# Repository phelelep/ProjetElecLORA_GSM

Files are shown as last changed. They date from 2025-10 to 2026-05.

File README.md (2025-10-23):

# 🐝 Ruche Connectée – Passerelle LoRa ↔ GSM

Projet réalisé dans le cadre du **cours de Projet d'Électronique** à **Polytech Nice Sophia Antipolis**,  
encadré par **M. Christian Peter** (*Christian.PETER@univ-cotedazur.fr*).

**Groupe :**  
- CEBAN Daniel — [ceban.daniel@etu.univ-cotedazur.fr] 
- MIRRIONE Xavier  — [mirrione.xavier@etu.univ-cotedazur.fr]

---

## 🎯 Objectif du projet

Ce projet vise à concevoir une **ruche connectée** capable de :

- Collecter et transmettre à distance des données environnementales ;  
- Communiquer via une **passerelle LoRa ↔ GSM** ;  
- Intégrer des fonctions avancées comme **l’élimination des parasites par laser**.

Cette partie du projet se concentre sur **la communication à distance** des données.

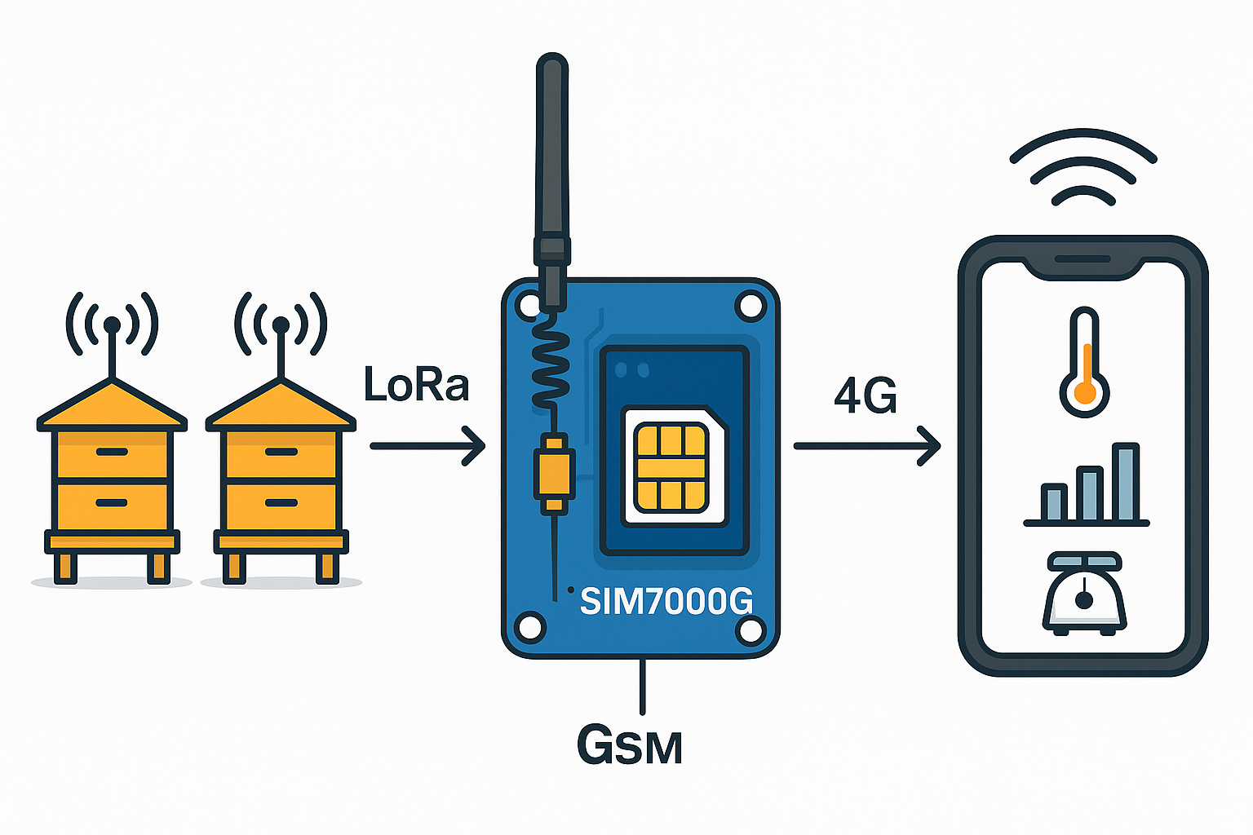
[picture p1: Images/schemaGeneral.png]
Schéma général projet


---

## Dossiers :
- 📁 CompteRendu_Daniel
- 📁 CompteRendu_Xavier
- 📁 Partie_Electronique
- 📁 Partie_Informatique

---

## GLOSSAIRE :

- GSM (Global System for Mobile Communications) :
C'est un standard de communication mobile utilisé pour la téléphonie cellulaire et la transmission de données. Il permet l’envoi de messages SMS, les appels et la connexion à Internet via GPRS/EDGE/3G/4G. Le GSM est largement utilisé pour les dispositifs IoT nécessitant une connectivité dans des environnements sans Wi-Fi.

- LoRa (Long Range) :
C'est une technologie de communication sans fil à longue portée et à faible consommation d'énergie, utilisée pour connecter des dispositifs IoT aux réseaux LPWAN (Low Power Wide Area Network). LoRa permet de transmettre de petits paquets de données sur de longues distances (jusqu'à 15 km en zones rurales) avec une consommation d’énergie minimale.

- ESP32 :
C'est un microcontrôleur développé par Espressif, intégrant Wi-Fi et Bluetooth, ainsi que plusieurs broches GPIO pour les capteurs et modules externes. Il est largement utilisé dans les projets IoT grâce à sa connectivité, sa puissance et son faible coût.
Il va nous permetre de récuperer les information des LoRa et les envoier vers le module GSM pour ensuite transmettre les information au utilisateur.

- SIM7000 :
C'est un module de communication GSM/GPRS/NB-IoT/LTE Cat-M1 développé par Simcom. Il permet aux dispositifs IoT d'envoyer et de recevoir des données via les réseaux mobiles, en prenant en charge les connexions basse consommation, idéales pour les capteurs distants et les applications de surveillance.

---

## 🧩 Technologies utilisées

- **ESP32** – Microcontrôleur principal du système.  
- **SIM7000G** – Module GSM / NB-IoT / LTE pour la communication mobile.  
- **LoRa** – Communication longue portée et faible consommation.  
- **TinyGSM** – Bibliothèque facilitant la communication série avec le SIM7000G.

---

## ⚙️ Fonctionnement général

1. Initialisation et configuration du modem GSM (SIM7000G).  
2. Connexion au réseau mobile via **APN SFR** (`sl2sfr`).  
3. Transmission ou test d’envoi de données / SMS.  
4. Préparation à l’intégration de la communication **LoRa** pour la collecte distante.  

---

## Etapes du projet 

### 🚧 Etape 1:
- Analyse du projet existant et definier les tacher pour continuer le projet. Repartition des taches dans le groupe 

---

## 💡 Référence du projet précédent

Ce projet est basé sur le travail de la promotion précédente :  
**Oumar Sadjo Barry** & **Mor Dieng** – *RucherLoRa*  
- Guilherme Ventapane Rodrigues — [guilherme@ventapane.eu](mailto:guilherme@ventapane.eu)  
- Jarod Lecoeuvre — [jarod.lecoeuvre@etu.univ-cotedazur.fr](mailto:jarod.lecoeuvre@etu.univ-cotedazur.fr)

---

## 🧠 Encadrant

**M. Christian Peter**  
_Enseignant – Département Électronique & Informatique Industrielle_  
[Christian.PETER@univ-cotedazur.fr](mailto:Christian.PETER@univ-cotedazur.fr)

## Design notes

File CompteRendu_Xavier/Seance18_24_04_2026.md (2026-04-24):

# CR - MIRRIONE Xavier  
## Séance 18 du 24/04/2026  

## Reception de la carte
La carte PCB avait été commandée le 11 avril 2026. Elle a bien été reçue, désormais il faut passer à la disposition des composants sur la PCB pour la passer au four et ainsi souder les MCS avec la pate prévue à cet effet. 

Listes des composants posés : 
- C8 10µF et C7 100nF
- ESP32 et LoRa 
- C1, C3 100nF et C2 47µF
- C16 4,7µF et C17 100nF
- R1, R2, R3, R4, R5, R6 100kOhms 
- R21 4,7kOhms 
- R23 150 Ohms et R25 100 Ohms
- R22 1MOhms 
- Q2 et Q4 BSSS131
- BTN RST et PROG
- Q1 et Q3 Si2305
- Soudure DIO1 au GPIO32 avec le jumper

## Test Carte 
Le LoRa et son programme ont été testé, tout est fonctionel. 
### Prochaine séance 
Désormais pour la dernière séance il faut tester le Module GSM, piloter le module  SIM7000 avec le pin 34 CMD_ALIM(SIM) et le mettre à 0. Pour ensuite brancher le 5V.

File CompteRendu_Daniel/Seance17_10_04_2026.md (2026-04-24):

# 📝 Compte Rendu — CEBAN Daniel  
## Séance 17 du 10/04/2026

## objectifs de la séance 

1. Réveiller l'ESP32 lorsque LoRa réceptionne un message
2. Intégration du module SIM7000 au reste du montage

## Étapes de la séance : 

## Etape 1 : réveil via DIO1 

Le problème, c'est qu'après endormissement, l'ESP32 ne se réveille jamais.
```text

LoRa initialized SUCCESSFULLY!
Listening... ESP32 will sleep after 10s of inactivity

[INFO] 10 seconds inactivity → Entering Deep Sleep...
```

On va changer le mode d'endormissement 

On va passer en deep sleep mode 
```cpp
esp_sleep_enable_ext0_wakeup((gpio_num_t)LORA_DIO1, HIGH);
esp_deep_sleep_start();             // L'ESP32 s'endort ici
```
Au light sleep mode 

```cpp
esp_sleep_enable_gpio_wakeup();
gpio_wakeup_enable((gpio_num_t)LORA_DIO1, GPIO_INTR_HIGH_LEVEL);
esp_light_sleep_start();
```

### problème numéro 1 

La ligne int rxState = radio.receive(received); est bloquante.
Par défaut, cette fonction attend qu'un paquet arrive ou qu'un "timeout" interne survienne (souvent plusieurs secondes). Tant que cette fonction n'a pas fini, ton test if (millis() - lastRxTime >= INACTIVITY_TIMEOUT) n'est jamais exécuté. Le processeur est "coincé" dans la lecture radio au lieu de vérifier le chrono.

### solution 
```cpp
  int rxState = radio.receive(received, 0); // 0 time interrupt
```

### problème numéro 2 

Le problème : Les GPIO 34, 35, 36 et 39 de l'ESP32 sont des entrées seules qui n'ont pas de résistances de pull-down internes.

Conséquence : Ta pin est "flottante"
### Solution 
```cpp
#define LORA_NSS 5
#define LORA_DIO1 32  
#define LORA_NRST 27
#define LORA_BUSY 33  
```

### Résultat -> toujours pas de réveil avec LoRa

## Etape 2 : 

On va forcer le pin DIO1 à HIGH avec un câble pour tester si une impulsion sur ce pin réveille bien le module ESP32

Et on arrive à réveiller l'ESP32 avec une impulsion sur le pin GPIO32 (DIO1) 
Donc le problème, c'est le module LoRa qui n'envoie pas d'impulsion sur le DIO1 lors de la réception du message
```text
=== MESSAGE RECEIVED ===
Msg : Hello from Heltec #138 - 2070s
RSSI: -83.00 dBm
SNR : 10.75 dB

[INFO] 10 seconds inactivity → Entering Deep Sleep...

Waked-up after a light sleep!!!

=== MESSAGE RECEIVED ===
Msg : Hello from Heltec #138 - 2070s
RSSI: -83.00 dBm
SNR : 10.75 dB
```

## Etape 3 : Visualiser les signaux à l'aide de l'oscilloscope

1. En visualisant le pin DIO1 de la LoRa sur l'oscilloscope lors de la transmission du message, on remarque qu'il n'y a aucune variation de la tension. Ce qui explique le problème, puisque l'on s'attendait à avoir une interruption sur le DIO1 pour réveiller l'ESP32.

3. Visualisation du pin BUSY sur l'oscilloscope : et cette fois, on voit bien une variation du signal lors de la réception du message. 

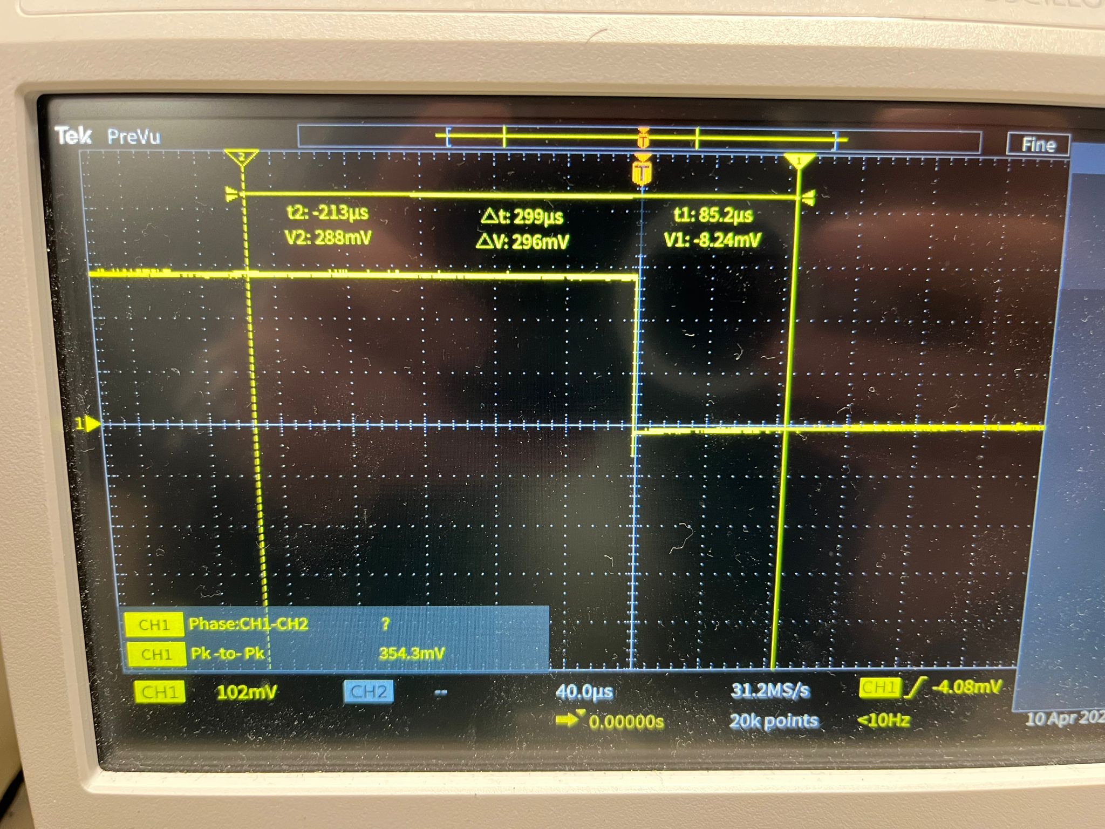
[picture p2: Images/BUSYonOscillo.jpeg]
le pin BUSY sur l'oscilloscope lors de la réception d'un message


DIO1 (Le signal d'événement) : C'est le seul pin capable de signaler une réception de paquet (RxDone). S'il ne bouge pas, ce n'est pas parce qu'il est défectueux, c'est parce que le module n'a pas reçu l'ordre de mapper l'interruption sur ce pin.

Le danger : Utiliser BUSY pour réveiller l'ESP32 ne marchera pas en mode sommeil car, sans activité SPI de l'ESP32, le module n'a aucune raison de passer en état "Busy" (occupé), même s'il reçoit un signal radio.

## Etape 4 : 

1. Quand l’ESP32 est éveillé → le module LoRa montre des variations sur BUSY lors de la réception → tout va bien.
2. Après 10 secondes → l’ESP32 entre en sommeil.
3. Une fois l’ESP32 endormi → plus aucune variation sur BUSY, même si tu envoies un message depuis l’autre module.

-> Le module LoRa perd (ou met en pause) sa configuration lorsque l’ESP32 est en Deep Sleep / Light Sleep.

### Conclusion 

En fait, on a oublié de calibrer le pin DIO1

et d'activer l'interruption 

```cpp

radio.startReceive(RADIOLIB_SX126X_RX_TIMEOUT_INF);
```

## Etape 5 : BINGO!!!

En modifiant le code, on arrive bien à endormir et réveiller l'ESP32 lors de la réception d'un message

```text

=== MESSAGE RECEIVED ===
Msg : Hello from Heltec #64 - 640s
RSSI: -82.00 dBm
SNR : 10.25 dB

[INFO] Inactivité -> Nettoyage et Sommeil...
ESP32 part en sommeil léger. DIO1 devrait rester à 0V...

[SYSTEM] RÉVEIL DÉTECTÉ !

=== MESSAGE RECEIVED ===
Msg : Hello from Heltec #65 - 650s
RSSI: -80.00 dBm
SNR : 10.50 dB
```

Le module LoRa n'était pas correctement configuré juste avant la mise en sommeil de l'ESP32. Plus précisément, le mappage de l'interruption de réception n'était pas forcé sur la pin physique DIO1. De plus, sans un paramètre de timeout infini, le module cessait d'écouter ou levait une erreur de timeout avant l'arrivée d'un message. Résultat : aucune impulsion n'était envoyée sur DIO1 lors de la réception d'un paquet, et l'ESP32 ne recevait jamais le signal électrique nécessaire pour se réveiller

Il est crucial de forcer le signal DIO1 à 0 (état bas) avant l'endormissement (via une commande standby ou un nettoyage des interruptions). Si DIO1 est déjà à 1 au moment où l'ESP32 s'endort, celui-ci ne pourra pas détecter le front montant (le passage de 0 à 1) provoqué par un nouveau message, rendant le réveil impossible.

### Liste de corrections 

1. Mapping matériel : Obligation de lier l'événement "Message reçu" à la broche physique DIO1 avant de couper le SPI.

2. Écoute permanente : Utilisation du mode RX Infini pour éviter que le module ne lève un "faux" signal de timeout qui saturerait la pin.

3. État de repos : Garantie que DIO1 est bien à 0V au repos pour que l'impulsion de 3.3V soit détectable par l'ESP32 comme un événement de réveil.

#### Le code qui fonctionne pour la mise en sommeil 

```cpp
 if (millis() - lastRxTime >= INACTIVITY_TIMEOUT) 
  {
    Serial.println("\n[INFO] Inactivité -> Nettoyage et Sommeil...");
    
    // 1. On s'assure que DIO1 est bien à 0 avant de partir
    radio.standby(); 
    radio.clearDio1Action(); // On enlève l'action actuelle

    // 2. On reconfigure DIO1 pour qu'il ne réagisse QU'AU MESSAGE reçu
    // On ne passe PAS de fonction callback ici pour éviter les conflits au réveil
    // On demande au module de rester en RX permanent
    radio.startReceive(RADIOLIB_SX126X_RX_TIMEOUT_INF);

    delay(100);
    Serial.flush();

    // 3. Configuration du réveil ESP32
    esp_sleep_enable_gpio_wakeup();
    gpio_wakeup_enable((gpio_num_t)LORA_DIO1, GPIO_INTR_HIGH_LEVEL);

    Serial.println("ESP32 part en sommeil léger. DIO1 devrait rester à 0V...");
    esp_light_sleep_start();

    // --- AU RÉVEIL ---
    Serial.println("\n[SYSTEM] RÉVEIL DÉTECTÉ !");
    // On remet l'action pour le loop
    radio.setDio1Action(onPacketReceived); 
    lastRxTime = millis();
  }
```

## Tableau récapitulatif de connectivité (pratique)

| Composant A | Pin A | Composant B | Pin B | Interface |
|---|---|---|---|---|
| ESP32 WROOM | GPIO23 | LoRa LLCC68 | MOSI | SPI |
| ESP32 WROOM | GPIO19 | LoRa LLCC68 | MISO | SPI |
| ESP32 WROOM | GPIO18 | LoRa LLCC68 | SCK | SPI |
| ESP32 WROOM | GPIO5 | LoRa LLCC68 | NSS/CS | SPI |
| ESP32 WROOM | GPIO27 | LoRa LLCC68 | NRST | Contrôle |
| ESP32 WROOM | GPIO32 ou GPIO34 ou GPIO36 | LoRa LLCC68 | DIO1 | IRQ / réveil |
| ESP32 WROOM | GPIO33 ou GPIO35 (tests aussi 36/39/32/25) | LoRa LLCC68 | BUSY | État module |
| ESP32 WROOM | GPIO17 (TX) | SIM7000 | RX | UART |
| ESP32 WROOM | GPIO16 (RX) | SIM7000 | TX | UART |
| ESP32 WROOM | GPIO13 ou GPIO4 | SIM7000 | PWRKEY | Contrôle alim |
| ESP32 WROOM | GPIO25 | SIM7000 | DTR | Gestion modem |
| ESP32 WROOM | 5V/VIN et GND | SIM7000 | VCC et GND | Alimentation |
| ESP32 WROOM | 3.3V et GND | LoRa | VCC et GND | Alimentation |

## Prochain objectif 

1. Nettoyer le code
2. Essais avec le mode **deep sleep** (actuellement on est en mode light_sleep)
2. intégrer le SIM7000G au reste du montage pour faire la chaîne de communication complète

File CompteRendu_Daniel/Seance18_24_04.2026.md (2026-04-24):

# 📝 Compte Rendu — CEBAN Daniel  
## Séance 18 du 24/04/2026

## Objectifs de la séance 

1. Nettoyer le code.
2. Essais avec le mode **deep sleep** (actuellement on est en mode light_sleep).
3. Intégrer le module SIM7000G au reste du montage pour faire la chaîne de communication complète.
4. Test avec la connexion 4G/GSM.

## Étapes de la séance 

## Étape 1 : Test en mode Deep Sleep
Antérieurement nous avons testé le mode `light_sleep`. Maintenant, nous allons passer au mode `deep_sleep` pour économiser davantage d'énergie lors de l'endormissement. On se rapproche ainsi de l'objectif final du projet (optimisation maximale de la consommation).

Lors de la configuration du deep sleep, nous rencontrons un problème :

```text
=== ESP32 <-> LoRa LLCC68 - Wake-up   ===

begin() attempt 1 = -707
begin() attempt 2 = 0
LoRa initialized SUCCESSFULLY!
Listening... ESP32 will sleep after 10s of inactivity

[INFO] Inactivité -> Configuration Deep Sleepou...
ESP32 entering DEEP SLEEP mode... 
ets Jun  8 2016 00:22:57

rst:0x5 (DEEPSLEEP_RESET),boot:0x13 (SPI_FAST_FLASH_BOOT)
configsip: 0, SPIWP:0xee
clk_drv:0x00,q_drv:0x00,d_drv:0x00,cs0_drv:0x00,hd_drv:0x00,wp_drv:0x00
mode:DIO, clock div:1
load:0x3fff0030,len:4744
load:0x40078000,len:15672
```
Lorsque l'ESP32 passe en mode deep sleep, sa sortie de veille effectue un redémarrage (*reboot*) complet. Le message qui a permis de réveiller l'ESP32 n'est donc pas interprété par celui-ci pendant qu'il boot, il est donc perdu. 

**Solution** : Configurer l'autre nœud LoRa (le module HELTEC) pour envoyer un message de réveil (*wake-up*) qui ne contient pas d'information pertinente. Cela permettra juste de réveiller le module ESP32 de l'autre côté par interruption matérielle. 

Ensuite, après un délai, le module HELTEC va envoyer le paquet d'informations cruciales. 

Comme l'initialisation du module LoRa + ESP32 prend environ 2 à 3 secondes après le réveil, nous allons espacer le message de réveil et le message important de 5 secondes pour être sûrs de ne rien rater.

### BINGO !!!

Messages envoyés par l'ESP1 (HELTEC) :
```text
=== Heltec WiFi LoRa 32 V2.1 - Bidirectionnel ===
LoRa initialized successfully !
Envoi toutes les xs + écoute permanente

TX #1 → Wakeup from Heltec #1 - 20s
TX #1 → Hello from Heltec #1 - 25s
→ Envoi OK
```

Messages réceptionnés par l'ESP32 (WROOM) :
```text
=== ESP32 <-> LoRa LLCC68 - Wake-up   ===

begin() attempt 1 = -707
begin() attempt 2 = 0
LoRa initialized SUCCESSFULLY!
Listening... ESP32 will sleep after 10s of inactivity

=== MESSAGE RECEIVED ===
Msg : Hello from Heltec #4 - 85s
RSSI: -74.00 dBm
SNR : 11.00 dB

load:0x40080400,len:3152
entry 0x4008059c

=== ESP32 <-> LoRa LLCC68 - Wake-up   ===

begin() attempt 1 = -707
begin() attempt 2 = 0
LoRa initialized SUCCESSFULLY!
Listening... ESP32 will sleep after 10s of inactivity

=== MESSAGE RECEIVED ===
Msg : Hello from Heltec #5 - 105s
RSSI: -75.00 dBm
SNR : 9.75 dB
```

## Étape 2 : Nettoyage du code
*(À documenter selon les avancées)* 
Nous allons retirer la partie du code qui n'est plus nécessaire et améliorer les messages de log (`print`).

## Étape 3 : Intégration du SIM7000G pour tester la chaîne complète de communication

| Broche ESP32 (WROOM) | Broche SIM7000G | Description de la connexion |
| :--- | :--- | :--- |
| **VIN / 5V** (ou Externe)| **VCC / VIN** | **Alimentation :** Le SIM7000G nécessite une alimentation capable de fournir des pics de courant importants (jusqu'à 2A). SIM7000G elle-même fonctionne techniquement entre 3.0V et 4.3V.s |
| **GND** | **GND** | **Masse commune :** Très important pour unifier les références de tension entre l'ESP32 et le module SIM, surtout si vous utilisez une alimentation externe. |
| **GPIO 16** (RX2) | **TXD** (TX) | **Transmission de données (SIM $\rightarrow$ ESP) :** La broche de réception matérielle (Serial2) de l'ESP32 lit les données envoyées par la broche de transmission du SIM7000G. |
| **GPIO 17** (TX2) | **RXD** (RX) | **Réception de données (ESP $\rightarrow$ SIM) :** La broche de transmission matérielle (Serial2) de l'ESP32 envoie les commandes (AT commands) à la broche de réception du SIM7000G. |
| **GPIO 4** (ou autre) | **PWRKEY** | **Contrôle d'alimentation / Allumage :** Permet à l'ESP32 d'allumer ou d'éteindre le SIM7000G de manière logicielle. Il faut généralement maintenir cette broche à l'état HAUT ou BAS (selon le module) pendant environ 1 seconde pour le démarrer. |
| *Optionnel* (ex: GPIO 5)| **RST** | **Reset (Réinitialisation) :** Permet un redémarrage forcé du modem SIM7000G par l'ESP32 en cas de plantage logiciel. |

### Points d'attention  :
1. Le SIM7000G peut consommer beaucoup d'énergie lors de la connexion au réseau cellulaire. Si l'alimentation chute, le module redémarrera en boucle.
2. L'ESP32 fonctionne en logique **3.3V**. La plupart des modules (breakouts) SIM7000G ont des adaptateurs de niveau logique intégrés. Si votre module SIM fonctionne en logique 5V sans adaptateur, il faudra un *Level Shifter* (convertisseur de niveau logique) sur les broches RX/TX pour ne pas endommager l'ESP32.
3. L'ESP32 dispose de 3 ports série matériels (Hardware Serial). Il est conseillé d'utiliser le `Serial2` (broches 16 et 17) pour le SIM7000G, afin de garder le `Serial0` libre pour le moniteur ordinateur (debogage).

On arrive faire communiquer le ESP32 WROOM et le module SIM7000G
le SIM7000 fonctionne 

```text

--- INFOS DIAGNOSTIC GPRS ---
CCID : 89331054212022311459
IMEI : 869951037002734
Opérateur : SFR
IP locale : 3709934858
Qualité du signal : 99
--- FIN INFOS GPRS ---
```

## Étape 4 : Tests sur la carte électronique 

Mon collègue travaillant en parallèle a conçu la carte électronique (PCB) en reprenant les mêmes broches et la même logique que dans notre montage de test.

Tests avec le PCB imprimé :

### Dépôt de la pâte à braser

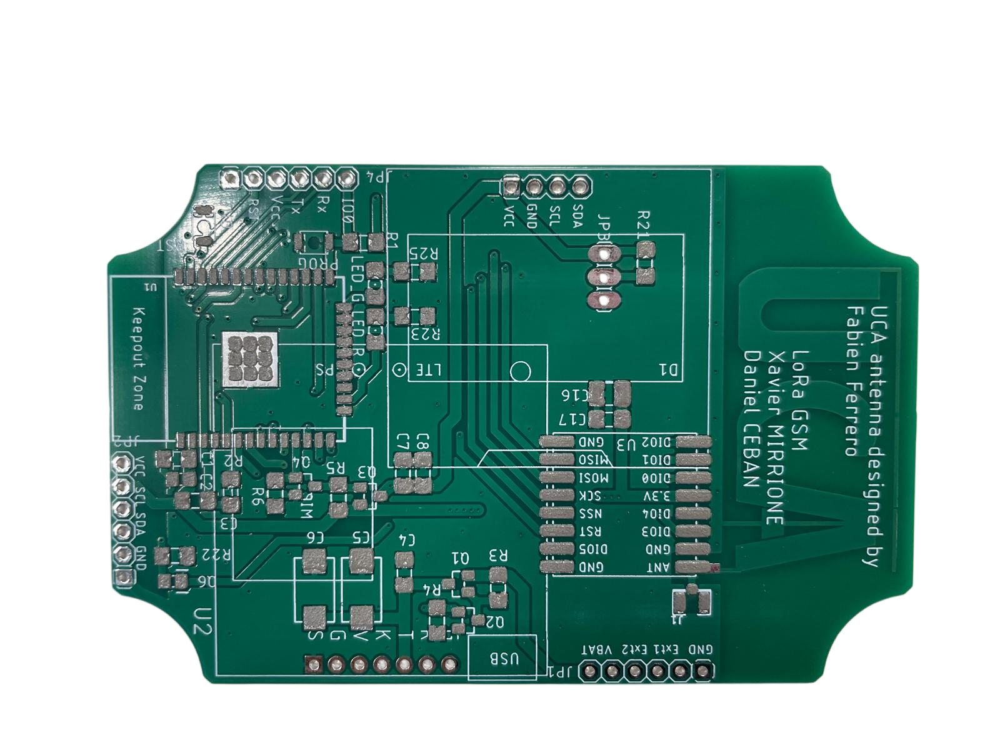
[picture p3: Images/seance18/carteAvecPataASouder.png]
Mise de la pate à souder


### Mise en place des composants
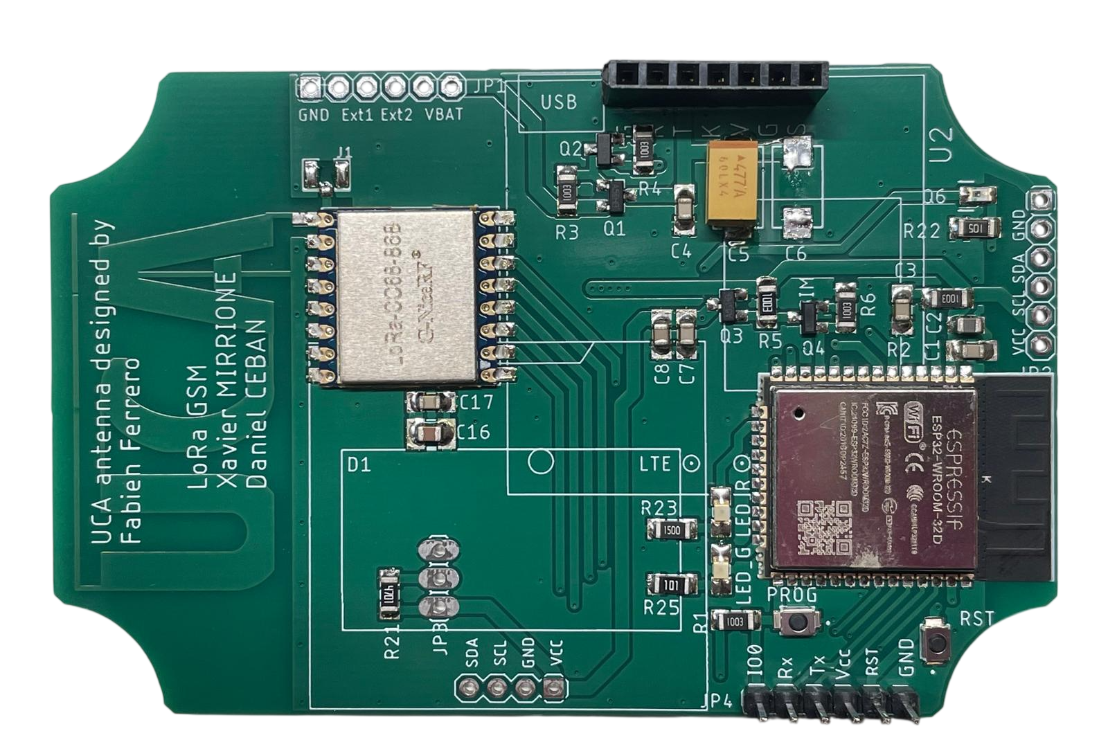
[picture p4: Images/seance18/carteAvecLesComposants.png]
Mise en place de composant


### Passage au four à refusion 
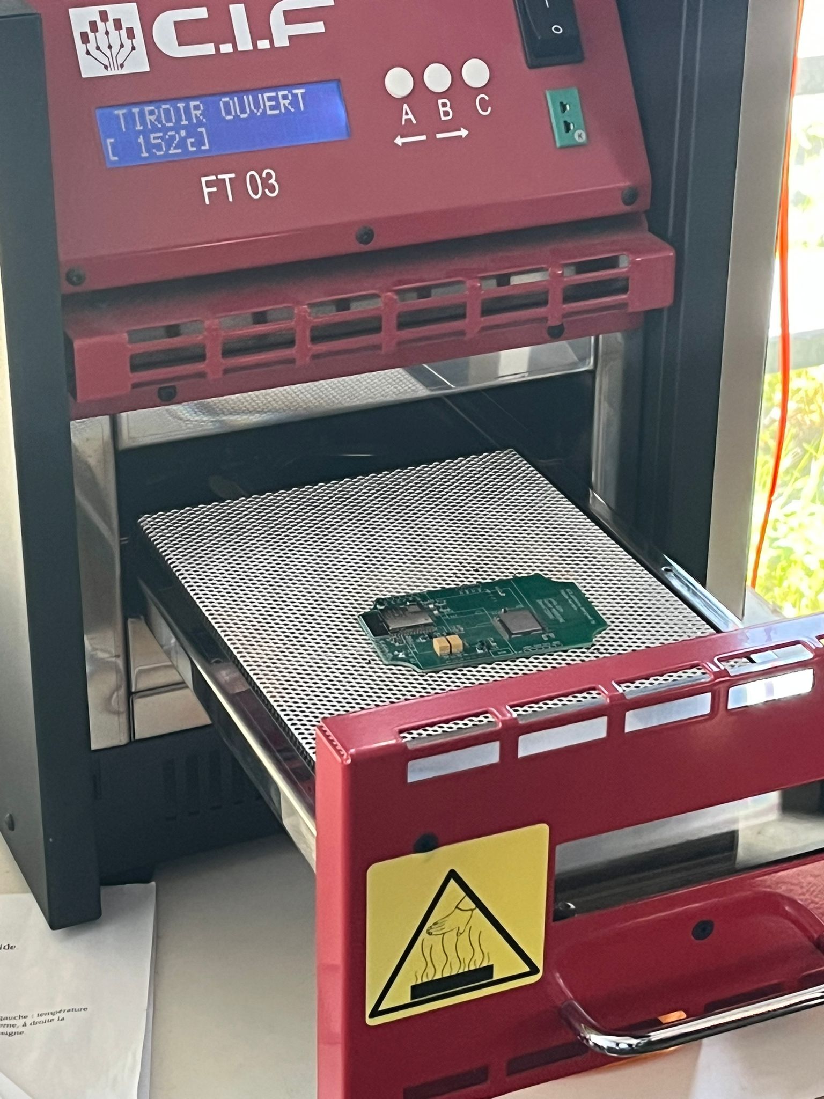
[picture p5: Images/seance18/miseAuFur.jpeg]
Mise de la pate à souder


### Test de la partie LoRa (Succès !) 
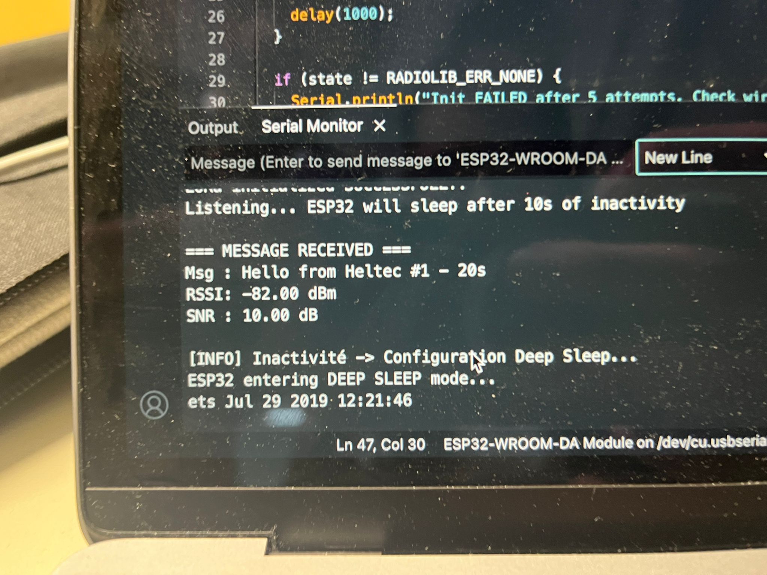
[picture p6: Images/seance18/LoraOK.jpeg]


Nous arrivons bien à réveiller et endormir l'ESP32. Nous considérons donc que la partie LoRa est validée sur la carte. 
Il nous restera par la suite la partie modem GSM à intégrer. 
Celle-ci nécessitant plus de courant, et sachant que nous avons mis en place une broche `ALIM_COMMAND` qui va gérer l'allumage physique, nous devons encore adapter notre alimentation et notre code pour la tester en conditions réelles. 

# Conclusion / Remarques 

- **Partie LoRa fonctionnelle dans son intégralité** sur le PCB $\rightarrow$ OK.
- Il reste à alimenter proprement la partie SIM7000G et à utiliser la broche `ALIM_COMMAND` pour démarrer le modem GSM (au lieu de tirer sur `PWRKEY` comme sur les tests de développement actuels).

Il faudra par la suite fusionner (concaténer) les deux codes :
- Celui qui gère la communication LoRa (sommeil/réveil + réception).
- Celui qui gère la partie modem SIM7000G (envoi HTTP/Mqtt sur le réseau 4G/GSM).

Le plus gros du travail de recherche et de conception étant terminé, et sachant que la partie LoRa matérielle fonctionne, il reste relativement peu de choses pour certifier la partie Modem sur la nouvelle carte. 
Puisque la chaîne de communication complète a d'ores et déjà été testée et validée sur breadboard avec chaque composant individuel, nous sommes confiants quant au bon fonctionnement final du projet. 

Le temps imparti au projet touchant à sa fin, nous concluons nos travaux ici, en espérant que la documentation et les bases solides laissées permettront à une future équipe de reprendre notre projet et de le mener à son terme sans difficulté.

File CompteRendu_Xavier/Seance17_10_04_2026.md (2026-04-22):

# CR - MIRRIONE Xavier  
## Séance 17 du 10/04/2026  

## Routage de la carte
Le routage est terminé ! Tout à été ajusté dont la taille des routes, à 50 mils et non 50 mm. (50 mils = 1,27mm) 

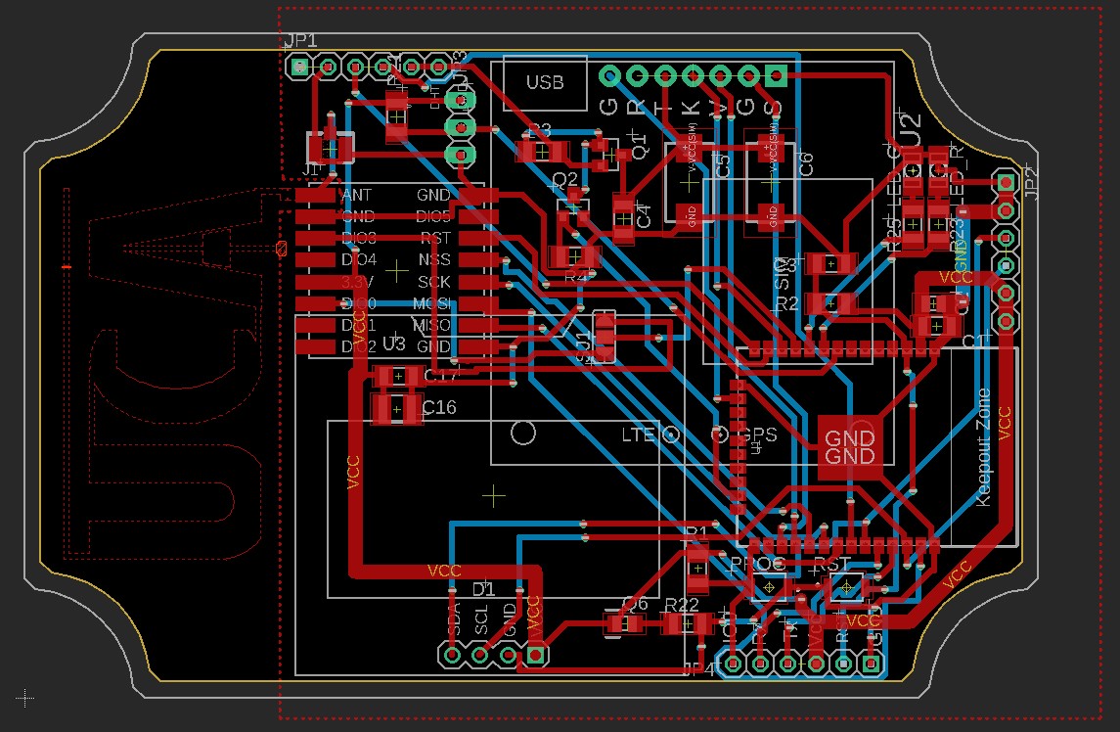
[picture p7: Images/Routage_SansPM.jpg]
Connection des JP1 et JP2


De nombreuses contraintes ont du être respectés, notammement la proximité des condensateurs afin d'éviter toutes perturbation et stabilité de la tension de l'esp32. Mais encore le Lora proche de l'antenne. 

Le projet Eagle va être envoyé au professeur. Il effectuera le plan de masse, et la commande sera faite. D'ici le prochain cours (24 Avril 2026) nous allons pouvoir peut être recevoir la carte PCB. 

Nous réflechissons. Il ne reste que 2 séances il va falloir préparer la soutenance ainsi que le rapport.
Le routage et le schematic vont devoir être ajoutés au dépot github du projet Gateway Lora-GSM.

Les pins doivent être vérifiés avec ceux utilisés expérimentalement par mon camarade. Il n'a fait fonctionné les deux modules qu'individuellement pour le moment et non ensemble.

### Prochainement

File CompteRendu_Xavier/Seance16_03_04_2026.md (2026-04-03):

# CR - MIRRIONE Xavier  
## Séance 16 du 03/04/2026  

## Routage de la carte
Comme spécifié lors de la précédente séance, les dimensions sont les suivantes : 
- 32 mm pour tout
- 50 mm pour l'alim VCC 3V3

Le routage a bien avancé, je vais devoir le finaliser à la maison. Une fois celui-ci terminé je le présenterai au professeur afin de le valider.

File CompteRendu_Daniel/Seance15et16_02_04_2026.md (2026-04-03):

# 📝 Compte Rendu — CEBAN Daniel  
## Séance 15 du 02/04/2026

## Objectif de la séance
1. Tester la communication bidirectionnelle avec 2 ESP32 et leur LoRa.
2. Faire réveiller le module ESP32 avec le module LoRa.
3. Intégrer le module SIM7000 pour envoyer des messages reçus par LoRa vers un téléphone ou un site Internet.

## Étapes de la séance

## Étape 1 : tester la communication bidirectionnelle avec 2 modules ESP32 et leur LoRa

Étapes pour tester :
On va charger exactement le même code sur les deux ESP32 avec leur LoRa.
On va utiliser 2 PC et regarder ce qu'ils envoient et reçoivent sur le Serial Monitor des deux.

Pour un premier test, on va être à une distance entre les deux ESP < 30 cm, puis on va s'éloigner pour voir la distance maximale à laquelle les deux modules reçoivent l'information.

### Problème :
En utilisant **Heltec WiFi LoRa 32**, on n'arrive pas à communiquer avec le composant LoRa à l'intérieur de l'ESP32.
Donc, on va devoir changer et adapter le code pour **Heltec WiFi LoRa 32 V2.1**, qui possède un composant LoRa de type
**SX1276/SX1278**
donc pas compatible avec la bibliothèque <RadioLib.h> ; on va passer à nouveau à la bibliothèque <LoRa.h> et tester.

Avec la bibliothèque <LoRa.h>, on arrive bien à communiquer avec la partie LoRa du module **Heltec WiFi LoRa 32 V2.1**.

## Et BINGO !!!

En allumant les 2 modules :
1. **Heltec WiFi LoRa 32** avec la librairie <LoRa.h>
2. **ESP32 - WROOM** avec la librairie <RadioLib.h>

on arrive à envoyer et réceptionner les messages provenant de l'autre.

```text
-------------------
TX → Test #78 - 567s
→ Envoi OK

RX #38 :
  Message reçu : Hello from Heltec #38 - 190s
  RSSI : -70.00 dBm
  SNR  : 10.00 dB
-------------------
TX → Test #85 - 602s
→ Envoi OK

RX #39 :
  Message reçu : Hello from Heltec #39 - 195s
  RSSI : -70.00 dBm
  SNR  : 10.00 dB
-------------------
TX → Test #86 - 607s
→ Envoi OK

...

RX #6 :
  Message reçu : Hello from Heltec #123 - 615s
  RSSI : -74.00 dBm
  SNR  : 10.25 dB

```

## Étape 2 : implémenter le réveil de l'ESP32 lorsque LoRa réceptionne un message

- Nouvelle implémentation dans le code :

1. Le module LoRa réveille l’ESP32 dès qu’un message arrive (via DIO1).
2. Si aucun message n’arrive pendant 10 secondes, l’ESP32 passe en Deep Sleep (très basse consommation).
3. Au réveil, il reprend l’écoute immédiatement.
4. Si la réception est réussie, il répond avec le numéro du message + "Réception réussie".

On va utiliser le pin GPIO36 pour réveiller l'ESP32.
```cpp
#define LORA_DIO1  36
```

On va ajouter une fonction pour traiter les messages reçus.

```cpp
  // Traitement du paquet si reçu
  if (packetReceivedFlag) {
    packetReceivedFlag = false;
    lastActivity = millis();

    String received = "";
    int rxState = radio.receive(received);

    if (rxState == RADIOLIB_ERR_NONE) {
      Serial.println("\n=== MESSAGE RECEIVED ===");
      Serial.print("Msg  : "); Serial.println(received);
      Serial.print("RSSI : "); Serial.print(radio.getRSSI()); Serial.println(" dBm");
      Serial.print("SNR  : "); Serial.print(radio.getSNR()); Serial.println(" dB");
      Serial.println("-------------------");
    }

    radio.startReceive();  
  }
```

Et une fonction qui va endormir l'ESP32 si les 10 s d'inactivité sont écoulées.

```cpp
 if (millis() - lastActivity >= INACTIVITY_TIMEOUT) {
    Serial.println("\n[INFO] 10 seconds inactivity → Entering Deep Sleep...");

    delay(100);
    Serial.flush();                     // Attendre que le message soit envoyé

    // Désactiver l'action DIO1 avant de dormir
    radio.clearDio1Action();

    // Configurer le wake-up sur DIO1 (niveau HIGH)
    esp_sleep_enable_ext0_wakeup((gpio_num_t)LORA_DIO1, HIGH);

    esp_deep_sleep_start();             // L'ESP32 s'endort ici
  }

```

## Étape 3 : explication du workflow
Le module LoRa (LLCC68) envoie lui-même l’impulsion sur DIO1 dès qu’il reçoit un message valide ; on va utiliser cela pour réveiller l'ESP32.

1. Le module LoRa reçoit un message (qui a été envoyé par une autre LoRa distante) -> le paquet arrive par antenne sur le module LLCC68.
2. Le module LoRa envoie une impulsion (signal) **automatique** sur DIO1 (GPIO 36).
3. L'impulsion réveille l’ESP32 -> parce qu’on a configuré esp_sleep_enable_ext0_wakeup() sur le GPIO36.
4. L’ESP32 traite le message
5. L’ESP32 redémarre le timer d’inactivité -> lastActivity = millis();
6. Si rien n’arrive pendant 10 secondes → L’ESP32 retourne en Deep Sleep.

## Next -> 

vérifier si le révil de ESP32 après la réception du message

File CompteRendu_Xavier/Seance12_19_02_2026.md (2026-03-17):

# CR - MIRRIONE Xavier  
## Séance 12 du 19/02/2026  

## Realisation du schematic

### Définition des pins ESP32 vers connector 1x7 SIM7000G

- VCC vers le 3V3.
- GND au GND.
- SLEEP --> IO2.
- PWRKEY --> IO27.
- TX --> IO17 (RX).  
- RX --> IO16 (TX).

1. Partie ESP32 nu et LoRa
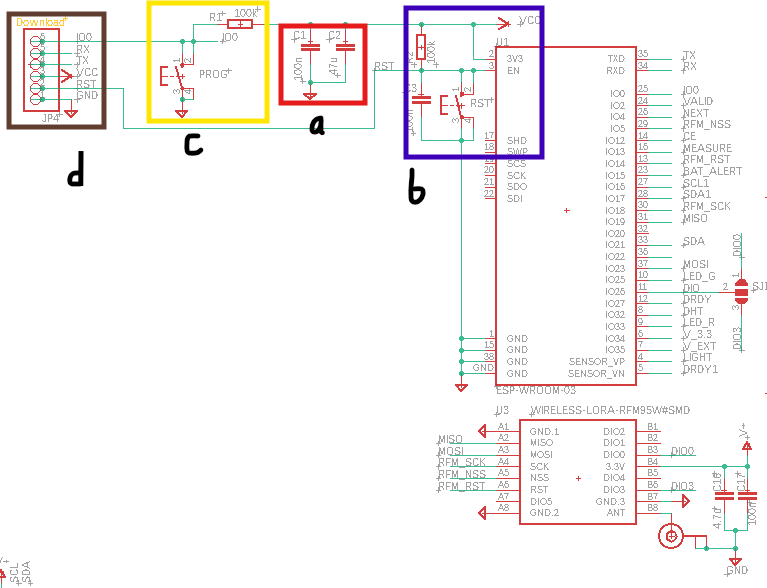
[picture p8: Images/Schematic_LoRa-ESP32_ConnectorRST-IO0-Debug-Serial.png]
Schéma général projet


a) Deux condensateurs de découplage sont placés entre l’alimentation 3,3 V et la masse GND : un 100 nF et un 47 µF. Le grand filtre les parasites haute fréquence et les transitoires rapides au plus près du module, tandis que le 47 µF sert de capacité réservoir pour limiter les chutes de tension lors des pics de courant. 
Ils réduisent l’impédance de l’alimentation et améliorent la stabilité du fonctionnement.

b)La broche EN de l’ESP32 est une entrée hardware d’activation : à l’état haut active le chip, tandis que EN à l’état bas le RESET. 
Pour garantir un démarrage fiable, EN ne doit pas être flottant (en l'air) et doit être validé après stabilisation du 3,3 V. 
On utilise donc un pull-up R2 vers VCC et un condensateur C3 vers la masse formant un RC de temporisation. À la mise sous tension, C3 est initialement déchargé et maintient EN bas brièvement, puis il se charge via R2 et EN monte au niveau haut après un délai de quelques ms. Le bouton RST force EN à 0 V pour réinitialiser manuellement le module et recommencer le processus de charge.

c) La broche IO0 de l’ESP32 est une broche de sélection de mode de boot lue au reset. Une résistance R1 (pull-up) la maintient à l’état haut par défaut afin d’assurer un démarrage normal. Le bouton PROG force IO0 à la masse lorsqu’il est pressé ; si IO0 est maintenu bas pendant un reset, l’ESP32 démarre en mode bootloader UART, ce qui permet le téléversement du programme.

d) Enfin le connecteur JP4 regroupe les signaux nécessaires à la mise au point : TX/RX pour la communication UART (téléversement via bootloader et debug par console série), IO0 pour forcer le mode programmation (BOOT) lorsqu’il est maintenu à 0 durant un reset, RST/EN pour réinitialiser le module, ainsi que VCC et GND pour l’alimentation et la référence de masse. L’interface série doit être utilisée en 3,3 V et les lignes UART sont connectées en croisant TX et RX entre l’adaptateur et la carte.

## Prochainement
- Ajouter un connecteur ou nous pourrons brancher directement le SIM7000G car celui-ci est trop difficile à souder 
- Voir et régler le problème dont ils avaient l'ancien groupe avec le LoRa

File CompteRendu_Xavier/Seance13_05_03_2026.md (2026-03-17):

# CR - MIRRIONE Xavier  
## Séance 13 du 05/03/2026  

## Ajustement et modification du schematic
Changement du pin sleep : IO2 à IO13

On a vérifié la documentation du SIM7000G, sa puce est alimentée en 3V3. Il n'est donc pas nécessaire de l'alimentée en 5V car c'est dans un seul cas d'utilisation alimenté via le module USB directement et non les broches/pins. DONC PAS BESOIN DE LEVEL SHIFTER comme l'ancien groupe avait fait. 

Ajout JP5 vers SIM7000G
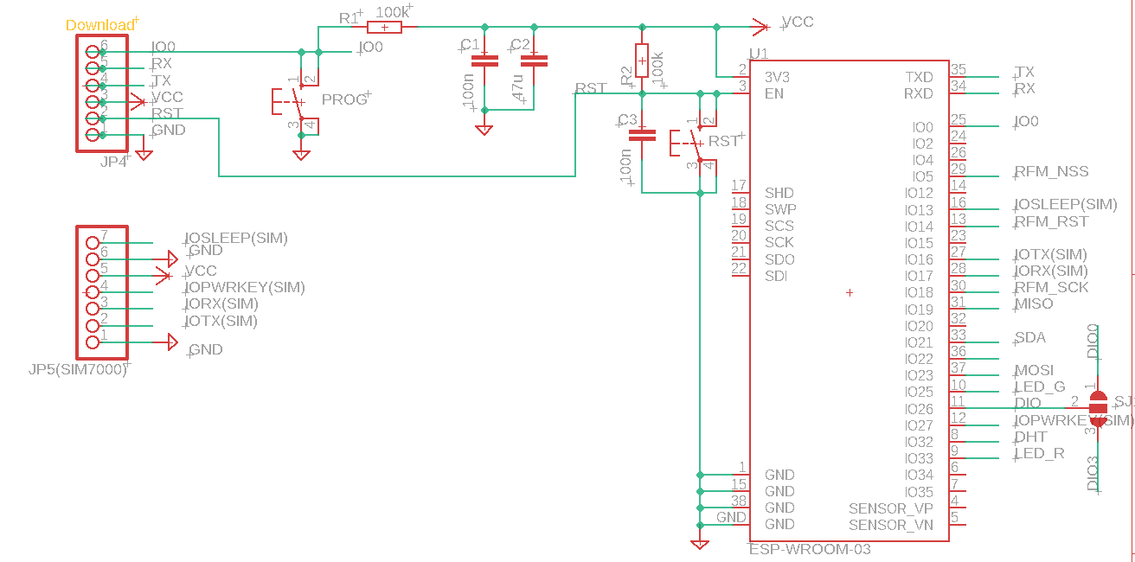
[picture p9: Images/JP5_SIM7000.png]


Dans la Data Sheet, il est spécifié que le mode sleep consomme 1.2 mA. Sur plusieurs heures, c'est conséquent alors afin de réduire sa consommation à zéro lorsqu'il n'est pas utilisé. Un circuit hardware supplémentaire et commandé par une port GPIO supplémentaire de l'ESP32.

Deux transistors Mosfets : 
- NMOS : BSS 131
- PMOS : SI2305

- réalisation du schéma : 
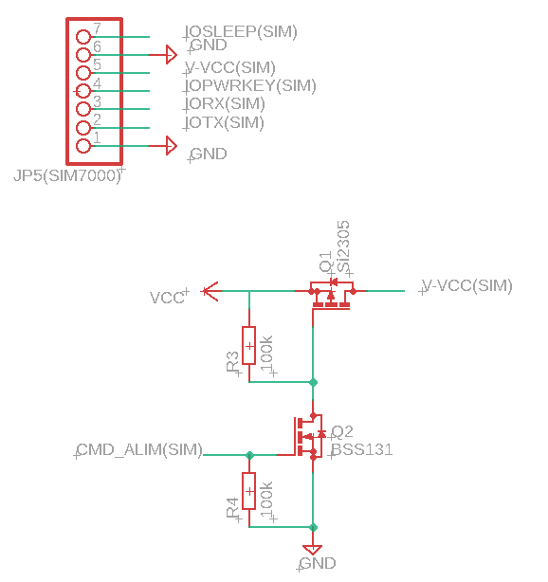
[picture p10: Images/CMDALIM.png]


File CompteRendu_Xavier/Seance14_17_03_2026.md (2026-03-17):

# CR - MIRRIONE Xavier  
## Séance 14 du 17/03/2026  

## Finalisation du schematic

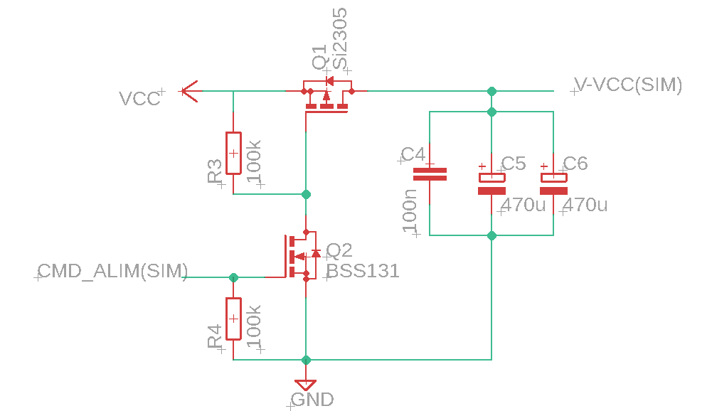
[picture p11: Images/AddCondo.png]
Condo ajout
- réalisation du schéma : 

Trois condensateurs de découplage ont été ajoutés pour le VCC du module SIM7000 afin d’assurer sa stabilité. Le condensateur de 100 nF filtre les perturbations haute fréquence, tandis que les deux condensateurs de 470 µF servent de réserve d’énergie pour absorber les pics de courant importants générés lors des transmissions. Ils permettent ainsi de limiter les chutes de tension transitoires et d’éviter les dysfonctionnements du module pour le protéger.

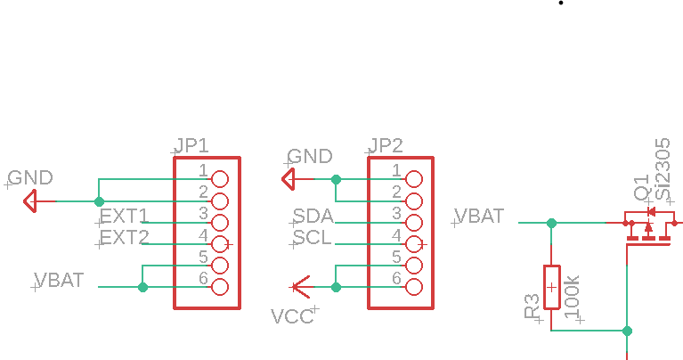
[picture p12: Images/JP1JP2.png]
Connection des JP1 et JP2

Afin d'accepter la futur présence de la batterie dans la cadre d'un jointement entre ce projet et le notre, les deux connecteurs JP1 et JP2 ont été réliés. 

Réalisation du schematic est terminée à 100%. Désormais il faut passer à la réalisation de la board tout en respectant certaines conditions qui seront détaillées lors du prochain rapport.

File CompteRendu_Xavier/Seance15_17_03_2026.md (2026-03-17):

# CR - MIRRIONE Xavier  
## Séance 15 du 17/03/2026  

## Installation EAGLE - License Student
Précédemment la version du logiciel intallé était Eagle via une license Free. Malheureusement la taille autorisée pour la modification et la réalisation du routage d'une board est limité en taille max d'un composant que l'on peut déplacer. 
Il a fallu installer de nouveau Fuzion, activer la license sudent afin de commencer le routage. 

## Conditions à respecter 
Comme expliqué dans les premiers rapports, un projet de batterie 3V3 d'une autre équipe sera utilisé comme source d'alimentation de notre carte pour le Lora-GSM

## Prise en main Eagle et disposition des composants
Il faut respecter la disposition des condensateur permettant d'éviter les chutes de tensions, C1, C2 doivent rester proche de l'esp tandis que C5,C6 proche de VCC du Sim7000G. 
Le professeur à effectuer une empreinte du SIM7000G afin d'imaginer la place qu'il pourrait prendre, une fois brancher au JP5.

La disposition des composants pour le routage est presque terminée.

### Pour la prochaine séance
Le routage va être fait : 
- 32 mm pour tout
- 50 mm pour l'alim VCC 3V3

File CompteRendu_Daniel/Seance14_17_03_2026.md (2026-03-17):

# 📝 Compte Rendu — CEBAN Daniel  
## Séance 14 du 17/03/2026

### Problématique
On n'arrive pas à communiquer avec le module **LoRa-CC68-868 G-NiceFR**.

### Objectif
Changer le module **LoRa-CC68-868 G-NiceFR** avec le module **LoRa RF96** et utiliser la bibliothèque `LoRa.h` et non `RadioLib.h`.

---

## Étapes de la séance 

### Étape 1 : Changement de la puce et intégration sur la breadboard

La plupart des pins restent à la même place, à part la pin BUSY qu'on enlève car on n'en a pas besoin.
La bibliothèque `LoRa.h` est conçue uniquement pour les puces de la famille SX127x.

#### Résultat : Échec !

```text
Test LoRa.h - SX127x seulement !
Échec LoRa.begin()
```

### Étape 2 : Retour au module initial

Le but est de tester `RadioLib.h` et d'enquêter davantage sur l'erreur -707.

Après vérification des pins et modification de certains branchements, on obtient toujours la même erreur -707. Les raisons suspectées sont :
- La patte **BUSY**
- La patte **DIO1**

En effet, en retirant ce branchement, on reçoit toujours l'erreur -707. Ce n'est pas le cas en retirant une autre patte : on reçoit alors l'erreur -2, ce qui indique que le module n'est pas du tout connecté.

#### Observations avec les différentes bibliothèques

**Avec `LoRa.h` et le module RF96 (type SX127x) :**
Le module LLCC68 ne répond pas. La fonction `begin()` ne renvoie aucun code d'erreur, ce qui rend difficile l'investigation ultérieure.

**Avec `RadioLib.h` :**
- Erreur -707 (SPI_CMD_FAILED) quand DIO1 + BUSY sont branchés
- Erreur -2 quand on enlève d'autres pins (NSS/NRST/SPI)

Cela signifie que la communication SPI de base fonctionne (la puce répond), mais une commande spécifique échoue pendant l'initialisation (calibration, configuration des IRQ ou contrôle du TCXO).

Les pattes BUSY et DIO1 sont bien connectées et les pins GPIO utilisés sont compatibles et vérifiés.

#### Autres causes possibles

1. **Alimentation bruitée** : Les puces LLCC68 sont très sensibles aux micro-défaillances de tension pendant les phases critiques de l'initialisation.
2. **Module défectueux**.

### Étape 3 : Vérification du pin BUSY 
On va tester si on peut forcer le pin busy à 1 pour voir s'il n'y a pas d'erreur du hardware ou dans le circuit 

On change le LORA_BUSY pin sur le GPIO33 qui peut être output aussi ça va nous permettre de le forcer à HIGH pour voir s'il change ou non 
```cpp
  pinMode(LORA_BUSY, OUTPUT); // GPIO33 output & input mode
// test high

  Serial.println("put busy to high...");
  digitalWrite(LORA_BUSY, HIGH);
  Serial.println(digitalRead(LORA_BUSY));
// test low
  Serial.println("put busy to low...");
  digitalWrite(LORA_BUSY, LOW);
  Serial.println(digitalRead(LORA_BUSY));
 
```

#### Résultat 

```text
set busy to high...
1
set busy to low...
0

Maintenant begin()...
begin() = -707
```

on arrive bien à changer le pin busy à 1.

#### Test avec différents paramètres 

on va changer la valeur de la tension tcxo 

```text
BUSY actuel : 0

[TEST 94] Test → Freq=867.0 MHz | BW=62.5 kHz | SF=7 | CR=4/5 | Sync=0x14 | Pwr=17 dBm | Preamble=12 | TCXO=1.6
Hard reset effectué
 → begin() = -8
Échec. Code = -8
BUSY actuel : 0

[TEST 95] Test → Freq=867.0 MHz | BW=62.5 kHz | SF=7 | CR=4/5 | Sync=0x14 | Pwr=17 dBm | Preamble=12 | TCXO=1.8
Hard reset effectué
 → begin() = -8
Échec. Code = -8
BUSY actuel : 0
```
Cependant, dans tous les tests, si la valeur de TCXO n'est pas 0.0f, on obtient un code d'erreur -8, ce qui signifie que ce paramètre n'est pas valide par la bibliothèque `RadioLib.h`.

```cpp

#include <RadioLib.h>

#define LORA_NSS   5
#define LORA_DIO1  36
#define LORA_NRST  27
#define LORA_BUSY  33

LLCC68 radio = new Module(LORA_NSS, LORA_DIO1, LORA_NRST, LORA_BUSY);

void setup() {
  Serial.begin(115200);
  delay(2000);

  pinMode(LORA_NRST, OUTPUT);
  pinMode(LORA_DIO1, INPUT);
  pinMode(LORA_BUSY, INPUT);

  Serial.println("\n=== Multiple LLCC68 begin() tests (10 cases) ===\n");

  // Reset once at beginning
  digitalWrite(LORA_NRST, LOW);
  delay(50);
  digitalWrite(LORA_NRST, HIGH);
  delay(500);
  Serial.print("BUSY after initial reset: "); Serial.println(digitalRead(LORA_BUSY));

  // --- 10 relevant test cases ---
  int testNum = 0;

  // Test 1: Safe default (most common working config)
  testNum++;
  Serial.print("\nTest "); Serial.print(testNum); Serial.println(": Safe default (BW125/SF9/CR7/TCXO0)");
  int state = radio.begin(868.0, 125.0, 9, 7, 0x12, 10, 8, 0.0f);
  Serial.print("begin() = "); Serial.println(state);
  Serial.print("BUSY now: "); Serial.println(digitalRead(LORA_BUSY));
  delay(1500);

  // Test 2: Same but LDO instead of DC-DC
  testNum++;
  Serial.print("\nTest "); Serial.print(testNum); Serial.println(": Same + LDO mode");
  state = radio.begin(868.0, 125.0, 9, 7, 0x12, 10, 8, 0.0f, false);
  Serial.print("begin() = "); Serial.println(state);
  delay(1500);

  // Test 3: TCXO 1.6 (just to confirm -8 again)
  testNum++;
  Serial.print("\nTest "); Serial.print(testNum); Serial.println(": TCXO 1.6 (should give -8)");
  state = radio.begin(868.0, 125.0, 9, 7, 0x12, 10, 8, 1.6f);
  Serial.print("begin() = "); Serial.println(state);
  delay(1500);

  // Test 4: Lower SF (SF7)
  testNum++;
  Serial.print("\nTest "); Serial.print(testNum); Serial.println(": SF7");
  state = radio.begin(868.0, 125.0, 7, 7, 0x12, 10, 8, 0.0f);
  Serial.print("begin() = "); Serial.println(state);
  delay(1500);

  // Test 5: Higher SF (SF11 – still valid for 125 kHz)
  testNum++;
  Serial.print("\nTest "); Serial.print(testNum); Serial.println(": SF11");
  state = radio.begin(868.0, 125.0, 11, 7, 0x12, 10, 8, 0.0f);
  Serial.print("begin() = "); Serial.println(state);
  delay(1500);

  // Test 6: Wider BW 250 kHz + SF9 (valid combo)
  testNum++;
  Serial.print("\nTest "); Serial.print(testNum); Serial.println(": BW250/SF9");
  state = radio.begin(868.0, 250.0, 9, 7, 0x12, 10, 8, 0.0f);
  Serial.print("begin() = "); Serial.println(state);
  delay(1500);

  // Test 7: BW500 + SF8 (valid)
  testNum++;
  Serial.print("\nTest "); Serial.print(testNum); Serial.println(": BW500/SF8");
  state = radio.begin(868.0, 500.0, 8, 7, 0x12, 10, 8, 0.0f);
  Serial.print("begin() = "); Serial.println(state);
  delay(1500);

  // Test 8: Different coding rate (4/8)
  testNum++;
  Serial.print("\nTest "); Serial.print(testNum); Serial.println(": CR=4/8");
  state = radio.begin(868.0, 125.0, 9, 8, 0x12, 10, 8, 0.0f);
  Serial.print("begin() = "); Serial.println(state);
  delay(1500);

  // Test 9: Different sync word (0x14)
  testNum++;
  Serial.print("\nTest "); Serial.print(testNum); Serial.println(": Sync=0x14");
  state = radio.begin(868.0, 125.0, 9, 7, 0x14, 10, 8, 0.0f);
  Serial.print("begin() = "); Serial.println(state);
  delay(1500);

  // Test 10: Longer preamble (12 symbols)
  testNum++;
  Serial.print("\nTest "); Serial.print(testNum); Serial.println(": Preamble=12");
  state = radio.begin(868.0, 125.0, 9, 7, 0x12, 10, 12, 0.0f);
  Serial.print("begin() = "); Serial.println(state);
  delay(1500);

  Serial.println("\n=== All 10 tests finished ===");
}

void loop() {
  // empty
}
```

### resultat du test 

```text
Test 1: Safe default (BW125/SF9/CR7/TCXO0)
begin() = -707
BUSY now: 0

Test 2: Same + LDO mode
begin() = -707

Test 3: TCXO 1.6 (should give -8)
begin() = 0

Test 4: SF7
begin() = -707
```

Bizarement on trouve pas d'erreur pour une valeur de TCXO 1.6F. 
On en conclut donc quenotre module  G-NiceRF LoRa-CC68-868 module a un TCXO (temperature-compensated crystal oscillator)
et il attend **1.6V sur le DIO3**

Cependant si on fait tourner le test 3 individuellement on trouve tujour l'erreur -707 ce qui est anormal.
en testant avec multiples valeur de TCXO on voit que l'initiliation à marche pour un valeur de TCXO de 1.8 et 2.4 

```text
=== Multiple LLCC68 begin() tests  ===
Test 1 : TCXO 1.6 
begin() = -707
Test 2: TCXO 1.8 begin() = 0
Test 3: TCXO 2.4 begin() = 0
Test 4: TCXO 0.0 begin() = -707
```

En retirant le test 1 qui teste que la valeur de 1.6 on obtien ce resultat 

```text
=== Multiple LLCC68 begin() tests  ===
Test 2: TCXO 1.8 begin() = -707
Test 3: TCXO 2.4 begin() = 0
Test 4: TCXO 0.0 begin() = -707
```

Le resultat n'est pas logique mais on peut supposer que lorsqu'on fait le test 1 avec 1.6V et on recoit l'erreur 707 ca permet au module de faire une configuration initiale même si l'erreur est de 707 ca parmet par la suite d'initialized le composant sans erreur 

pour tester ca on va executer 3 fois **le même test** avec une valeur de TCXO de 1.6 on s'addent a ce qu'on ait une erreur lors du premier test et pas d'erreur lors de 2 suivants 

```text
=== Multiple LLCC68 begin() tests  ===

BUSY after initial reset: 0
Test 1: TCXO 1.6 begin() = -707
Test 3: TCXO 1.6 begin() = 0
Test 4: TCXO 1.6 begin() = 0
```

C'est exactement le resultat qu'on attendant 

#### Pourquoi le premier appel à begin() avec TCXO = 1.6f échoue (-707), alors que le deuxième et le troisième réussissent (0) :
Le premier appel démarre à partir d’un état complètement inconnu ou non initialisé du circuit (après la mise sous tension ou un reset matériel).
Le composant LLCC68 a besoin que la tension du TCXO soit correctement configurée avant que l’oscillateur à quartz puisse se stabiliser et que la calibration puisse s’exécuter.
Lors de la première tentative, la bibliothèque essaie de configurer le TCXO à 1,6 V, mais l’oscillateur interne n’a pas encore démarré ou est dans un mauvais état → la commande de calibration échoue → renvoie -707.
Une fois qu’une première configuration réussit (le deuxième appel renvoie 0), le circuit est correctement initialisé (TCXO activé, oscillateur verrouillé, calibration effectuée).
Les appels suivants partent alors d’un état déjà correct → ils reconfigurent simplement les paramètres sans devoir refaire toute la séquence TCXO/calibration → ils réussissent immédiatement.

### Etape 4 : tester la reception et l'envoi des messages LoRa <-> ESP32

code pour INITIALISER -> envoyer -> ecouter les messages 
```cpp
#include <RadioLib.h>

#define LORA_NSS   5
#define LORA_DIO1  36
#define LORA_NRST  27
#define LORA_BUSY  33

LLCC68 radio = new Module(LORA_NSS, LORA_DIO1, LORA_NRST, LORA_BUSY);

unsigned long lastTx = 0;
const unsigned long TX_INTERVAL = 5000;  // send every 5 seconds

void setup() {
  Serial.begin(115200);
  delay(2000);

  pinMode(LORA_NRST, OUTPUT);
  pinMode(LORA_DIO1, INPUT);
  pinMode(LORA_BUSY, INPUT);

  Serial.println("\n=== Multiple LLCC68 begin() tests  ===\n");

  // Reset once at beginning
  digitalWrite(LORA_NRST, LOW);
  delay(50);
  digitalWrite(LORA_NRST, HIGH);
  delay(500);
  Serial.print("BUSY after initial reset: "); Serial.println(digitalRead(LORA_BUSY));

  int state= -1; 
  // tester jussq'au succes
  while (state != RADIOLIB_ERR_NONE)
  {
    state = radio.begin(868.0, 125.0, 9, 7, 0x12, 10, 8, 1.6f);
    Serial.print("begin() = "); Serial.println(state);
    if (state == RADIOLIB_ERR_NONE) 
      Serial.print("Initialization SUCCESS! - code : "); Serial.println(state);
    else 
       Serial.print("Init FAILED - code "); Serial.println(state);
    delay(1500);
  }

  // Start continuous receive mode
  radio.startReceive();
  Serial.println("Listening for packets...");
}

void loop() {
  // Send periodically
  if (millis() - lastTx >= TX_INTERVAL) {
    lastTx = millis();

    String message = "Hello from ESP32 at " + String(millis() / 1000) + "s";

    Serial.print("Sending: "); Serial.println(message);

    int state = radio.transmit(message);

    if (state == RADIOLIB_ERR_NONE) {
      Serial.println("→ Sent OK");
    } else {
      Serial.print("→ Send failed, code "); Serial.println(state);
    }
  }

  // Check for incoming packet
  String received = "";
  int state = radio.receive(received);

  if (state == RADIOLIB_ERR_NONE) {
    // Packet received!
    Serial.println("Received packet:");
    Serial.print("  Message: "); Serial.println(received);
    Serial.print("  RSSI: "); Serial.print(radio.getRSSI()); Serial.println(" dBm");
    Serial.print("  SNR: "); Serial.print(radio.getSNR()); Serial.println(" dB");
    Serial.println();
  } else if (state != RADIOLIB_ERR_RX_TIMEOUT) {
    // Some error (not just timeout)
    Serial.print("Receive error, code "); Serial.println(state);
  }

  // Small delay to avoid CPU hogging
  delay(10);
}
```

Réponse : OK 

```text
=== Multiple LLCC68 begin() tests  ===

BUSY after initial reset: 0
begin() = -707
Init FAILED - code -707
begin() = 0
Initialization SUCCESS!
0
Listening for packets...
Sending: Hello from ESP32 at 5s
→ Sent OK
Sending: Hello from ESP32 at 14s
→ Sent OK
```

### Etape 5 : on va utiliser tester communication bidirectionnel ESP32<-> ESP32

le but dans cette etape etant de verifier la reception d'un message provenant du module Heltec WiFi LoRa 32 

- on va faire tourner les deux cartes en même temps 
- avec le même code 

#### Resultat attendu 
 les messages envoyer par l'un doivent être visibles par l'autre dans le serial monitor 

#### Description du processus de communication entre les deux ESP32
- Les deux ESP32 ne sont pas reliés par fil (pas d'I2C, UART, USB, etc.).
Ils communiquent uniquement par ondes radio LoRa via leurs antennes.

- Chaque ESP32 + module LoRa a une petite antenne 868 MHz .
Quand un côté envoie, l'énergie RF sort par l’antenne → se propage dans l’air (jusqu’à plusieurs centaines de mètres en extérieur, 50–200 m en intérieur selon puissance et environnement).
L’autre côté reçoit ce signal grâce à son antenne → le module LoRa le décode → le passe à l’ESP32.

et c'est en foncitonn de la frequence qu'on a arrive à se synchroniser sur le deux EPS32 en même temps 

L’antenne capte le signal RF (ondes électromagnétiques à 868 MHz).

## objectif prochain -> tester la communication bidirectionnele 
## objectif prochain -> faire reveiller le module ESP32 avec le module LoRa
## integrer le module SIM7000 pour envoyer des messages recues par LoRa vers un téléhpone ou un site internet

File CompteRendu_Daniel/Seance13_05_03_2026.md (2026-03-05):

# 📝 Compte Rendu — CEBAN Daniel  
## Séance 13 du 5/03/2026 

---

## Problématique 
On n'arrive pas à communiquer avec le module LoRa en utilisant la librairie  **<RadioLib.h>**

---

## Objectifs

1. Changer le module **LoRa-CC68-868 G-NiceFR** et utiliser la bibliothèque **<LoRa.h>** 

2. Integration du module SIM7000G avec ESP32 nu

### Etape 1. coder avec la bibliothèque <LoRa.h>
On va utiliser la fonction **begin(long frequency)** pour initialiser la communication avec le module LoRa

```cpp
int LoRaClass::begin(long frequency)
{
#if defined(ARDUINO_SAMD_MKRWAN1300) || defined(ARDUINO_SAMD_MKRWAN1310)
  pinMode(LORA_IRQ_DUMB, OUTPUT);
  digitalWrite(LORA_IRQ_DUMB, LOW);

  // Hardware reset
  pinMode(LORA_BOOT0, OUTPUT);
  digitalWrite(LORA_BOOT0, LOW);

  pinMode(LORA_RESET, OUTPUT);
  digitalWrite(LORA_RESET, HIGH);
  delay(200);
  digitalWrite(LORA_RESET, LOW);
  delay(200);
  digitalWrite(LORA_RESET, HIGH);
  delay(50);
#endif

  // setup pins
  pinMode(_ss, OUTPUT);
  // set SS high
  digitalWrite(_ss, HIGH);

  if (_reset != -1) {
    pinMode(_reset, OUTPUT);

    // perform reset
    digitalWrite(_reset, LOW);
    delay(10);
    digitalWrite(_reset, HIGH);
    delay(10);
  }

  // start SPI
  _spi->begin();

  // check version
  uint8_t version = readRegister(REG_VERSION);
  if (version != 0x12) {
    return 0;
  }

  // put in sleep mode
  sleep();

  // set frequency
  setFrequency(frequency);

  // set base addresses
  writeRegister(REG_FIFO_TX_BASE_ADDR, 0);
  writeRegister(REG_FIFO_RX_BASE_ADDR, 0);

  // set LNA boost
  writeRegister(REG_LNA, readRegister(REG_LNA) | 0x03);

  // set auto AGC
  writeRegister(REG_MODEM_CONFIG_3, 0x04);

  // set output power to 17 dBm
  setTxPower(17);

  // put in standby mode
  idle();

  return 1;
}
```

#### Résultat : Echec 

on remarque dans le code de la bibliotheque LoRa que si la version du module n'est pas la 12 le code va toujours retourner la valeur 0 

```cpp
if (version != 0x12) {
    return 0;
  }
```

On va utiliser un code pour diagnostiquer la version actuelle du notre module 

```cpp
  digitalWrite(LORA_NSS, LOW);
  SPI.transfer(0x42 & 0x7F); // Adresse de lecture pour SX127x
  uint8_t version = SPI.transfer(0x00);
  digitalWrite(LORA_NSS, HIGH);
  Serial.print("Réponse du registre 0x42 (Version) : 0x");
  Serial.println(version, HEX);
```

#### Résultats de la version : 
```text
--- Diagnostic du module LoRa ---
Réponse du registre 0x42 (Version) : 0xAA
```
#### Conclusion 
1. La réponse du registre nous permet de dire qu'on arrive bien à communiquer avec le module 
2. La version 0xAA nous permet pas de communiquer avec le module LoRa (car le code nécessite la version 0x12)

### Etape 2
Utilisation d'une carte qui integre le module **EPS32** nu et le module **RF96** on va utiliser une connecteur UART pour tester la carte 

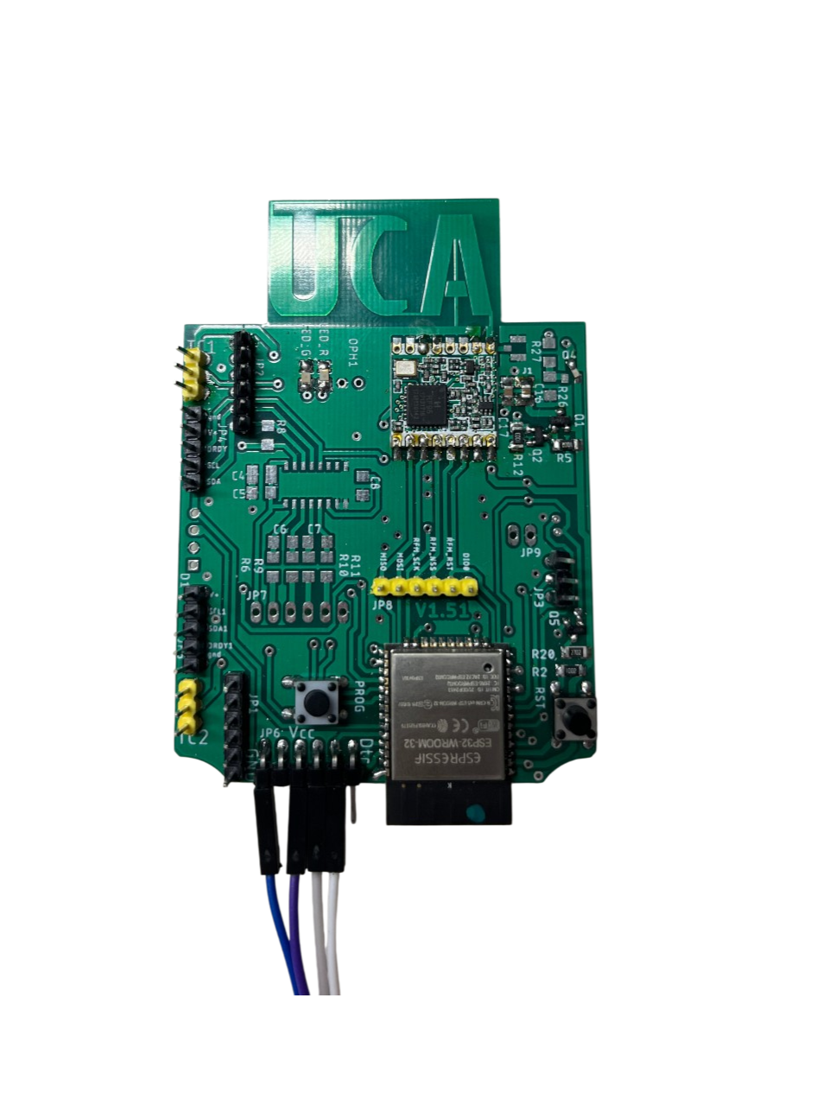
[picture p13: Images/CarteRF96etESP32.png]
Utilisation d'une nouvelle carte


### remarque 
on doit déclarer le GPIO13 en sortie et le mettre à HIGH

voici le code qu'on utiliser pour tester la nouvelle carte 

```cpp
#include <LoRa.h>
// Définition des broches selon votre montage
#define SCK     18
#define MISO    19
#define MOSI    23
#define NSS      5
#define RST     27
#define DIO0    34

#define ENABLE 13
void setup() {
  Serial.begin(115200);
  while (!Serial);
   pinMode(ENABLE, OUTPUT);
  digitalWrite(ENABLE, HIGH);
  LoRa.setPins(NSS, RST, DIO0);
  // 2. Initialiser la fréquence (868 MHz pour l'Europe)
  if (!LoRa.begin(868E6)) {
    Serial.println(F("ÉCHEC ! Le module ne répond pas. Vérifiez le câblage SPI."));
    while (1);
  }
  Serial.println("Succes");
}
```

### resultat 
```text
mode:DIO, clock div:1
load:0x3fff0030,len:4980
load:0x40078000,len:16612
load:0x40080400,len:3480
entry 0x400805b4
E BOD: Brownout detector was triggered
```

#### interprétation 
ESP32 redémarre parce que la tension chute brutalement
#### solution 
Brancher la carte sur une alimentation fixé qui va livrer une ampérage plus importante

#### Resultat BINGO!!!

```text
rst:0x3 (SW_RESET),boot:0x12 (SPI_FAST_FLASH_BOOT)
configsip: 0, SPIWP:0xee
clk_drv:0x00,q_drv:0x00,d_drv:0x00,cs0_drv:0x00,hd_drv:0x00,wp_drv:0x00
mode:DIO, clock div:1
load:0x3fff0030,len:4980
load:0x40078000,len:16612
load:0x40080400,len:3480
entry 0x400805b4
Succes

```

### Etape 4. plan d'action

le but étant de faire fonctionner le composant LoRA-CC68. Avec la carte précédente on a vu qu'on peut utiliser le module <LoRa.h> pour faire fonctionner un module LoRa cependant il est compatible seulement avec une puce de version 0x12. Or notre carte a une version 0xAA. 

Par la suite on va donc revenir à la bibliothèque <RadioLib.h> plus complète et plus bavarde (nous indique les codes erreurs). On va donc essayer de faire fonctionner le composant LoRA-CC68 avec l'ancien brochage.

### Etape 5. retester l'ancien câblage avec Module LoRA et ESP32

```text
=== LLCC68 Init Test (XTAL mode) ===
Pins: NSS=5 DIO1=34 NRST=27 BUSY=35
Initial BUSY state: 0
[LLCC68] begin() returned: -707
FAILED – code -707
```

Toujours la même erreur on arrive à detecter le moduole mais on ne recoit aucune réponse (erreur 707) 

Investigation par la suite... 

### Etape 3. Integration du module SIM 7000G avec l'ESP32 nu 

Schéma de connexion (Câblage UART). Le SIM7000G communique SPI

| SIM7000G Pin | ESP32 GPIO | Fonction | Note |
|---|---|---|---|
| VCC | 5V / VIN | Alimentation | Attention : Doit fournir 2A en pointe ! |
| GND | GND | Masse commune | Indispensable pour la communication. |
| TX | GPIO 16 (RX2) | Données SIM -> ESP | |
| RX | GPIO 17 (TX2) | Données ESP -> SIM | |
| PWRKEY | GPIO 4 | Allumage | Nécessite une impulsion basse pour démarrer. |

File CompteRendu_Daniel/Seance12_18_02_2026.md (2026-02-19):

# 📝 Compte Rendu — CEBAN Daniel  
## Séance 12 du 18/02/2026 

---

## Problématique 
Code -707 : RADIOLIB_ERR_INVALID_BUSY_STATE -> on n'arrive pas à communiquer avec le module LoRa

---

## Objectifs

Résoudre les problèmes de câblage pour communiquer avec LoRa sinon passer à la partie suivante et commencer la communication entre le module SIM7000 et ESP32 nu.

---

## Étapes de la séance 

---

### Étape 1 : Investigation

Retour d'une IA

```text
The error code is officially RADIOLIB_ERR_SPI_CMD_FAILED (-707) in current RadioLib versions. The library docs say exactly this:
"Often this means that the module is trying to use TCXO while XTAL is connected (or vice versa)."
```

### Ajout de deux condensateurs de découplage 

1. on va ajouter un condensateur chimique de 10 µF entre le VCC et le GND de la partie LoRa
2. pour plus d'efficacité on va rajouter un condensateur de 98 nF céramique en parallèle avec l'autre 

-> Résultat toujours l'erreur 707 -> RADIOLIB_ERR_SPI_CMD_FAILED

### Changement de câblage 

On va mettre le BUSY (patte 16) du Module LoRa sur le GPIO 36, et on va essayer également les GPIO 39, 33, 32 et 25 

### Etape 2 Passer à la suite 

#### Résultat final après plusieurs tentatives, changements dans le code et 3 séances sans résultat. 

On n'arrive pas à communiquer avec le module LoRa la carte est detecté par le module ESP32 mais ils n'arrivement aps à communiquer -> erreur -707. toute tentation de recablage ou de changment dans le code à donne le même code erreur on va donc faire quelques changements dans notre projet.

On va donc reprendre un autre module **RFM (SX1276)** qui a un modem LoRa intégré -> 
en utilisant la bibliothèque "LoRA" -> https://github.com/sandeepmistry/arduino-LoRa/tree/master

-> TODO demander le module RFM

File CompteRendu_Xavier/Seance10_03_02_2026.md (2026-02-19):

# CR - MIRRIONE Xavier  
## Séance 10 du 03/02/2026  

Installation d'autodesk Eagle sur le PC pour la réalisation schématic de la carte de la gateway.

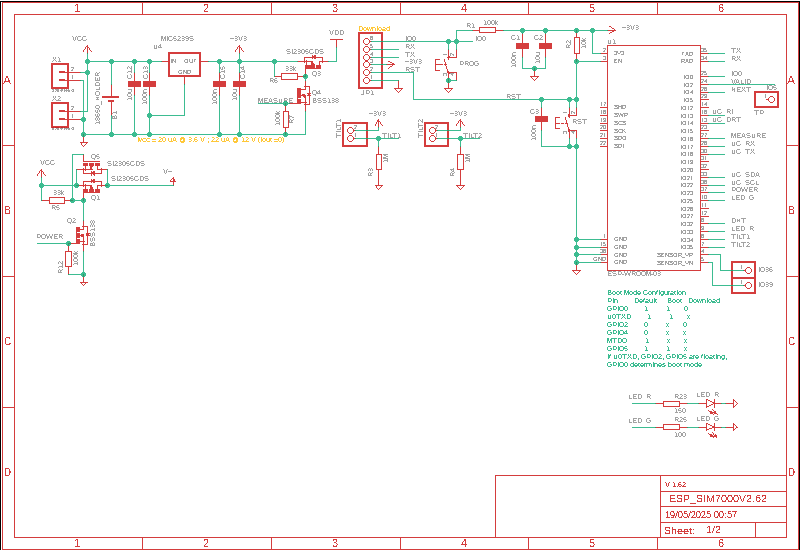
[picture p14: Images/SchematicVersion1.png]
Schéma général projet


Voici la première version établie par l'ancien groupe, les deux leds ont été gardées. Il manque encore la photo résistance afin d'avoir le mode jour / nuit. Mais il faut aussi changer l'ESP32, celui dont il disposait possédait un LoRa intégré. Dans notre cas celui-ci est séparé.

## Prochainement
- Avancer le schématic = ajouter un sheet pour le SIM7000G
- Définir les pins nécessaires pour le cablage sur la plaque labdec
- Voir et régler le problème dont ils avaient l'ancien groupe avec le LoRa

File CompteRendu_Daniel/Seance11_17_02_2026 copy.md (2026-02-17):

# 📝 Compte Rendu — CEBAN Daniel  
## Séance 11 du 17/02/2026 

### Problematique 
Le code toujours = -2 
ce qui signifique que le module ESP32 ne trouve pas le module LoRa
Tension qui arrive sur module LoRa = **2.9 V** (pas assez ? )

#### Solutions possibles 

1. On va connecter les 2 autres messes du module LoRa à la masse communice pour être sûr 
2. On va founir la tension 3.3 V à partir d'un générateur de tension stable. pour être sûr qu'on a du 3.3V sur le LoRa est le module ESP32.

3. Si ca ne fonctionne pas on va alors ajouter des condensateurs de découplage.

## Objectif de la séance 

Comprendre pourquoi on n'arrive pas à communiquer avec le module LoRa et éventuellement résoudre le problème pour établir une communication entre le module **ESP32** et le module **LoRa**

---

### Problematique 
Le code toujours = -2 
ce qui signifique que le module ESP32 ne trouve pas le module LoRa
Tension qui arrive sur module LoRa = **2.9 V** (pas assez ? )

---

#### Solutions possibles 

1. On va connecter les 2 autres messes du module LoRa à la masse communice pour être sûr 
2. On va founir la tension 3.3 V à partir d'un générateur de tension stable. pour être sûr qu'on a du 3.3V sur le LoRa est le module ESP32.

3. Ajouter des condensateurs de découplage.

---

## Étapes de la séance 

### Étape 1 : Changer la source de tensions

On va donc connecter le générateur de tension aux modules LoRa et ESP32 pour s'assurer qu'on a bien une tension de 3.3 V à l'entrée des deux modules 

On va aussi relier les 3 masses du module LoRa à la masse principale. 

On essaye de démarrer une dernière fois avec le connecteur USB serial SPI qui fournit 3.3 V et on a ce message 

```text

Panic handler entered multiple times. Abort panic handling. Rebooting ...
Panic handler entered multiple times. Abort panic handling. Rebooting ...
ets Jun 8 2016 00:22:57
rst:0x7 (TG0WDT_SYS_RESET),boot:0x13 (SPI_FAST_FLASH_BOOT)
configsip: 0, SPIWP:0xee
clk_drv:0x00,q_drv:0x00,d_drv:0x00,cs0_drv:0x00,hd_drv:0x00,wp_drv:0x00
mode:DIO, clock div:1
load:0x3fff0030,len:4980
load:0x40038000,len:232
load:0x4000c44c,len:1073676304
1162 mmu set 00010000, pos 00010000
1162 mmu set 00020000, pos 00020000
```

#### Explication possible 

L'adaptateur FTDI (la carte rouge) ne peut pas fournir assez de courant stable. La tension chute, la mémoire flash renvoie n'importe quoi (d'où le len énorme), et l'ESP32 panique.

#### Test avec générateur 3.3V 

Après avoir généré la tension de 3.3 avec le générateur on a toujours une erreur de comm entre LoRa et ESP32
```text
--- Test de communication ESP32 <-> LoRa CC68 ---
[LLCC68] Initialisation... ÉCHEC. Code erreur : -2
Erreur: Le module ne répond pas
```

#### Vérification de la tension aux bornes du LoRa

La tension à l'entrée des deux composants LoRa et ESP32 est bien de 3.3 (plus précisément 3.299)

### Vérification du câblage et remplacement de câbles

Après avoir remplacé certains câbles on arrive à recevoir une nouvelle erreur

```text
--- Test de communication ESP32 <-> LoRa CC68 ---
[LLCC68] Initialisation... ÉCHEC. Code erreur : -707

```
L'erreur -707
est spécifique à la bibliothèque RadioLib. Elle correspond à RADIOLIB_ERR_CHIP_NOT_FOUND

### Changement de la carte LoRa CC68-868 GNiceRF -> LoRa GNice

Avec la nouvelle carte on a l'erreur -2 

Code -2 : RADIOLIB_ERR_CHIP_NOT_FOUND
C'est une erreur de connexion totale.

2. Code -707 : RADIOLIB_ERR_INVALID_BUSY_STATE (Spécifique LLCC68/SX126x)
C'est une erreur de dialogue bloqué.

On va revenir à l'ancienne carte alors 

### Utiliser les broches 32 (BUSY) et 33 (DIO1) à la place. Elles possèdent des résistances internes qui stabilisent le signal.

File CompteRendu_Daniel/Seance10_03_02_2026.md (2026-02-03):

# 📝 Compte Rendu — CEBAN Daniel  
## Séance 10 du 03/02/2026 

---

## 🔴 Problématique rencontrée lors de la dernière séance 
On n'arrive plus à faire télécharger du code sur le module **ESP32** même en faisant le câblage avec le module ESP32 seul 

## 🎯 Objectif de la séance 
⚠️ Comprendre pourquoi le module ESP32 ne fonctionne plus ?
- Problème du câblage ? 
- Module défectueux ? 
- Mauvaise manipulation des boutons. 
Ajouter le module LoRa et vérifier l'intégralité du montage 

## 📋 Étapes de la séance 

### Étape 1 : Vérification de la carte ESP32 🔍

Après recâblage on retrouve une autre erreur de téléversement 
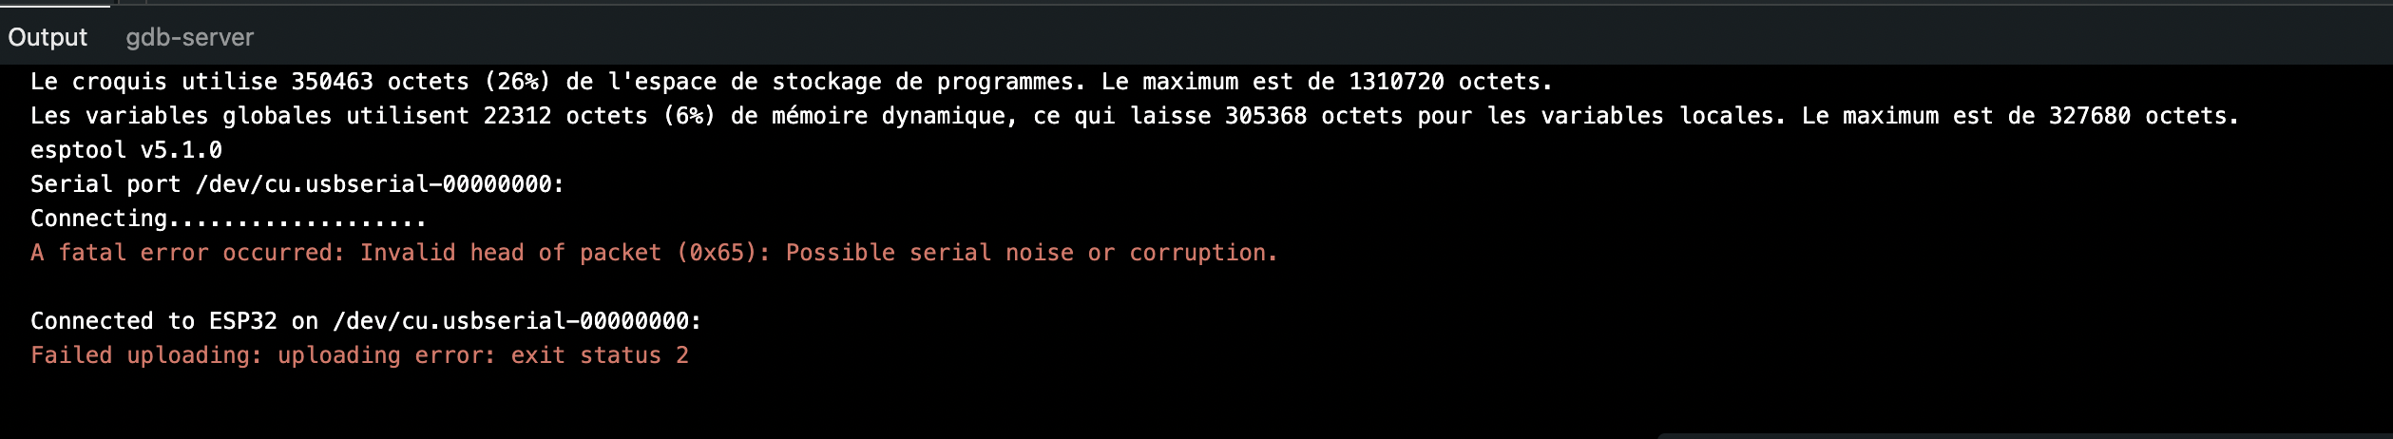
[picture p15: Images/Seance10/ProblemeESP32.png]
Problème téléversement


On a retesté avec la bonne séquence d'appuyer sur le bouton et cette fois ça marche 

1. Appuyer sur le bouton téléverser le programme
2. Maintenir le bouton RST enfoncé 
3. Lorsque on voit le message "Connecting..." En maintenant le bouton RST appuyer sur le bouton PRG pour une courte période 
4. Relâcher les deux boutons 

Voici le câblage actuel :

| Composant | Départ | Arrivée | Note |
| --- | --- | --- | --- |
| Alimentation | Sortie 3.3V de l'USB | Broche 2 (3V3) | JAMAIS de 5V sur cette broche ! |
| Masse | GND de l'USB | Broche 1 (GND) |  |
| Série TX | TX de l'USB | Broche 40 (RXD0) | Inversion standard (TX vers RX) |
| Série RX | RX de l'USB | Broche 41 (TXD0) | Inversion standard (RX vers TX) |
| Pull-up EN | Broche 9 (EN) | 3.3V | Via ta résistance $100k\Omega$ |
| Pull-up GPIO0 | Broche 23 (GPIO0) | 3.3V | Via ta résistance $100k\Omega$ |

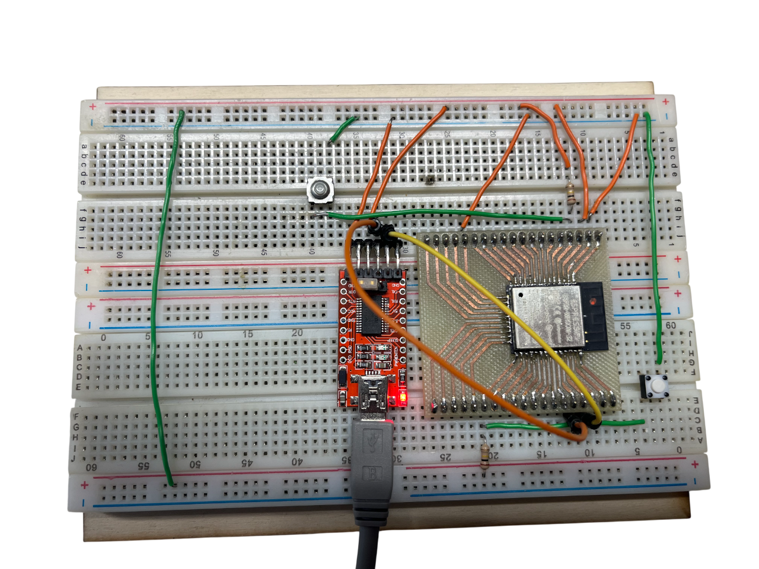
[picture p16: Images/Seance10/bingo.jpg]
Montage qui marche


```text
rst:0x1 (POWERON_RESET),boot:0x13 (SPI_FAST_FLASH_BOOT)
configsip: 0, SPIWP:0xee
clk_drv:0x00,q_drv:0x00,d_drv:0x00,cs0_drv:0x00,hd_drv:0x00,wp_drv:0x00
mode:DIO, clock div:1
load:0x3fff0030,len:4980
load:0x40078000,len:16612
load:0x40080400,len:3480
entry 0x400805b4
=======================================
   TEST DIAGNOSTIC ESP32 REUSSI !
=======================================
Frequence CPU : 240 MHz
L'ESP32 tourne depuis : 0 secondes.
L'ESP32 tourne depuis : 1 secondes.
```

### Étape 2 : Connecter le module LoRa

On a câblé le module LoRa et exécuté un code qui peut vérifier que l'ESP32 est bien relié à un module LoRA.

Voici le code qui permet de vérifier si le module LoRa est bien connecté.

```cpp
#include <RadioLib.h>
// NSS: 5, DIO1: 34, NRST: 27, BUSY: 35
LLCC68 radio = new Module(5, 34, 27, 35);

void setup() {
  Serial.begin(115200);
  delay(2000); // Laisse le temps au port série de s'ouvrir

  Serial.println(F("\n--- Test de communication ESP32 <-> LoRa CC68 ---"));
  Serial.print(F("[LLCC68] Initialisation... "));
  int state = radio.begin(868.0);

  if (state == RADIOLIB_ERR_NONE) {
    Serial.println(F("SUCCÈS !"));
    Serial.println(F("Le module LoRa répond et le câblage SPI est correct."));
  } else {
    Serial.print(F("ÉCHEC. Code erreur : "));
    Serial.println(state);
    
    // Aide au diagnostic
    if (state == -2) Serial.println(F("Erreur: Le module ne répond pas"));
    if (state == -70) Serial.println(F("Erreur: Broche BUSY bloquée. Vérifiez le GPIO 35."));
    
    while (true); // Bloque ici si ça ne marche pas
  }
}
```

Erreur lors de l'exécution du code
```text
configsip: 0, SPIWP:0xee
clk_drv:0x00,q_drv:0x00,d_drv:0x00,cs0_drv:0x00,hd_drv:0x00,wp_drv:0x00
mode:DIO, clock div:1
load:0x3fff0030,len:4980
load:0x40078000,len:16612
load:0x40080400,len:3480
entry 0x400805b4

--- Test de communication ESP32 <-> LoRa CC68 ---
[LLCC68] Initialisation... ÉCHEC. Code erreur : -2
Erreur: Le module ne répond pas. Vérifiez le câblage et l'alimentation 3.3V.

```

### Problematique 
Le code toujours = -2 
ce qui signifique que le module ESP32 ne trouve pas le module LoRa
Tension qui arrive sur module LoRa = **2.9 V** (pas assez ? )

#### Solutions possibles 

1. On va connecter les 2 autres messes du module LoRa à la masse communice pour être sûr 
2. On va founir la tension 3.3 V à partir d'un générateur de tension stable. pour être sûr qu'on a du 3.3V sur le LoRa est le module ESP32.

3. Si ca ne fonctionne pas on va alors ajouter des condensateurs de découplage.

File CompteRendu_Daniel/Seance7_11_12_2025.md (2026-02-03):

# 📝 Compte Rendu — CEBAN Daniel  
## Séance7  du 11/11/2025 

---
## Objectif de la seance 
Câbler un ESP32 (sans le module LoRA) et un module LoRa pour implémenter une fonctionnalité de réveil de l'ESP32 en utilisant seulement le module LoRa.
---

## Etape 1 Câblage ESP32->PC 
- Le but de cette étape de de verifier la connexion EPS32 -> PC 
- Vefirier le fontionnement de buttons 
- Télécharger un programme sur le ESP32

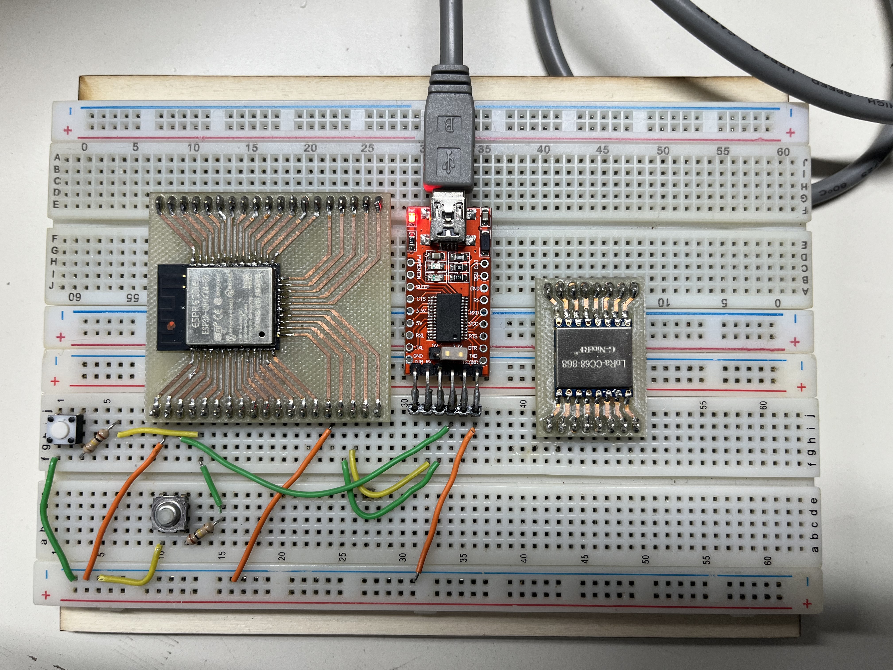
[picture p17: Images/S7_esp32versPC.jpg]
1 version câblage
 

### probleme 

```text
Connecting......................................
A fatal error occurred: Failed to connect to ESP32: No serial data received.
For troubleshooting steps visit: https://docs.espressif.com/projects/esptool/en/latest/troubleshooting.html

Failed uploading: uploading error: exit status 2
````
Explications 
```text
Le bouton "PRG" sur le GPIO 36 c'est une erreur. Le GPIO 36 est une broche d'entrée seulement (Sensor VP), elle ne sert jamais au démarrage.
```

Troubleshoting 
```text
Pour mettre l'ESP32 en mode "Téléchargement" (Download Mode), l'ESP32 regarde l'état de la broche GPIO 0 au moment exact où il démarre.

- Si GPIO 0 est connecté à la masse (GND) au démarrage -> L'ESP32 attend le code (Mode Flash).
- Si GPIO 0 est connecté au 3.3V (HIGH) au démarrage -> L'ESP32 lance le programme (Mode Normal).
```
Si les boutons sont mal câblés (surtout le GPIO 0), l'IDE Arduino n'arrivera jamais à se connecter. Il affichera une erreur du type "Timed out waiting for packet header".

### Cablage correct 

1. Button "RST" :
 - Connecter une résistance de 100kΩ entre EN et 3.3V. (Pour garder la puce allumée par défaut).
 - Connecte ton bouton poussoir entre EN et GND. (Appuyer dessus redémarre la puce).

2. Button "PRG" :
 - Connecte une résistance de 100kΩ entre GPIO 0 et 3.3V.
 - Connecte ton bouton poussoir entre GPIO 0 et GND.

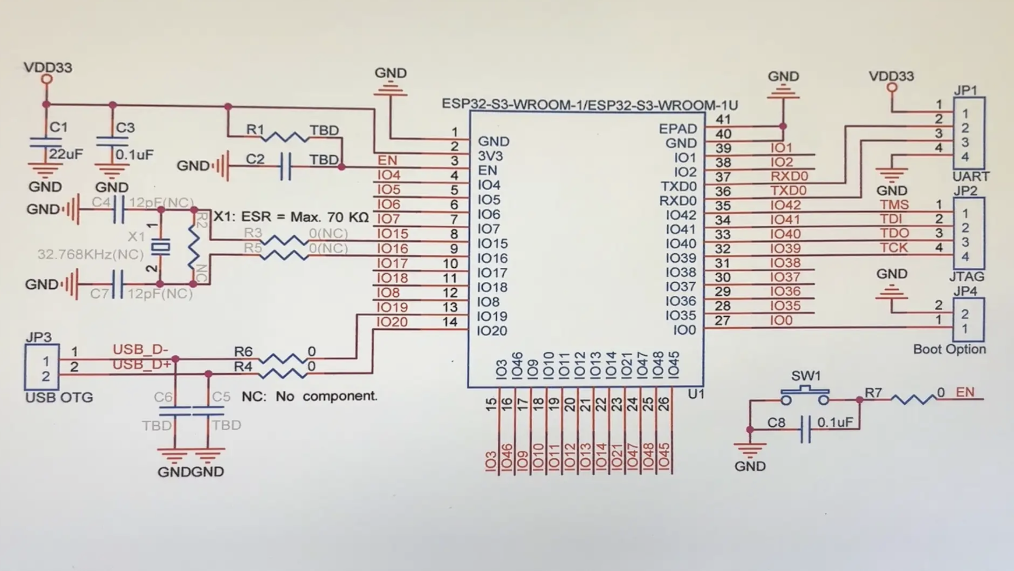
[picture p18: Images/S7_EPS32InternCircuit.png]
Circuit interne du ESP32 nu
 

### 2 problem RX et TX mouvais câblage

Apres avoir connecte le 2 button on s'est rendu compte qu'on doit utilier le button 
- TX de la pâte 41 du ESP32
- RX de la pâte 40 du ESP32 

Voic le câblage EPS32 nu -> qui marche 

### Bingo !!!
On arrive a télécharger les donnes vers ESP32
```text
Connecting.....
Connected to ESP32 on /dev/cu.usbserial-00000000:
Chip type:          ESP32-D0WDQ6 (revision v1.0)
Features:           Wi-Fi, BT, Dual Core + LP Core, 240MHz, Vref calibration in eFuse, Coding Scheme None
Crystal frequency:  40MHz
MAC:                24:6f:28:20:8f:20

Uploading stub flasher...
Running stub flasher...
```

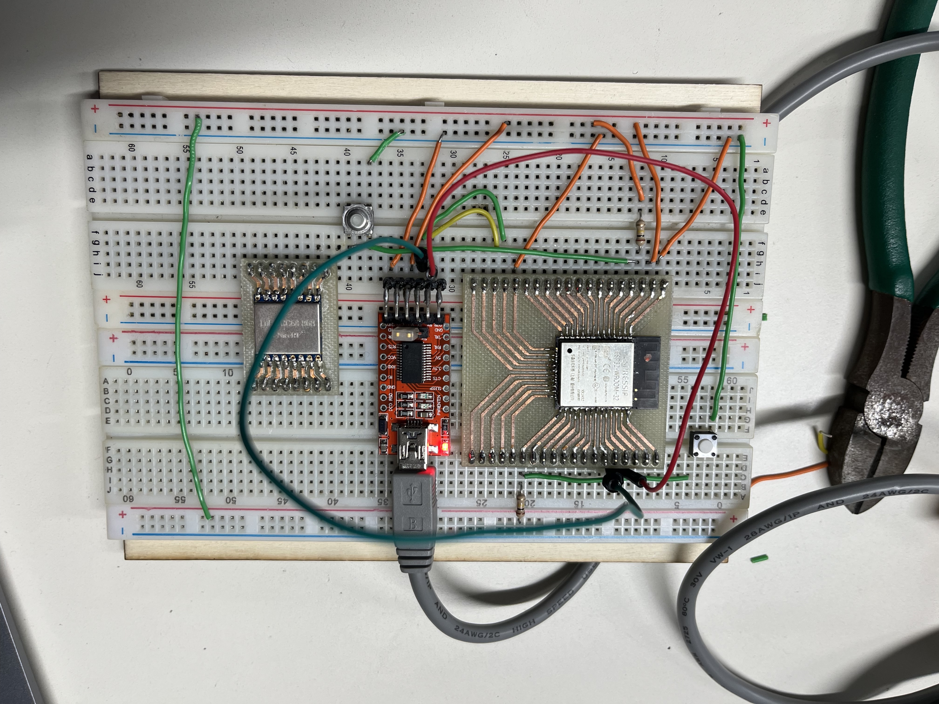
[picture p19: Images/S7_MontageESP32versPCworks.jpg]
montage ESP32
 

---

## Etape 2 Cabler et connecter le module LORA au ESP32

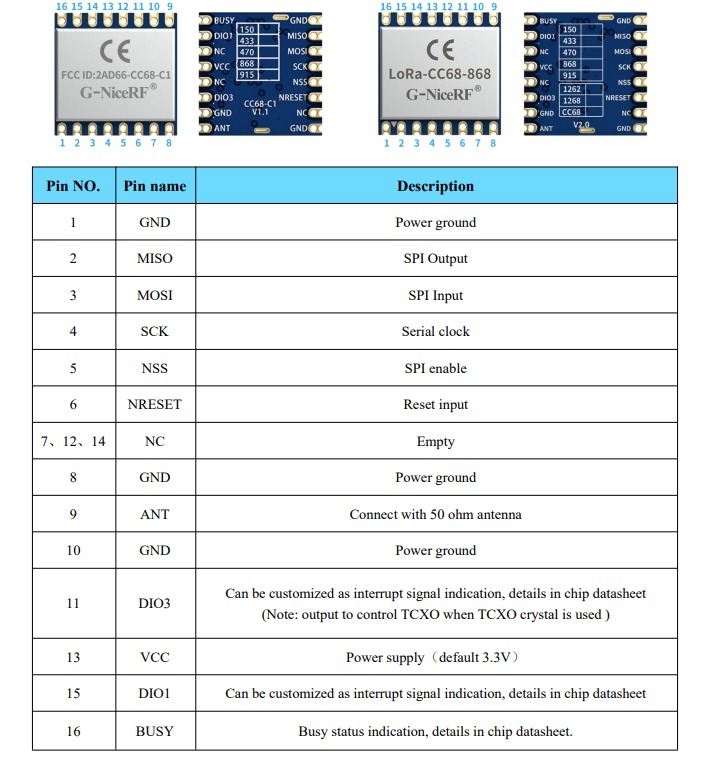
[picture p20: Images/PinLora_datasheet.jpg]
pin lora
 

Pour connecter le module LoRa à l'ESP32, nous allons utiliser l'interface SPI (Serial Peripheral Interface).

```text
Serial Peripheral Interface (SPI) is a de facto standard (with many variants) for synchronous serial communication, used primarily in embedded systems for short-distance wired communication between integrated circuits.
```

Alimentation (VCC) : Le module LoRa doit être alimenté en 3.3V (Pin 13). N'utilisez JAMAIS 5V.

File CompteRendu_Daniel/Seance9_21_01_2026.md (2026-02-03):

# 📝 Compte Rendu — CEBAN Daniel  
## Séance 9 du 21/01/2026 

---

## Objectif de la séance 
Continuer à cabler la partie LoRa sur le montage et faire une analyse de la continuation du projet.

---

## Etapes de la seance 

### Etape 1 : Finir câblage SPI entre LoRa et EPS32

**Tableau Connexion LoRa -> ESP32 WROOM-32**

| Broche LoRa (Pin Name) | Broche LoRa (N°) | Fonction | Broche ESP32 WROOM-32 (GPIO) | Broche ESP32 (Pin N°) |
|---|---|---|---|---|
| VCC | 13 | Alimentation | 3.3V (Source d'alimentation régulée) | (À connecter à la même source 3.3V que l'ESP32) |
| GND | 1, 8, 10 | Masse | GND | (Déjà fait) |
| MOSI | 3 | Maître $\rightarrow$ Esclave | GPIO 23 (VSPI_D) | 36 |
| MISO | 2 | Esclave $\rightarrow$ Maître | GPIO 19 (VSPI_Q) | 38 |
| SCK | 4 | Horloge | GPIO 18 (VSPI_CLK) | 34 |
| NSS | 5 | Chip Select (CS) | GPIO 5 (VSPI_CS0) | 31 |

**Tableau des broches de Contrôle**

| Broche LoRa (Pin Name) | Broche LoRa (N°) | Fonction | Broche ESP32 WROOM-32 (GPIO) | Notes |
|---|---|---|---|---|
| NRESET | 6 | Reset du module | GPIO 27 | Broche libre courante. |
| DIO1 | 15 | Interruption 1 | GPIO 34 | Broche d'entrée uniquement (parfaite pour les interruptions). |
| BUSY | 16 | État Occupé | GPIO 35 | Broche d'entrée uniquement. |

#### Points importants 

- Le module LoRa doit être alimenté en 3.3V ✅
- connecter une antenne appropriée à la broche ANT (Pin 9) avant la première émission, sinon on risque d'endommager le module.
- dans le code on doit initialiser la bibliothèque LoRa (la librairie SX127x) en spécifiant les numéros de GPIO.

### Etat de câblage actuel 

- VCC - ✅
- GND - ✅
- MOSI - ✅
- MISO - ✅
- SCK - ✅
- NSS - ✅
- NRESET - ✅
- DIO1 - ✅
- BUSY - ✅
- ANT - ✅

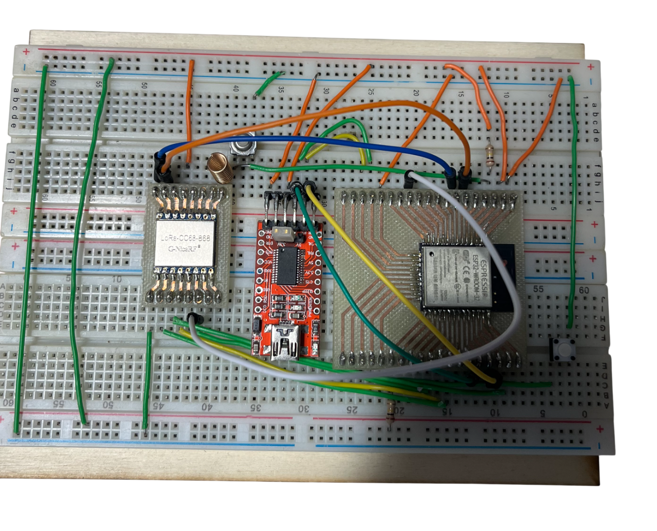
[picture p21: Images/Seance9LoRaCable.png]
1 ESP32 & LoRa câblé


## Etape 2 : definir Scénario type de communication

le but etant de déterminer les protocoles et les étapes à suivre dans la suite du projet

1) Collecte locale via LoRa
- Protocole radio: LoRa PHY (EU868)
- Module: Transceiver type SX127x relié en SPI à l'ESP32 (MOSI/MISO/SCK/CS).
- Trame application: JSON compact (ou binaire propriétaire + CRC16) contenant `hive_id`, `temp_c`, `weight_kg`, `rssi`, `timestamp`.

2) Réveil et acquisition sur ESP32
- Énergie: l'ESP32 reste en deep‑sleep entre deux transmissions (objectif µA).
- Réveil: interruption externe via `DIO1` du LoRa sur `GPIO34/35` (entrée seule) → `esp_sleep_enable_ext1_wakeup()`.
- Interfaces internes: SPI (LoRa) pour lire la trame

3) Remontée longue portée via SIM7000G
- Lien MCU↔modem: UART 115200 8N1 (AT commandes) via TinyGSM.
- Attachement réseau: 3GPP (GPRS/EDGE 2G ou LTE Cat‑M1/NB‑IoT si disponible); activation PDP (APN `sl2sfr`).
- Couche IP: IPv4 fournie par le PDP; transport TCP; application HTTP.
- Envoi données: HTTP POST (JSON) vers le serveur cible (ex: `http://rucher.polytech.unice.fr/`).
- Alerte SMS: en alternative ou redondance, envoi SMS (3GPP TS 23.040) via `modem.sendSMS()`.

4) Intégration matérielle (PCB)
- Alimentation: rail modem 4.0 V pour (SIM7000G); rail 3.3 V séparé pour ESP32 + LoRa.
- Découplage: ≥ 470–1000 µF près du SIM7000G + céramiques proches de chaque VCC.
- Commande PWRKEY: transistor/MOSFET piloté par GPIO ESP32; accès test‑points (EN, IO0, RST, TX0/RX0).
- Niveaux logiques: vérifier compatibilité UART du module utilisé; prévoir translation si nécessaire.
- RF: pistes 50 Ω, plans de masse continus, keep‑out sous antennes; connecteurs u.FL/SMA (cellulaire et 868 MHz) + ESD.
- EMI/SE: séparation des retours de courant (modem ↔ logique), via stitching, guidelines de routage SPI/UART.

### Etape 3 : Faire un code test pour véfier si on arrive à communiquer avec LoRa

blocage on n'arrive pas a communiquer avec le ESP32
on va revoir tout la partie câblage

Retour eux étapes initialles

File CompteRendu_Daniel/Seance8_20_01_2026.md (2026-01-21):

# 📝 Compte Rendu — CEBAN Daniel  
## Séance 8 du 20/01/2026 

---

## Objectif de la séance 
Récapitulatif des compétences acquises, définition des objectifs futurs.

---

## 📊 Récapitulatif du projet 

**Accomplissements** :
- ✅ Compréhension de l'architecture globale du système 
- ✅ Identification des deux technologies clés : **LoRa** (collecte basse consommation) et **GSM/SIM7000G** (transmission longue portée)
- ✅ Communication entre ESP32 et SIM7000
  - envoi de message SMS 
  - simulation des données des ruches
  - envoi des requettes HTTP
- ✅ Prise en main de l'ESP32 nu et cablage de buttons 
- ✅ Communication avec l'ESP32 nu

---

**Objectifs Futurs** :
- Câblage de la partie LoRa et initialisation de la communication entre LoRa et EPS32 nu
- Faire le code pour la Simulation des données et réveil de l'ESP32 avec le module LoRA
- Ajout du module SIM7000 au reste du projet
- Simulation et tests de tous le modules 
  - Reception des données avec la partie LoRa
  - Reveil de l'ESP32 avec LoRa 
  - Reception des données en utilisation l'ESP32
  - Envoi de donnes par SMS en utilisant SIM7000
  - Envoi de données par GPRS(HTTP) sur le site internet 
- Concevoir à fabriquer un circuit integre (PCB) qui integre tous les partie 

## tableau recapitulatif des objectifs globaux
| Objectif | Statut | Notes |
|---|---|---|
| **Obj 1** : Communication ESP32 ↔ SIM7000G + SMS | ✅ Réussi | Modem redémarrage, SMS envoyé |
| **Obj 2** : Simulation données + transmission HTTP | ✅ Réussi | Données sérialisées en JSON, prêtes pour envoi |
| **Obj 3** : Câblage ESP32 + Module LoRa | 🟡 En cours | Câblage SPI en cours, téléversement OK |
| **Obj 4** : Intégration SIM7000G + LoRa + SIM7000 | ⏳ À venir | Dépend de fin Obj 3 |
| **Obj 5** : Design PCB final | ⏳ À venir | Intégration complète ESP32 + LoRa + SIM |

---

### Phase 2 : Intégration complète objectifs future 

**Objectif futur** : Système complet ESP32 + LoRa + SIM7000G
- **À faire** :
  1. Combiner le code LoRa + EPS32 + GSM/SMS
  2. Implémenter le cycle complet :
     - Réveil via LoRa → Collecte données → Envoi SMS/HTTP via SIM
  3. Tests d'endurance (durée de vie batterie)
  4. Optimisation consommation d'énergie
  5. Connecter à l'URL : `http://rucher.polytech.unice.fr/`
  6. Tester l'envoi des données par SMS et HTTP

---

## Etapes de la seance 

### Etape 1 : Finir câblage SPI entre LoRa et EPS32

**Tableau Connexion LoRa -> ESP32 WROOM-32**

| Broche LoRa (Pin Name) | Broche LoRa (N°) | Fonction | Broche ESP32 WROOM-32 (GPIO) | Broche ESP32 (Pin N°) |
|---|---|---|---|---|
| VCC | 13 | Alimentation | 3.3V (Source d'alimentation régulée) | (À connecter à la même source 3.3V que l'ESP32) |
| GND | 1, 8, 10 | Masse | GND | (Déjà fait) |
| MOSI | 3 | Maître $\rightarrow$ Esclave | GPIO 23 (VSPI_D) | 36 |
| MISO | 2 | Esclave $\rightarrow$ Maître | GPIO 19 (VSPI_Q) | 38 |
| SCK | 4 | Horloge | GPIO 18 (VSPI_CLK) | 34 |
| NSS | 5 | Chip Select (CS) | GPIO 5 (VSPI_CS0) | 31 |

**Tableau des broches de Contrôle**

| Broche LoRa (Pin Name) | Broche LoRa (N°) | Fonction | Broche ESP32 WROOM-32 (GPIO) | Notes |
|---|---|---|---|---|
| NRESET | 6 | Reset du module | GPIO 27 | Broche libre courante. |
| DIO1 | 15 | Interruption 1 | GPIO 34 | Broche d'entrée uniquement (parfaite pour les interruptions). |
| BUSY | 16 | État Occupé | GPIO 35 | Broche d'entrée uniquement. |

#### Points importants 

- Le module LoRa doit être alimenté en 3.3V 
- connecter une antenne appropriée à la broche ANT (Pin 9) avant la première émission, sinon on risque d'endommager le module.
- dans le code on doit initialiser la bibliothèque LoRa (la librairie SX127x) en spécifiant les numéros de GPIO.

### Etat de câblage actuel 

- VCC - ✅
- GND - ✅
- MOSI - ✅
- MISO - ✅
- SCK - ✅
- NSS - 🟡 en cours 
- NRESET - 🟡
- DIO1 - 🟡
- BUSY - 🟡
- ANT - 🟡

1 ESP32 & LoRa câblé

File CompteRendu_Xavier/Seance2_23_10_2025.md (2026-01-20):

# CR - MIRRIONE Xavier  
## Séance du 22/10/2025  

## CONTEXTE
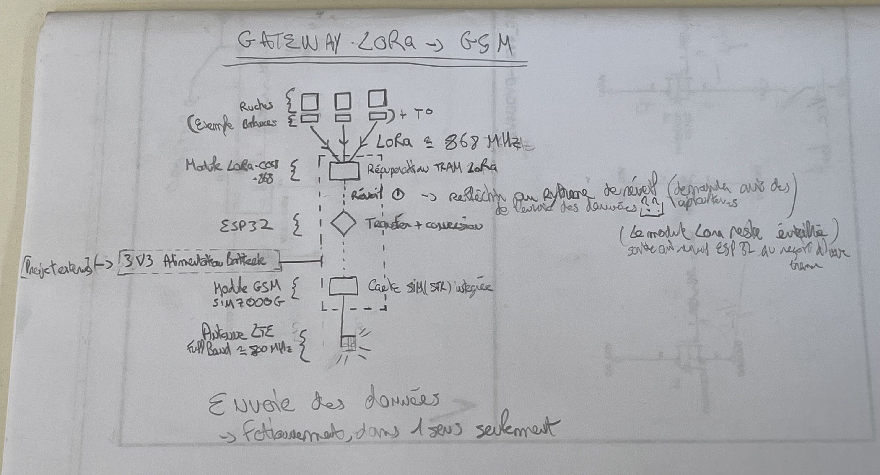
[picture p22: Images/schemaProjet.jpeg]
Schéma général projet


Lors de la séance précédante, un schéma a été dessiné afin de mieux appréhender et comprendre le projet LoRa-GSM. Le principe du projet est le suivant : 

1. Le module **LoRa-CC68-868**, fonctionnant à 868 MHz, sera le seul composant à garder un état éveillé. 
2. Réception d'une TRAME LoRa (température de la ruche, poids de la ruche), il réveillera l'ESP32.
3. L'**ESP32** se chargera de la conversion des données reçues.Ces données seront transférées au **Module GSM SIM7000G**.
4. Le module GSM avec **carte SIM** intégrée, se chargera d'envoyer des données et informations à l'agriculteur sur son téléphone via une **antenne LTE** Full band 800 MHz.

Notre projet répond à ce principe de fonctionnement, dans un seul sens seulement. Et à cette nécessité de recevoir les informations et mesures des ruches en temps réel en GSM, via téléphone portable.

L'alimentation globale du système sera en 3V3. Un projet externe, annexe au autre, appartenant à un autre groupe est la confection d'une alimentation, batterie. Permettant ainsi à notre projet de se rendre portable.  

### 1. Branchement de l'ESP32 avec le module GSM SIM7000G
- Dans le CR Finale du groupe précédent, ils se sont trompé au niveau du schéma utilisés pour les pins du Heltec Wifi Lora ESP 32.

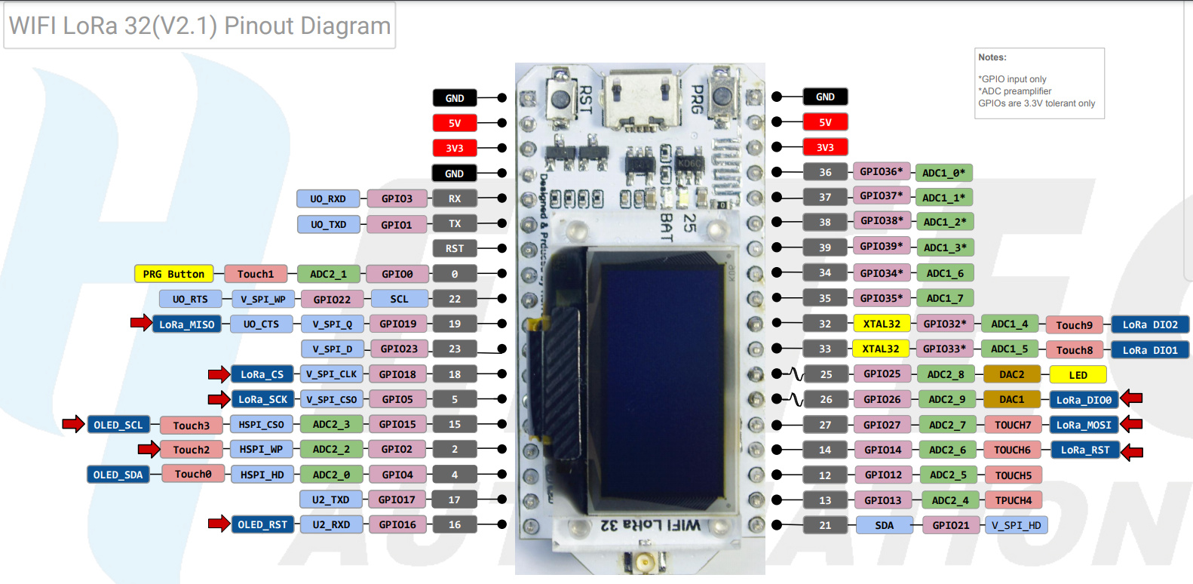
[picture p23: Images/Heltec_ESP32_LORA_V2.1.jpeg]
ESP32 PINS


- Celui dont on utilise est le V2.1, or leur schéma est celui du V3. Même si les pins RX TX reste les mêmes (5 RX - 6 TX)

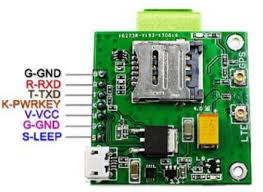
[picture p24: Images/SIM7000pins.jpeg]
SIM700G PINS
  

- Le branchement des pins Rx et Tx est fait de manière croisée. Tx to Rx de l'un et l'autre. Non Tx to Tx / Rx to Tx.  

### Prochaines étapes à faire lors de la prochaine séance 
- Finaliser le branchement des deux modules, le PWRKEY n'a pas été branché, des recherches appronfondies doivent être faite sur son principe de fonctionnement.
- Téleverser et faire fonctionner le code de l'ancien groupe.

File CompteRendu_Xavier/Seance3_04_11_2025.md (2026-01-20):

# CR - MIRRIONE Xavier  
## Séance du 04/11/2025  

## CONTEXTE

Lors de la séance précédante, le branchement du module GSM SIM7000G et de l'ESP32 a été commencé. Malheureusement le pin PWRKEY n'a pas été correctement appréhendé. Et le code n'a pas pu être téléversé correctement. Dans cette séance, je vais trouver les explications et recherches nécessaires vont être données pour aider Dan, de son côté, téléverser le code correctement. 

### 1. Suite du branchement de l'ESP32 avec le module GSM
- UPLOAD du Code, plusieurs bugs empêchaient son fonctionnement on a du vérifier le branchement.

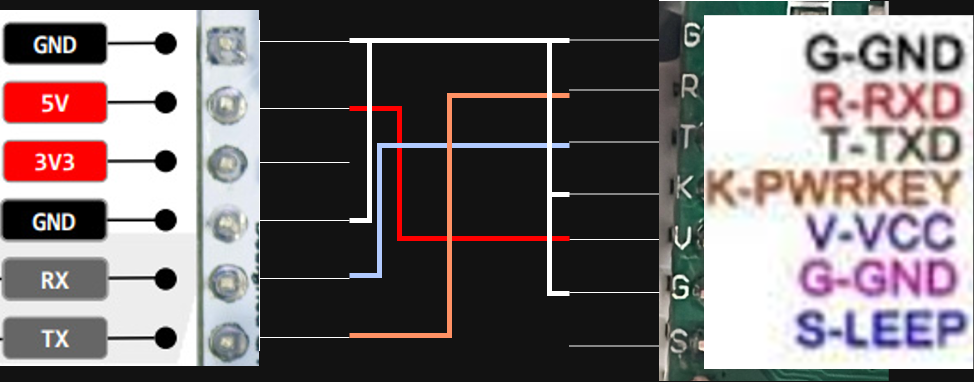
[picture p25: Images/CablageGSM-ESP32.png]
Cablage GSM ESP32


- le PIN PWRKEY du GSM était connecté au port 3V3 de L'ESP. Une fois que sa deconnection le code à finalement bien fonctionné. La raison des problèmes venait de là, il faudra piloter à l'aide d'un pin GPIO de l'ESP le PWRKEY, pour le moment le laisser à 0 au GND suffit afin d'établir une connexion entre GSM ET ESP32.
- le code que upload permet de restart la modem GSM et d'effectuer une lecture des infos de la carte, une fois que tout ça est OK il lui send un msg pour tester le bon reçu. Mais pour le moment il ne fonctionne pas.

PWRKEY PIN GSM
PWRKEY Documentation
- Le PWRKEY est un pin de commande d'alimentation on/off permettant de contrôler en fonction du niveau de tension d'entrée, d'activer le module GSM seulement lorsque son niveau de tension au PWRKEY est en dessous de 0,5 V. Lorsqu'il est au dessus il met OFF le module GSM.

Attention lors de la définition des pin GPIO que l'on définira comme TX et RX, il faut utiliser des GPIO O/I libre. Car les GPIO RX et TX du l'uart0 soit 3 et 4 sont généralement utilisés pour le serial avec le PC. 
Et les deux autres TXD et RDX du UART2 ne peuvent pas être utilisés car OLED_RST sur le Pin 16 du RXD. 
Ainsi 2 GPIO libres ont été choisis, le pin GPIO23 pour TX et GPIO21 pour RX. 

---
### Prochaines étapes à faire lors de la prochaine séance 

1. Cette fois-ci le PWRKEY est compris et correctement cablé. Mais le choix des pins TX / RX de l'ESP32 posent encore problème. Il faudra lors de la prochaine séance trouver une solution à ce conflit.

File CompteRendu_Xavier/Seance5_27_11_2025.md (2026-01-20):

# CR - MIRRIONE Xavier  
## Séance 5 du 27/11/2025  

## CONTEXTE
Lors du précedent cours, en mon absence datant du 12 Novembre 2025, Daniel a avancé sur le code afin de faire fonctionner le module GSM. Celui-ci à bien réussi à envoyer des messages SMS à son portable. Et il a aussi pu se connecter au lien https.

### Recapitulatifs des objectifs
**Objectif 1** : Câblage du module SIM7000G à l'ESP32 Heltec, Vérficiation du code et téléversement. Approfondisement et recherche du module GSM. Réussi ✅

**Objectif 2** : Câblage ESP32 nue et module LoRaCC68-868 pour implémenter une fonctionnalité de réveil de l'ESP32 en utilisant seulement le module LoRa. → En cours ⏸️

**Objectif 3** : Finaliser le système général de la platforme en y intégrant le module SIM7000G pour assurer deux fonctions : l'envoi d'alertes par SMS et la transmission des données LoRa vers le serveur web.

**Objectif Final** : Une fois notre platforme entière de faite et fonctionnelle, il faudra réflechir à la conception d'un circuit imprimé (PCB). Intégrant l'ensemble des modules (ESP32, LoRa, SIM) pour consolider le système final d'acquisition et de transmission de données. 

## Branchement ESP32 Nue au module LoRa CC68-868 
Procédure de verification pour faire fonctionner le module Lora qui reveillera un ESP32 nue dormant. On doit les connecter et aussi ajouter 2 poussoirs sur une laptop et le module FTD1232 convertisseur Usb vers Com Série entre notre ESP32 et le PC.
Désormais, il faut agencer la disposition, vérifier les pins respectifs pour commencer le cablage.    
Agencement composants
- Mise en place et installation d'Eagle Autodesk. Création d'un hub du nom de : Lora, libre d'accès pour les utilisateurs de ayant le même type d'adresse (etu.univ-cotedazur.fr). La version utilisé est une version d'évaluation pour une durée de 30 jours. L'installation a été compliquée, le logiciel dont nous avons besoin est désormais compris dans un pack général de chez Eagle. Beaucoup de temps perdu, au final ce n'est pas superbe. Pour le moment ce logiciel est mis de côté. 

### Prochaine séance 
- Il faut se concentrer sur le brochage des composants et la recherche des pins et des Datasheet des composants

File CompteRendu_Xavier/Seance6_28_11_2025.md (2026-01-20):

# CR - MIRRIONE Xavier  
## Séance du 28/11/2025  

## CONTEXTE

Cette séance est consacrée à la lecture de la datasheet du module **LoRa CC68-868**, ainsi qu’à l’identification des interfaces nécessaires à son intégration avec le microcontrôleur **ESP32-WROOM-32** et un adaptateur série **FTDI1232**.  
L’objectif est de comprendre le rôle des différentes broches avant toute finalisation du câblage matériel.

## SUITE

### Lecture des broches via la datasheet du Module LoRa CC68-868

Le module **LoRa CC68-868** est un transceiver radio fonctionnant dans la bande ISM 868 MHz.  
L’orientation du composant est indiquée par une flèche présente visible sur sa face supérieure. Cette flèche permet d’identifier la position du **PIN 1**, correspondant à la **masse (GND)**. Cette information est essentielle afin d’éviter toute erreur d’orientation ou de selection d'un pin lors du câblage. 
L’architecture du module repose principalement sur une **interface SPI**, accompagnée de signaux de contrôle et d’interruption.

Schéma général projet

#### Alimentation
- **VCC (pin 13)** : alimentation principale du module, avec une tension nominale de **3,3 V**
- **GND (pins 1, 8 et 10)** : masses du module

#### Interface de communication (SPI)
- **MISO (pin 2)** : sortie SPI du module
- **MOSI (pin 3)** : entrée SPI du module
- **SCK (pin 4)** : horloge SPI
- **NSS (pin 5)** : sélection du périphérique SPI  
  La mise à l’état bas de NSS marque le début de la communication, et le retour à l’état haut marque la fin.

#### Signaux de contrôle
- **NRESET (pin 6)** : réinitialisation matérielle du module
- **BUSY (pin 16)** : indication d’occupation interne du transceiver
- **DIO1 (pin 15) et DIO3 (pin 11)** : broches configurables, généralement utilisées comme lignes d’interruption

#### Broches spécifiques RF
- **ANT (pin 9)** : connexion de l’antenne radio (impédance 50 Ω)

À ce stade, la datasheet indique que le module présente une faible consommation en réception et en veille. Cela laisse envisager, pour la suite du projet, l’utilisation d’un mode basse consommation côté ESP32, avec un réveil déclenché par une interruption LoRa (DIO1).

---

### Association des pins LoRa CC68 avec l’ESP32-WROOM-32

Le microcontrôleur **ESP32-WROOM-32** dispose de GPIO compatibles avec les liaisons SPI. Les GPIO6 à GPIO11 (SPI Interne) ne sont pas recommandés pour un usage utilisateur. Il faut donc choisir en HSPI et VSPI.

Pinout ESP32

Les broches suivantes de l’ESP32 sont identifiées comme **compatibles SPI** :
- **GPIO23** : MOSI
- **GPIO19** : MISO
- **GPIO18** : SCK
- **GPIO5**  : CS (NSS)
Les signaux de contrôle du module LoRa (BUSY, DIO1, DIO3, NRESET) seront reliés à des GPIO quelconque de l’ESP32, configurés en entrée ou sortie selon le besoin logiciel.  

---

### Schéma de câblage du bouton poussoir

Un bouton poussoir est utilisé comme interface utilisateur avec l’ESP32.  
Le schéma de câblage repose sur une **résistance de pull-up externe de 100 kΩ**, reliant l’entrée GPIO à la tension **VCC**.

BOUTON SCHEMA

- À l’état repos, l’entrée est maintenue à un niveau logique haut.
- Lors de l’appui, l’entrée est reliée à la **masse (GND)**, ce qui force un niveau logique bas.

Ce type de câblage permet :
- d’éviter les états indéterminés de l’entrée,
- de garantir une lecture fiable de l’état du bouton,
- de simplifier le traitement logiciel côté microcontrôleur.

Ce montage permet d’éviter les états indéterminés et garantit une lecture fiable de l’état du bouton par le microcontrôleur.

---

### Prochaine séance
- Lecture approfondie de la datasheet complète du module LoRa CC68-868.
- Finalisation du câblage entre l’ESP32 et le PC via l’adaptateur série.

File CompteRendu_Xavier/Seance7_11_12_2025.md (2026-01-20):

# CR - MIRRIONE Xavier  
## Séance 7 du 11/12/2025  

## CONTEXTE
Le cablage entre les 3 composants suivant a avancé lors cette séance : 
- Tout d'abord il faut vérifier si la connection et le flash de code est possible entre le micro usb board et l'esp32 nu. 

## SUITE 
### Cablage du Serial adaptateur
Le Serial adaptateur module 5V et 3V3 possède 3 pins à coté du MCU permettant de choisir l'un des deux niveaux de tension, pour cela un petit bloc plastique permet de mettre en d'envoyer par le pin central à VCC ce dont on souhaite utiliser comme niveau de tension, afin de vérifier ça, une sonde oscilloscope va être utilisée.
Comme vous pouvez le remarquer, il y a bien 5V. Pour des réseaux de cybersécurité, la mesure à l'oscilloscope n'a pas été screen via le plug d'une clé usb.
Le module fonctionnera en 3V3 afin d'alimenter nos composants. 
 
Schéma général projet

Schéma général projet

### Cablage du LoRaCC68-868-G
Ce Lora a quelques particularités dont il va falloir approfondir lors du prochain cours ou bien à la maison. Notamment l'antenne 50 Ohms reliée au pin 9, celle-ci sera filaire pour donc 868 MHz. Pour se faire il faut calculer sa longueur d'onde soit Lambda = C / F. Avec c la celerité c = 3.10E8 m/s et F= 868.10E6 Hz. Donc Lambda vaut 0.345m soit 34,5 cm. Nous allons respecter le principe d'adaptation d'impédence à l'aide du principe du quart d'onde comme longueur de l'anntenne filaire, soit 1/4*34,5cm = 8,625 cm. 
Ensuite il y a un autre point dont il faut faire attention au Lore, un condensateur de 10µF + 100 nF est nécesaire entre VCC et GND comme on le voit dans le schéma dans la partie *5.Typical application circuit* de la datasheet.

Schéma général projet

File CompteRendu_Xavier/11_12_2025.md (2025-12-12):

# CR - MIRRIONE Xavier  
## Séance du 27 et 28/11/2025  

## CONTEXTE
Le cablage entre les 3 composants suivant a avancé : 
- Tout d'abord il faut vérifier si la connection et le flash de code est possible entre le micro usb board et l'esp32 nu. 

Brochage des composants et recherche des pins et Datasheet des composants respects : 
Schéma général projet

## SUITE 
### Cablage du Serial adaptateur
Le Serial adaptateur module 5V et 3V3 possède 3 pins à coté du MCU permettant de choisir l'un des deux niveaux de tension, pour cela un petit bloc plastique permet de mettre en d'envoyer par le pin central à VCC ce dont on souhaite utiliser comme niveau de tension, afin de vérifier ça, une sonde oscilloscope va être utilisée.
Comme vous pouvez le remarquer, il y a bien 5V. Pour des réseaux de cybersécurité, la mesure à l'oscilloscope n'a pas été screen via le plug d'une clé usb.
Le module fonctionnera en 3V3 afin d'alimenter nos composants. 
 
Schéma général projet

Schéma général projet

### Cablage du LoRaCC68-868-G
Ce Lora a quelques particularités dont il va falloir approfondir lors du prochain cours ou bien à la maison. Notamment l'antenne 50 Ohms reliée au pin 9, celle-ci sera filaire pour donc 868 MHz. Pour se faire il faut calculer sa longueur d'onde soit Lambda = C / F. Avec c la celerité c = 3.10E8 m/s et F= 868.10E6 Hz. Donc Lambda vaut 0.345m soit 34,5 cm. Nous allons respecter le principe d'adaptation d'impédence à l'aide du principe du quart d'onde comme longueur de l'anntenne filaire, soit 1/4*34,5cm = 8,625 cm. 
Ensuite il y a un autre point dont il faut faire attention au Lore, un condensateur de 10µF + 100 nF est nécesaire entre VCC et GND comme on le voit dans le schéma dans la partie 5. Typical application circuit de la datasheet.

Schéma général projet

---
### Prochaines étapes du projet

1. **Prendre en main la partie LoRa**
   - Vérifier le **bon fonctionnement du module LoRa**.  
   - Reprendre et tester le **code source** fourni par l’équipe précédente.  
   - S’assurer que la communication **en émission et réception** fonctionne correctement.
2. **Prise en main du Module GSM**
    - arriver à envoeyr des messages avec une carte SIM
3. **Rélier Lora en utilisant l'ESP32 pour établier une communication avec le GSM**  
    - Integration LoRA & ESP32
    - Ajout du GSM

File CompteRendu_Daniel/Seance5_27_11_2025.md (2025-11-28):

# 📝 Compte Rendu — CEBAN Daniel  
## Séance du 27/11/2025

---

### Recapitulatifs des objectifs
Objectif 1. Intégration SIM6000 avec le ESP32, connexion à GRSP et envois d'un SMS vers l'utilisateur final → Réussi ✅
Objectif 2. Simuler les donnes & envoyer une requête PHP vers un serveur web (donne par le prof) avec les donnes des ruches. En cours ⏸️ 
Objectif 3. Intégrer LoRa pour récupérer les donnes des ruchers et les envoyer vers l'ESP32 → prochainement ▶️

---

## Objectif de la seance
Simuler les donnes & envoyer une requête PHP vers un serveur web (donne par le prof) avec les donnes des ruches
Lors de la dernière séance on a simule les donnes dans l'arduino IDE 
maitenant on ava faire une requete HTTP pour l'envoier sur le site -> http://rucher.polytech.unice.fr/

---

## Etape 1 -> restructuration du code 
Avant d'ajouter du code on remarque que le code actuel est mal structure et il posse de code mort (partie du code qui n'est jamais atteinte). donc on va restructurer le code avant puis on va rajouter la partie **requete SITE WEB**

1. toute la configuration réseau (mode réseau, mode préféré, CFUN=1) dans setup(). Cela ne doit être fait qu'une seule fois au démarrage, pas à chaque cycle.
**A chaque tour de boucle le modem redemare et essaye de retablir la connexion** on la plutôt endormir le modeme et le reveuiller lorsque'on va envoyer un sms

2. Bloc APN complexe : Le long bloc de code  qui tente de lire et de reconfigurer le AT+CGDCONT? est inutile et fragile. La bibliothèque TinyGsmClient gère cela pour nous lorsqu"on appelez modem.gprsConnect(apn, ...). Je l'ai entièrement supprimé

3. il n'est pas nécessaire de déconnecter le GPRS avant d'envoyer un SMS. Le modem est conçu pour gérer les deux.

---

## Etape 2 -> envoi du requete PHP vers le site 

pour envoier la requete PHP ver le site on utilise le **GPRS** qui est utilisé pour la communication WEB et le IOT

**GPRS** c'est le protocole qui nous permet d'envoyer des requetes sur internet 

**le site HTTP(S)** est le site sur lequel on doit envoyer les donnes qu'on doit se connecter **via une adresse IP que le GPRS nous la donne une fois connecté**

On va utiliser une requete HTTP(S) qui peut être du type
- Post pour envoyer les donnes au serveur 
- Get pour recevoir les donnes du serveur. dans notre cas on peut envisager de recevoir une réponse du serveur une fois toues les donnes récues par le site.

LA SUITE : faire la requete HTTPS et l'envoier via le GPRS vers le site HTTP

```text
GPRS (General Packet Radio Service) utilise le mode commutation de paquets pour la transmission de données Internet.
```
protocolo utilise pour envoier un -> HTTP (Hypertext Transfer Protocol).
Comme vous envoyez des données au serveur (plutôt que d'en demander), la méthode HTTP spécifique que vous utiliserez est POST.

```cpp
void sendDataOverHTTP() {
  Serial.println("--- DÉBUT ENVOI HTTP POST ---");
  simulData(); 
  String payload = serializeData(); // create a JSON
  
  Serial.println("Payload JSON créé :");
  Serial.println(payload);

  Serial.print("Connexion à ");
  Serial.println(server);
  if (client.connect(server, port)) {
      Serial.println("Connecté. Envoi de la requête POST...");

      // Construire et envoyer la requête HTTP POST
      // Assurez-vous que le chemin (le "/" après POST) est correct.
      // Si l'API attend les données sur http://.../api/data, mettez "/api/data"
      client.print(String("POST / HTTP/1.1\r\n")); 
      client.print(String("Host: ") + server + "\r\n");
      client.print("Connection: close\r\n");
      client.print("Content-Type: application/json\r\n");
      client.print(String("Content-Length: ") + payload.length() + "\r\n");
      client.print("\r\n"); // Ligne vide OBLIGATOIRE (fin des en-têtes)
      client.print(payload);   // Envoyer le corps de la requête (votre JSON)

      Serial.println("Requête envoyée.");

      // 4. Attendre et lire la réponse du serveur
      long timeout = millis();
      while (client.available() == 0) {
        if (millis() - timeout > 5000) { // 5 secondes de timeout
          Serial.println(">>> Délai d'attente réponse serveur !");
          client.stop();
          break;
        }
      }
  
      Serial.println("Réponse du serveur :");
      while (client.available()) {
        Serial.write(client.read());
      }

      // 5. Fermer la connexion
      client.stop();
      Serial.println("\nConnexion HTTP fermée.");

  } else {
      Serial.println("Échec de la connexion au serveur HTTP.");
  }

```

---

## Etape 3 -> verif la connection avec le site internet

Lors de l'execution du code on arrive :
1. a se connecteur au site internet.
2. A generer une requete HTTP avec les donnes e envoyer
3. A envoyer et recevoir une réponse du serveur 

- Logs lors de l'envoi du payload vers le serveur
```text
Payload JSON créé :
[{"id":1,"temp":19.00,"weight":21910.50},{"id":2,"temp":4.10,"weight":33897.50},{"id":3,"temp":33.60,"weight":37329.50},{"id":4,"temp":5.00,"weight":15206.70},{"id":5,"temp":15.70,"weight":28405.30},{"id":6,"temp":15.30,"weight":13753.30},{"id":7,"temp":5.10,"weight":30363.00},{"id":8,"temp":26.10,"weight":28850.40},{"id":9,"temp":36.80,"weight":25943.30},{"id":10,"temp":5.70,"weight":18141.20}]
Connexion à rucher.polytech.unice.fr
Connecté. Envoi de la requête POST...
Requête envoyée.
Réponse du serveur :
HTTP/1.1 200 OK
```

```HTTP
  <meta name="msnbot" content="noindex, nofollow">
  <meta name="bingbot" content="noindex, nofollow">
  <title>Ruches connect&eacute;es</title>
  <link rel="stylesheet" href="./amcharts/samples/style.css" type="text/css">
  <script src="./amcharts/amcharts/amcharts.js" type="text/javascript"></script>
  <script src="./amcharts/amcharts/serial.js" type="text/javascript"></script>
  <script src="./amcharts/amcharts/plugins/export/lang/fr.js"></script>
  <script src="./amcharts/amcharts/plugins/dataloader/lang/fr.js"></script>
  <script src="./amcharts/amcharts/lang/fr.js"></script>
  <link rel="stylesheet" type="text/css" href="./include/style1.css" />
</head><body>erreur ruche
```

---

## Conclusion 

**Objectif 2** atteint on arrive bien a envoyer un SMS et une requette HTTP vers un site web avec le donnes des ruches. ✅

Maitenant on va entamer **l'objectif 3** -> intégrer la partie LoRa.

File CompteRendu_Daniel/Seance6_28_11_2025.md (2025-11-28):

# 📝 Compte Rendu — CEBAN Daniel  
## Séance du 28/11/2025

---

### Recapitulatifs des objectifs
**Objectif 1** : Intégrer le module SIM6000 à l'ESP32, établir une connexion GPRS et valider la liaison par l'envoi d'un SMS à l'utilisateur. Réussi ✅

**Objectif 2**. Simuler la collecte de données de ruche (sur l'ESP32) et les transmettre avec succès à un serveur web via une requête HTTP. Réussi ✅

**Objectif 3**. Câbler un ESP32 (sans le module LoRA) et un module LoRa pour implémenter une fonctionnalité de réveil de l'ESP32 en utilisant seulement le module LoRa. → En cours ⏸️

**Objectif 4**. Finaliser le système ESP32/LoRa en y intégrant le module SIM7000G pour assurer deux fonctions : l'envoi d'alertes par SMS et la transmission des données LoRa vers le serveur web.

**Objectif 5**. Concevoir un circuit imprimé (PCB) dédié intégrant l'ensemble des modules (ESP32, LoRa, SIM) pour consolider le système final d'acquisition et de transmission de données. 

---

## Objectif de la seance 
Câbler un ESP32 (sans le module LoRA) et un module LoRa pour implémenter une fonctionnalité de réveil de l'ESP32 en utilisant seulement le module LoRa.

### Liste des modules 

Ajout des composants 

On va utiliser un convertisseur TTL pour communiquer entre le PC et l'ESP32, puis par la suite, on va câbler une communication full-duplex entre le module LoRa et l'ESP32 de sorte que le module LoRa puisse réveiller l'ESP32.

## Etape 1 câblede convertiseur TLL et USP32 

ESP32 WROOM pinout

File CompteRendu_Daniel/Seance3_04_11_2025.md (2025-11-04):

# 📝 Compte Rendu — CEBAN Daniel  
## Séance du 04/11/2025

---

## 🎯 Objectifs de la séance
- Tester le code fourni par l'équipe precedente et vérifier si on arrive à receptioner les messages avec de la carte **ESP32** avec le module **SIM7000G**
- Debuger le code 
- Ameliorer le code existant 

---

## Etapes de la seance 

### Etape 1 : Televersement du code sur la carte ESP32 

Debugger de télecharger le code sur la carte **ESP32 Heltec LoRa**

Le téléversement est le processus qui consiste à compiler le code, le transformer en langage machine, puis à le transférer et l'écrire dans la mémoire flash de l'ESP32.
Une fois cette étape faite, on pourrait démarrer le débogage.

- Lorsqu'on lance le téléchargement, on reçoit une erreur : 

```text
Connecting......................................
A fatal error occurred: Failed to connect to ESP32: Invalid head of packet (0x00): Possible serial noise or corruption.
For troubleshooting steps visit: https://docs.espressif.com/projects/esptool/en/latest/troubleshooting.html
```

Error message ARDUINO IDE  

L'ESP32 doit être mis manuellement en mode flash (ou boot) pour accepter un nouveau programme, bien que de nombreux kits de développement modernes gèrent cela automatiquement via les broches DTR et RTS de l'interface USB-série.
Procédure :

Cliquez sur Téléverser
Attendez que "Connecting..." apparaisse
Maintenez PRG enfoncé
Relâchez PRG lorsque vous voyez des points (....) ou une barre de progression

Même avec cette procédure, on n'arrive pas à télécharger le fichier sur la carte.
On décide alors d'essayer de débrancher tous les câbles de la carte.
Cette fois, le téléversement du code sur la carte **ESP32** non câblée fonctionne.

Updading works ARDUINO IDE 

On décide alors qu'il y a un problème de câblage.
Après une analyse, on décide de débrancher le câble **PWRKEY** et de retester, car il était connecté au 3,3 V. Alors que d'apèrs le data sheet elle doit être connecte à une tension <0.5V. On a du faire une erreur lors du câblage
Par la suite on va brancher le **PWRKEY** à un GPIO de commande pour pouvoir le piloter numériquement.

Cette fois ça marche : **on arrive à télécharger le programme sur la carte ESP32 câblée**.

---

### Etape 2 : Débogage série et vérification de la communication série

Étapes pour le Débogage Série :

1. Appuyez sur le bouton RST pour redémarrer l'ESP32.
2. Dans l'IDE Arduino, cliquez sur l'icône de la Loupe (en haut à droite) ou allez dans Outils > Moniteur Série.
3. Vérifiez la vitesse : Assurez-vous que la vitesse sélectionnée en bas du Moniteur Série est bien 115200 baud pour correspondre à votre ligne Serial.begin(115200).

on doit voir le programme s'exécuter et afficher les messages que vous avez codés, par exemple :

```text
Initialisation du modem...
```

#### Résultat 

Erreur du rédemarrage du modem lié à la partie code

```text
rst:0x1 (POWERON_RESET),boot:0x17 (SPI_FAST_FLASH_BOOT)
configsip: 0, SPIWP:0xee
clk_drv:0x00,q_drv:0x00,d_drv:0x00,cs0_drv:0x00,hd_drv:0x00,wp_drv:0x00
mode:DIO, clock div:1
load:0x3fff0030,len:4980
load:0x40078000,len:16612
load:0x40080400,len:3480
entry 0x400805b4
Core dump data check failed:
Calculated checksum='00d9289a'
Image checksum='ffffffff'

Patientez...
Initialisation du modem...
ATE0
AT+CFUN=0
Échec du redémarrage du modem, tentative de continuation sans redémarrage
AT+CGMI
AT+CGMM
Nom du modem : SIMCom SIM7000
ATI
Infos modem : 
AT+CPIN?
```

on cerchant dans le code on trouve la configuration des broches qu'on doit adapter à la nouvelle carte. La le groupe d'avant ont utilisé un autre carte . 

```text
#define UART_BAUD   115200
#define PIN_DTR     25
#define PIN_TX      20
#define PIN_RX      19
#define PWR_KEY     4
```

### Explication RT TX
Initialement on a prevu d'utiliser les pins **GPIO3** et **GPIO1** pour communiquer en sérier 
cependant ce deux pins sont utiliser pour la communication du **EPS32** avec le pc pour le téchechargement des donnes donc on va utiliser d'autres pourt 

on se propose utiliser le pins **21** et **23**

📌 Rôle de PWR_KEY
Pour le modem SIM7000, le rôle de cette broche est de contrôler l'alimentation ou le cycle de réinitialisation du module modem :

Désignation : Le PWR_KEY est destiné à être câblé à la broche PWRKEY du module modem (SIM7000G).

Fonction : Il est utilisé pour envoyer l'impulsion de démarrage ou d'arrêt (l'équivalent d'appuyer et de maintenir le bouton d'alimentation) au modem.

Ancien Câblage : Dans la configuration que vous avez trouvée (avant l'Heltec), la carte ESP32 utilisée précédemment avait désigné le GPIO 4 pour cette tâche.

| Broche de la Fonction | Ancienne Définition (Code) | Nouvelle Définition (Heltec WiFi LoRa 32) |
|---|---|---|
| TX (ESP32 -> SIM7000) | PIN_TX 20 | **PIN_TX 23** |
| RX (SIM7000 -> ESP32) | PIN_RX 11 | **PIN_RX 21** |
| Contrôle d'Alimentation | PWR_PIN 4 | **PWR_PIN 13** |
| Vitesse de Communication | UART_BAUD 115200 | **UART_BAUD 115200** |

#### Resultat
Avec cette config on n'arrive non plus a établier une communication serie ESP32 et module GSM. on va donc procede à l'analyse du code et modification...

---

### Etape 3 correction du code

Quelques modification dans le code actuel : 

Redémarrage du modem
```	
if (!modem.restart()) { Serial.println("Échec du redémarrage du modem..."); } 
```

on va utiliser plutôt

```
modem.init();
```
Car modem.restart(); envoie un AT+CFUN=1,1 qui est plus invasif. modem.init() est souvent plus fiable pour initialiser la connexion AT après un cycle de démarrage physique.

#### Resultat 
Même erreur -> possible problème -> mouvais câblage

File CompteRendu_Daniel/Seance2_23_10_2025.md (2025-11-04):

# 📝 Compte Rendu — CEBAN Daniel  
## Séance du 23/10/2025

---

## 🔧 Outils utilisés
- **ESP32 Heltec LoRa** – Microcontrôleur principal du système.  
- **SIM7000G** – Module GSM / NB-IoT / LTE pour la communication mobile.  
- **Arduino IDE** – Logiciel de programmation pour cartes électroniques, utilisé pour programmer l’ESP32.

---

## 🎯 Objectifs de la séance
- Connecter le module **ESP32** au module **SIM7000G** et établir la communication entre les deux avec le code fourni par l’équipe précédente.  
- Tester et améliorer le code existant.  
- Comprendre le fonctionnement des bibliothèques utilisées et optimiser l’usage du modem.

---

## ⚡ Étapes de la séance

### 1. Câblage ESP32 ↔ SIM7000G
Il est essentiel de bien connecter les broches **RX/TX** entre l’ESP32 et le module SIM7000G.  
> ⚠️ Sur le module BK-SIM7000G, les connexions RX et TX doivent être inversées par rapport à l’ESP32 (principe de communication série).  

Le **PWRKEY** du SIM7000G doit également être connecté pour permettre l’allumage et l’extinction du module.

D'après le DATASHEET du 7000G

PWRKEY 
- Default status : DI,P
- Description :System power on/off control nput, active low. The efficient input level must be below 0.5V.
- Comment - The level is 0.8V when this PIN is floating; 

Explication : 
Par défaut, le PWRKEY est considéré HIGH lorsqu’il n’est pas connecté (flottant). Le module reste éteint.
Pour allumer le module, il faut tirer la broche LOW (~0 V) pendant ~1 seconde, puis la relâcher (retour à HIGH).
Pour l’éteindre, même principe : on met LOW pendant ~1 seconde.

le SIM7000G a une résistance internet qui permet d'avor un tension petite <0.5V à la broche PWRKEY

Donc on va le brancher à la broche 3,3 pour pouvoir agir dessus

par la suite dans notre code on va afaire démarrer le modem en utlisant le PWRKEY en lui donnat une impulsion pendant 300ms

```
pinMode(PWR_PIN, OUTPUT);
digitalWrite(PWR_PIN, HIGH);
delay(300);
digitalWrite(PWR_PIN, LOW);
```

ESP32 pins layout  
SIM7000G pins explication

Notre montage câble

---

### 2. Importation et compréhension du code dans Arduino IDE
Le code fourni par l’équipe précédente utilise la bibliothèque **TinyGSM**, qui simplifie grandement la communication avec le modem.  

#### La bibliothèque TinyGSM
- Permet d’établir des connexions GPRS / LTE.  
- Permet l’envoi et la réception de SMS.  
- Permet de passer des appels (selon le module).  
- Optimisée pour les cartes à faible mémoire comme l’ESP32.  

#### Structure du code
a. **Configuration et initialisation du modem**
```
#define TINY_GSM_MODEM_SIM7000
#define TINY_GSM_RX_BUFFER 1024
#define SerialAT Serial1
#define DUMP_AT_COMMANDS
#define GSM_PIN ""
#define SMS_TARGET "+33645218132"
```
b. **parametre réseau** 
```
const char apn[] = "sl2sfr";
const char gprsUser[] = "";
const char gprsPass[] = "";
```
c. **Initialisation du modem**
```
SerialAT.begin(UART_BAUD, SERIAL_8N1, PIN_RX, PIN_TX);
modem.restart(); // redémarrage du modem pour assurer un état propre
```
d. **Choix des modes réseau** 
```
modem.sendAT("+CFUN=0");      // Désactive temporairement le modem
modem.setNetworkMode(2);      // Mode automatique
modem.setPreferredMode(1);    // Priorité au mode CAT-M
modem.sendAT("+CFUN=1");      // Réactive le modem
```
e. **Connexion GPRS et envoi de SMS**
```
modem.gprsConnect(apn, gprsUser, gprsPass);
modem.sendSMS(SMS_TARGET, String("Hello from ") + imei);
```
f. **Mode sommeil profond**
```
modem.poweroff();
esp_deep_sleep_start();
```
Permet d’éteindre le modem et mettre l’ESP32 en sommeil pour économiser l’énergie.

---

### 3. Téléchargement et test du code

- Importation du code dans Arduino IDE.
- Installer les bibliotheques necessaires
- Identification du port serie pour la communication avec module

- Programmer l’ESP32 et tester la communication avec le SIM7000G.

---

### 4. Analyse et correction du code

Identifier les erreurs ou parties à améliorer.

TO BE CONTINUED...

---

### Conclusion

La bibliothèque TinyGSM est essentielle pour simplifier la communication UART avec le SIM7000G.

Le câblage RX/TX et PWRKEY est crucial pour le bon fonctionnement du module.

La mise en sommeil profond permet d’économiser l’énergie lors des phases d’inactivité.

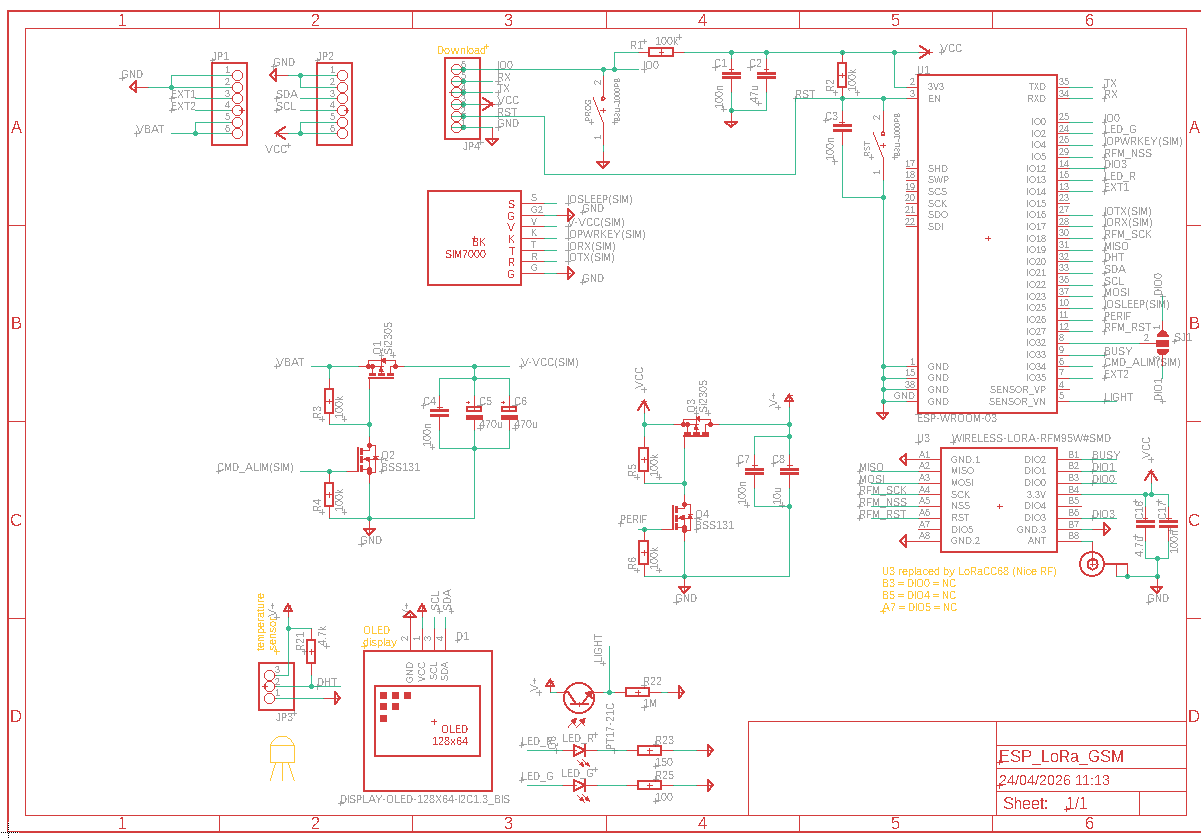
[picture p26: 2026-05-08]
Images/SchematicFinal.png

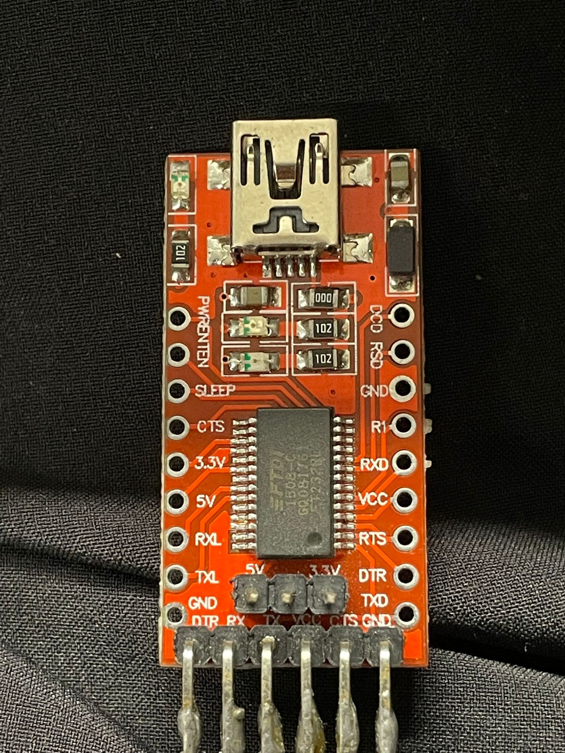
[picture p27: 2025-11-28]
Images/PINComSériePC.jpg

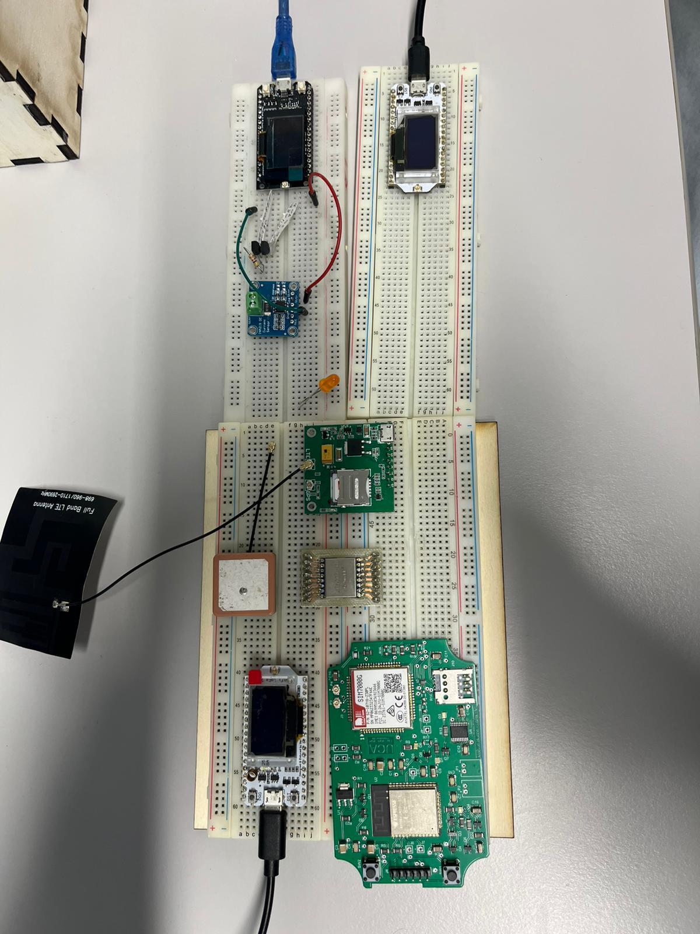
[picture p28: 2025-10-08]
Images/composants.jpeg

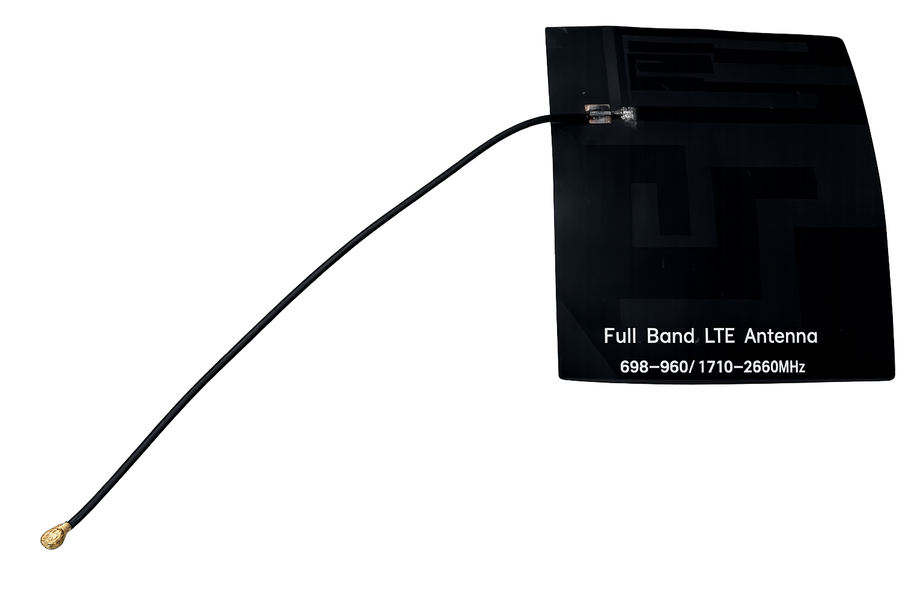
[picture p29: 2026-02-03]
Images/AntenneLTE.png

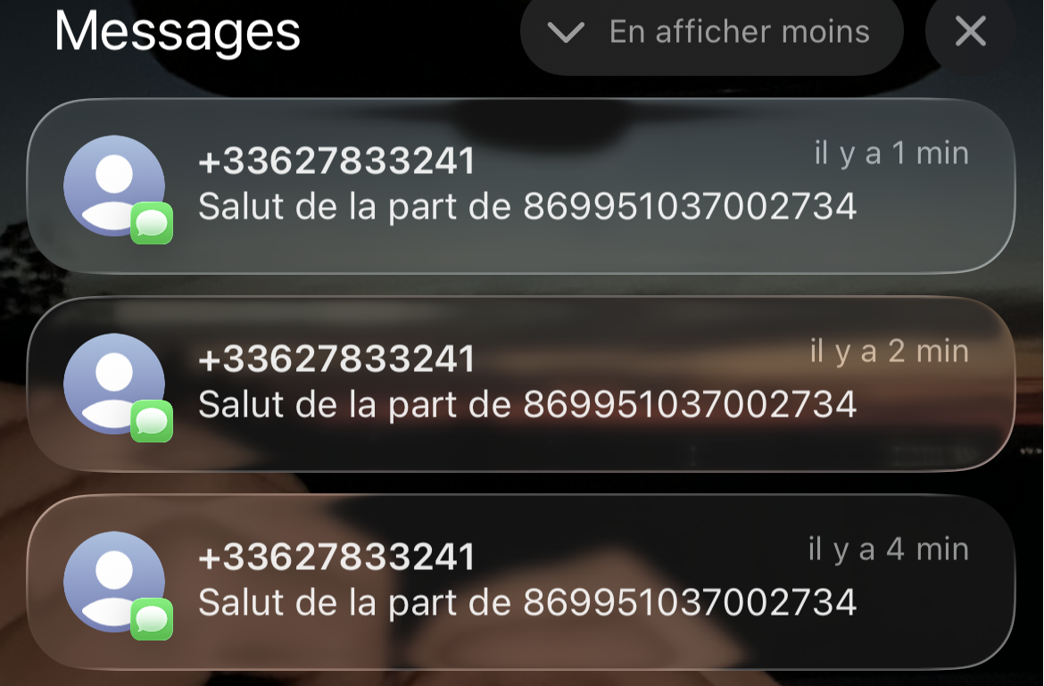
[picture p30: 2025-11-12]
Images/ReceptionMessage.png

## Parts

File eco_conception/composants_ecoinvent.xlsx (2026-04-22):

Bloc / Carte | Désignation projet | Ecoinvent : alt-name | Ecoinvent : name | Ecoinvent : categorie | Quantité | Masse/Surface unitaire | Unité
ESP32 WROOM | Circuit imprimé | pcb 6 layers | market for printed wiring board, for surface mounting, Pb free surface | pcb | 1 | 0.007171 | square meter
ESP32 WROOM | Montage CMS PCB | pcb mounting | market for mounting, surface mount technology, Pb-free solder | pcb | 1 | 0.007171 | square meter
ESP32 WROOM | MicrocontrÃ´leur principal (ESP32) | ic qfn-40 | market for wafer, fabricated, for integrated circuit | ic | 1 | 2.5e-05 | square meter
ESP32 WROOM | Mémoire Flash (SPI) | ic soic-8 | market for integrated circuit, logic type | ic | 1 | 0.00108 | kilogram
ESP32 WROOM | Oscillateur Quartz | crystal | market for integrated circuit, logic type | ic | 1 | 0.0006 | kilogram
ESP32 WROOM | Condensateurs de découplage | capacitor 0402 | market for capacitor, for surface-mounting | passive-component | 15 | 0.00037 | kilogram
ESP32 WROOM | Résistances pull-up/down | resistor 0402 | market for resistor, surface-mounted | passive-component | 10 | 9.945e-05 | kilogram
Module GSM SIM7000G | Circuit imprimé (PCB) | pcb 6 layers | market for printed wiring board, for surface mounting, Pb free surface | pcb | 1 | 0.007171 | square meter
Module GSM SIM7000G | Montage CMS PCB | pcb mounting | market for mounting, surface mount technology, Pb-free solder | pcb | 1 | 0.007171 | square meter
Module GSM SIM7000G | Modem Cellulaire (SIM7000G) | mpu tfbga-361 | market for wafer, fabricated, for integrated circuit | ic | 1 | 0.000144 | square meter
Module GSM SIM7000G | Connecteur Antenne (U.FL/SMA) | socket smd | market for electric connector, peripheral component interconnect buss | peripherial | 2 | 0.000573 | kilogram
Module GSM SIM7000G | Condensateurs de filtrage (Tantale) | capacitor tantal 1206 | market for capacitor, tantalum-, for through-hole mounting | passive-component | 4 | 1.62e-05 | kilogram
Module GSM SIM7000G | Support carte SIM (Nano/Micro) | sd card connector | market for electric connector, peripheral type buss | peripherial | 1 | 0.001 | kilogram
Module GSM SIM7000G | Diode de protection ESD | ic esd sot-23-3 | market for integrated circuit, logic type | ic | 2 | 1.74e-05 | kilogram
Module GSM SIM7000G | Régulateur de tension / LDO | transistor smd | market for transistor, surface-mounted | passive-component | 1 | 6e-05 | kilogram
Module GSM SIM7000G | Self pour convertisseur DC/DC | inductor 1008 | market for inductor, low value multilayer chip | passive-component | 1 | 0.000112 | kilogram
Module LoRa LLCC68 | Circuit imprimé (PCB) | pcb 6 layers | market for printed wiring board, for surface mounting, Pb free surface | pcb | 1 | 0.007171 | square meter
Module LoRa LLCC68 | Montage CMS PCB | pcb mounting | market for mounting, surface mount technology, Pb-free solder | pcb | 1 | 0.007171 | square meter
Module LoRa LLCC68 | Transceiver LoRa | ic qfn-24 | market for wafer, fabricated, for integrated circuit | ic | 1 | 1.6e-05 | square meter
Module LoRa LLCC68 | Oscillateur Quartz | crystal | market for integrated circuit, logic type | ic | 1 | 0.0006 | kilogram
Module LoRa LLCC68 | Pin header de connexion | header | market for electric connector, peripheral component interconnect buss | peripherial | 8 | 0.0007128 | kilogram
Module LoRa LLCC68 | Inductances d'adaptation RF | inductor 0402 | market for inductor, low value multilayer chip | passive-component | 4 | 1e-06 | kilogram
Cartes | Connecteur d'Alimentation | usb c | market for electric connector, peripheral type buss | peripherial | 1 | 0.002248 | kilogram
Cartes | Bouton poussoir (Reset / Boot) | button | market for switch, toggle type | passive-component | 2 | 0.004 | kilogram
Cartes | LEDs d'indicateur d'état | led 0603 | market for diode, glass-, for surface-mounting | passive-component | 3 | 8e-05 | kilogram
Cartes | Résistances pour LEDs | resistor 0603 | market for resistor, surface-mounted | passive-component | 3 | 4.2e-05 | kilogram
Batterie | Lithium-ion |  |  |  | 1 | 0.02 | kilogram
Boîtier |  |  | ABS plastic |  | 1 | 0.15 | kilogram
Antennes |  |  |  |  | 1 | 0.03 | kilogram
Énergie |  |  |  |  | 1 | 87.6 | kWh/5 ans
 |  |  |  |  |  | 0.601 | mAh/h
 |  |  |  |  |  | 1,5 à 2 mAh par heure

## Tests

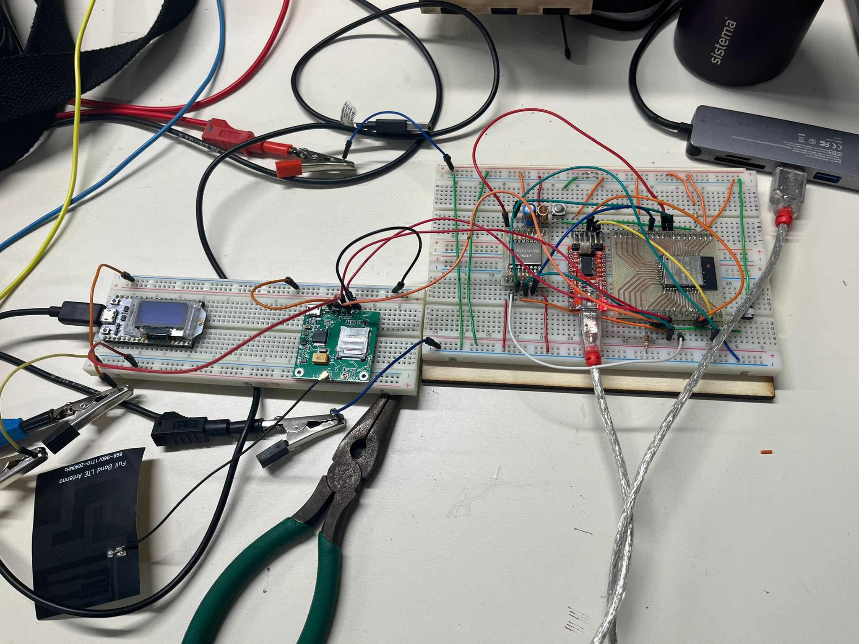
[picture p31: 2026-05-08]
Images/seance18/testChaineComplete.jpeg

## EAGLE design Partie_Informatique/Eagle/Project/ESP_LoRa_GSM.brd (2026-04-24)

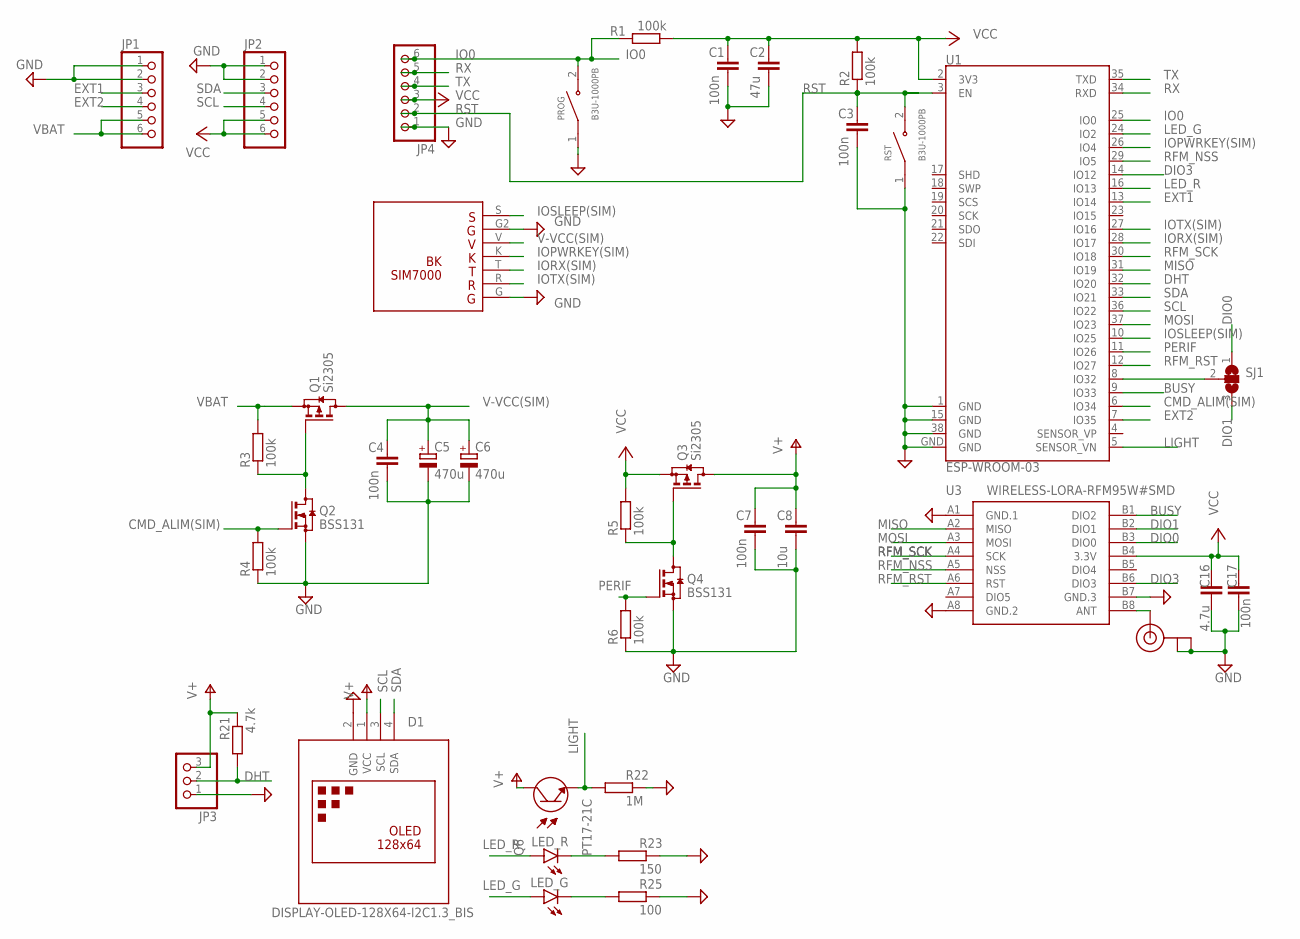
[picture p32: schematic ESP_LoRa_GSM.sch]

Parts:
C1, C3, C4, C7, C17: 100n; C1206
C2: 47u; C0805
C5, C6: 470u; CT7343
C8: 10u; C1206
C16: 4.7u; C1210
D1: DISPLAY-OLED-128X64-I2C1.3_BIS; DISPLAY-OLED-128X64-1.3-I2C_BIS
J1: U.FL
JP1, JP2, JP4: PINHD-1X6S; 1X06S
JP3: PINHD-1X3; 1X03
LED_G: LEDSMT1206; 1206
LED_R: LEDSMT1206; 1206
PROG: B3U-1000PB; SW_B3U-1000PB
Q1, Q3: Si2305; SOT23
Q2, Q4: BSS131; SOT23
Q6: PT17-21C; 0805
R1, R2, R3, R4, R5, R6: 100k; R1206
R21: 4.7k; R1206
R22: 1M; R1206
R23: 150; R1206
R25: 100; R1206
RST: B3U-1000PB; SW_B3U-1000PB
SJ1: SJ2W; SJ_2
U1: ESP-WROOM-03
U2: BK7000-V2; SIM7000-BK
U3: WIRELESS-LORA-RFM95W#SMD

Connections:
ANT: J1.3 (SIGNAL), U3.B8 (ANT)
BUSY: U1.9 (IO33), U3.B1 (DIO2)
CMD_ALIM(SIM): Q2.1 (G), R4.2, U1.6 (IO34)
DHT: JP3.2, R21.1, U1.32 (IO20)
DIO0: SJ1.1, U3.B3 (DIO0)
DIO1: SJ1.3, U3.B2 (DIO1)
DIO3: U1.14 (IO12), U3.B6 (DIO3)
EXT1: JP1.3, U1.13 (IO14)
EXT2: JP1.4, U1.7 (IO35)
GND: C1.2, C2.2, C3.2, C4.2, C5.-, C6.-, C7.2, C8.2, C16.2, C17.2, D1.2 (GND), J1.1 (GND), J1.2 (GND), JP1.1, JP1.2, JP2.1, JP2.2, JP3.1, JP4.1, PROG.1, Q2.2 (S), Q4.2 (S), R4.1, R6.1, R22.2, R23.2, R25.2, RST.1, U1.1 (GND), U1.15 (GND), U1.38 (GND), U1.GND, U2.G, U2.G2, U3.A1 (GND.1), U3.A8 (GND.2), U3.B7 (GND.3)
IO0: JP4.6, PROG.2, R1.2, U1.25 (IO0)
IOPWRKEY(SIM): U1.26 (IO4), U2.K
IORX(SIM): U1.28 (IO17), U2.T
IOSLEEP(SIM): U1.10 (IO25), U2.S
IOTX(SIM): U1.27 (IO16), U2.R
LED_G: LED_G.A, U1.24 (IO2)
LED_R: LED_R.A, U1.16 (IO13)
LIGHT: Q6.1 (E), R22.1, U1.5 (SENSOR_VN)
MISO: U1.31 (IO19), U3.A2 (MISO)
MOSI: U1.37 (IO23), U3.A3 (MOSI)
unnamed: Q1.1 (G), Q2.3 (D), R3.1
unnamed: SJ1.2, U1.8 (IO32)
unnamed: LED_R.C, R23.1
unnamed: LED_G.C, R25.1
unnamed: Q3.1 (G), Q4.3 (D), R5.1
PERIF: Q4.1 (G), R6.2, U1.11 (IO26)
RFM_NSS: U1.29 (IO5), U3.A5 (NSS)
RFM_RST: U1.12 (IO27), U3.A6 (RST)
RFM_SCK: U1.30 (IO18), U3.A4 (SCK)
RST: C3.1, JP4.2, R2.1, RST.2, U1.3 (EN)
RX: JP4.5, U1.34 (RXD)
SCL: D1.3 (SCL), JP2.4, U1.36 (IO22)
SDA: D1.4 (SDA), JP2.3, U1.33 (IO21)
TX: JP4.4, U1.35 (TXD)
V+: C7.1, C8.1, D1.1 (VCC), JP3.3, Q3.3 (D), Q6.2 (C), R21.2
V-VCC(SIM): C4.1, C5.+, C6.+, Q1.3 (D), U2.V
VBAT: JP1.5, JP1.6, Q1.2 (S), R3.2
VCC: C1.1, C2.1, C16.1, C17.1, JP2.5, JP2.6, JP4.3, Q3.2 (S), R1.1, R2.2, R5.2, U1.2 (3V3), U3.B4 (3.3V)

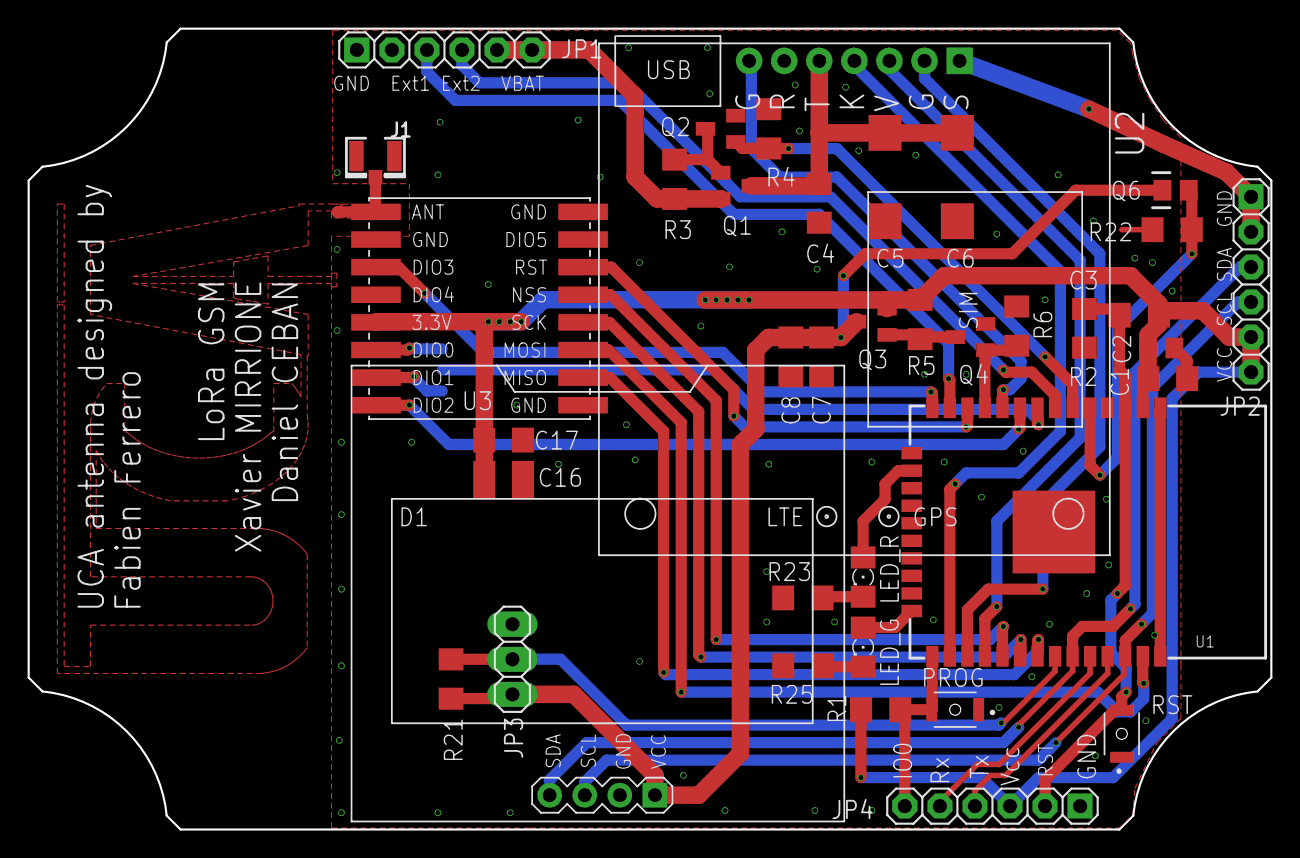
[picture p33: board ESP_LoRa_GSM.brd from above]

Board: 2 copper layers, 90.0 x 58.0 mm, 39 parts (1 on the bottom side), 38 nets.

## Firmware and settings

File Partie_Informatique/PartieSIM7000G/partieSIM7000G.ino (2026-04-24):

#define TINY_GSM_MODEM_SIM7000
#define TINY_GSM_RX_BUFFER 1024 // Définir le tampon RX à 1Ko
#define SerialAT Serial1

//=========Partie traitement donnes ruches==============

// 1. Structure pour représenter les données d'une ruche
struct rucheData {
  int id;
  float temperature;
  float poids;
};
// declaration de nombre total de ruche
const int  nrRuches = 10;
rucheData ruches[nrRuches]; 

//simuler les donnes 
void simulData(){
  for (int i =0; i<nrRuches; i++){
      ruches[i].id = i+1;
      ruches[i].temperature = random(0, 400) / 10.0; // du 0 à 40;
      ruches[i].poids= random(100000, 400000) / 10.0; // du 10kg à 30 kg
  }
}

String serializeData() {
  String payload = "[";
  for (int i = 0; i < nrRuches; i++) {
    payload += "{";
    payload += "\"id\":" + String(ruches[i].id) + ",";
    payload += "\"temp\":" + String(ruches[i].temperature) + ",";
    payload += "\"weight\":" + String(ruches[i].poids);
    payload += "}";
    if (i < nrRuches - 1) {
      payload += ",";
    }
  }
  payload += "]";
  return payload;
}
//======================================================

// Voir toutes les commandes AT, si souhaité
//#define DUMP_AT_COMMANDS

// Définir le code PIN de la carte SIM, si nécessaire
#define GSM_PIN ""

// Vos identifiants GPRS, si vous en avez
const char apn[]  = "sl2sfr";     //DÉFINISSEZ VOTRE APN
const char gprsUser[] = "";
const char gprsPass[] = "";

// Définir un numéro de téléphone pour tester les SMS (doit être au format international avec le "+" devant)
#define SMS_TARGET  "+33634165337" // Nr du Daniel

// --- AJOUTS POUR HTTP ---
const char server[] = "rucher.polytech.unice.fr";
const int port = 80; // Port HTTP standard


#include <TinyGsmClient.h>
//#include <Ticker.h>

#ifdef DUMP_AT_COMMANDS  // si activé, nécessite la lib streamDebugger
  #include <StreamDebugger.h>
  StreamDebugger debugger(SerialAT, Serial);
  TinyGsm modem(debugger);
#else
  TinyGsm modem(SerialAT);
#endif

// --- AJOUT CLIENT HTTP ---
TinyGsmClient client(modem);
// -------------------------


#define uS_TO_S_FACTOR 1000000ULL  // Facteur de conversion de microsecondes en secondes
#define TIME_TO_SLEEP  60          // Durée pendant laquelle l'ESP32 dormira (en secondes)

#define UART_BAUD   115200
//#define PIN_DTR     25
#define PIN_RX      16
#define PIN_TX      17
#define PWR_KEY     4
#define LED_PIN     12


//======================================
//    FONCTION HTTP POST
//======================================
void sendDataOverHTTP() {
  Serial.println("--- DÉBUT ENVOI HTTP POST ---");
  simulData(); 
  String payload = serializeData(); // create a JSON
  
  Serial.println("Payload JSON créé :");
  Serial.println(payload);

  Serial.print("Connexion à ");
  Serial.println(server);
  if (client.connect(server, port)) {
      Serial.println("Connecté. Envoi de la requête POST...");

      // Construire et envoyer la requête HTTP POST
      // Assurez-vous que le chemin (le "/" après POST) est correct.
      // Si l'API attend les données sur http://.../api/data, mettez "/api/data"
      client.print(String("POST / HTTP/1.1\r\n")); 
      client.print(String("Host: ") + server + "\r\n");
      client.print("Connection: close\r\n");
      client.print("Content-Type: application/json\r\n");
      client.print(String("Content-Length: ") + payload.length() + "\r\n");
      client.print("\r\n"); // Ligne vide OBLIGATOIRE (fin des en-têtes)
      client.print(payload);   // Envoyer le corps de la requête (votre JSON)

      Serial.println("Requête envoyée.");

      // 4. Attendre et lire la réponse du serveur
      long timeout = millis();
      while (client.available() == 0) {
        if (millis() - timeout > 5000) { // 5 secondes de timeout
          Serial.println(">>> Délai d'attente réponse serveur !");
          client.stop();
          break;
        }
      }
  
      Serial.println("Réponse du serveur :");
      while (client.available()) {
        Serial.write(client.read());
      }

      // 5. Fermer la connexion
      client.stop();
      Serial.println("\nConnexion HTTP fermée.");

  } else {
      Serial.println("Échec de la connexion au serveur HTTP.");
  }

  Serial.println("--- FIN ENVOI HTTP POST ---");
}


// ==================== SETUUUUUUP =======================
void setup(){
  // Définir le débit en bauds de la console
  Serial.begin(115200);
  delay(10);
  
  // Éteindre la LED
  pinMode(LED_PIN, OUTPUT);
  digitalWrite(LED_PIN, HIGH);

  Serial.println("\nPatientez... Démarrage du modem.");

  // Allumage du modem via PWR_KEY
  pinMode(PWR_KEY, OUTPUT);
  digitalWrite(PWR_KEY, HIGH);
  delay(300);
  digitalWrite(PWR_KEY, LOW);
  
  SerialAT.begin(UART_BAUD, SERIAL_8N1, PIN_RX, PIN_TX);

  // Redémarrer prend un certain temps
  Serial.println("Initialisation du modem...");
  if (!modem.init()) {
    Serial.println("Échec d'initialisation du modem, tentative de continuation sans redémarrage");
  }

  String modemInfo = modem.getModemInfo();
  Serial.println("Infos modem : " + modemInfo);


  // Déverrouillez votre carte SIM avec un PIN si nécessaire
  if ( GSM_PIN && modem.getSimStatus() != 3 ) {
      modem.simUnlock(GSM_PIN);
  }

  // --- CONFIGURATION RÉSEAU (DÉPLACÉE DEPUIS LOOP) ---
  Serial.println("Configuration du mode réseau...");
  
  /*
    2 Automatique
    13 GSM seulement
    38 LTE seulement
    51 GSM et LTE uniquement
  */
  String res;
  res = modem.setNetworkMode(2); // mode automatique
  if (res != "1") {
    DBG("setNetworkMode échoué ");
  }
  delay(200);

  /*
    1 CAT-M
    2 NB-IoT
    3 CAT-M et NB-IoT
  */
  res = modem.setPreferredMode(1); // mode CAT-M
  if (res != "1") {
    DBG("setPreferredMode échoué ");
  }
  delay(200);

  // S'assurer que le modem est en pleine fonctionnalité
  modem.sendAT("+CFUN=1 ");
  if (modem.waitResponse(10000L) != 1) {
    DBG(" +CFUN=1 échoué ");
  }
  
  Serial.println("Configuration modem terminée.");
  // --- FIN CONFIGURATION RÉSEAU ---
}


//====================== LOOOOOOOOOOOP ===========================

void loop(){
  Serial.println("\n\n--- DÉBUT DU CYCLE LOOP ---");

  Serial.println("Attente du réseau...");
  if (!modem.waitForNetwork()) 
  {
    Serial.println("Échec réseau, passage au deep-sleep.");
  }
  else
  {
    Serial.println("Réseau trouvé. Connexion GPRS...");
    
    // Connexion GPRS
    if (!modem.gprsConnect(apn, gprsUser, gprsPass)) 
    {
      Serial.println("Échec de connexion GPRS.");
    } 
    else 
    {
      Serial.println("GPRS Connecté.");

      // -------- 1. ENVOI DES DONNÉES HTTP --------
      sendDataOverHTTP();
      
      // -------- 2. TEST ENVOI SMS --------
      // (Nous avons récupéré l'IMEI au cas où, mais il est préférable de le faire une fois dans setup)
      String imei = modem.getIMEI();
      String res;
      res = modem.sendSMS(SMS_TARGET, String("Project LoRa GSM, sender IMEI: ") + imei);
      DBG("Statut SMS:", res ? "Envoyé" : "Échec");

      // -------- 3. TESTS GPRS (Optionnel mais utile) --------
      Serial.println("\n--- INFOS DIAGNOSTIC GPRS ---");
      String ccid = modem.getSimCCID();
      Serial.println("CCID : " + ccid);
      Serial.println("IMEI : " + imei); // Réutilisation
      String cop = modem.getOperator();
      Serial.println("Opérateur : " + cop);
      IPAddress local = modem.localIP();
      Serial.println("IP locale : " + String(local));
      int csq = modem.getSignalQuality();
      Serial.println("Qualité du signal : " + String(csq));
      Serial.println("--- FIN INFOS GPRS ---");

      // -------- 4. DÉCONNEXION GPRS --------
      modem.gprsDisconnect();
      if (!modem.isGprsConnected()) {
        Serial.println("GPRS déconnecté");
      } else {
        Serial.println("Déconnexion GPRS : Échec");
      }
    }
  }

  // -------- 5. EXTINCTION ET VEILLE --------
  Serial.println("Extinction du modem...");
  modem.poweroff();
  
  Serial.println("Mise en veille profonde de l'ESP32 pour 60 secondes...");
  esp_sleep_enable_timer_wakeup(TIME_TO_SLEEP * uS_TO_S_FACTOR);
  delay(200); // Laisse le temps aux messages série de s'imprimer
  esp_deep_sleep_start();

}

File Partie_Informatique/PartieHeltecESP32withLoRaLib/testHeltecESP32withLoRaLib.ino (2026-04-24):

#include <SPI.h>
#include <LoRa.h>

unsigned long lastTx = 0;
const unsigned long TX_INTERVAL = 5000;   // envoi toutes les x secondes

int txCount = 0;
int rxCount = 0;

void setup() {
  Serial.begin(115200);
  delay(2000);

  Serial.println("\n=== Heltec WiFi LoRa 32 V2.1 - Bidirectionnel ===");

  // Configuration des pins pour Heltec V2.1
  LoRa.setPins(18, 14, 26);     // NSS, RST, DIO0 (IRQ)

  if (!LoRa.begin(868E6)) {     // 868 MHz
    Serial.println("LoRa init FAILED !");
    while (true);
  }

  // Paramètres recommandés (mêmes que tu utilisais avant)
  LoRa.setSpreadingFactor(9);
  LoRa.setSignalBandwidth(125E3);
  LoRa.setCodingRate4(7);
  LoRa.setSyncWord(0x12);
  LoRa.enableCrc();

  Serial.println("LoRa initialized successfully !");
  Serial.println("Envoi toutes les xs + écoute permanente\n");
}

void loop() {
  // ====================== ENVOI ======================
  if (millis() - lastTx >= TX_INTERVAL) {
    lastTx = millis();
    txCount++;


    // envoi du wakup 
    String msgWAKEUP = "Wakeup from Heltec #" + String(txCount) + " - " + String(millis() / 1000) + "s";

    Serial.print("TX #"); Serial.print(txCount); 
    Serial.print(" → "); Serial.println(msgWAKEUP);

    // Envoi du message
    LoRa.beginPacket();
    LoRa.print(msgWAKEUP);
    LoRa.endPacket();
    delay(5000); 

    String msg = "Hello from Heltec #" + String(txCount) + " - " + String(millis() / 1000) + "s";

    Serial.print("TX #"); Serial.print(txCount); 
    Serial.print(" → "); Serial.println(msg);

    // Envoi du message
    LoRa.beginPacket();
    LoRa.print(msg);
    LoRa.endPacket();

    Serial.println("→ Envoi OK");
  }

  // ====================== RÉCEPTION ======================
  int packetSize = LoRa.parsePacket();

  if (packetSize) {
    rxCount++;
    String received = "";

    while (LoRa.available()) {
      received += (char)LoRa.read();
    }

    Serial.println("\n=== RX #" + String(rxCount) + " ===");
    Serial.print("Message reçu : "); Serial.println(received);
    Serial.print("RSSI : "); Serial.print(LoRa.packetRssi()); Serial.println(" dBm");
    Serial.print("SNR  : "); Serial.print(LoRa.packetSnr()); Serial.println(" dB");
    Serial.println("-------------------");
  }

  delay(10);   // petite pause pour ne pas surcharger le CPU
}

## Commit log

2025-10-08 Ajout de cahier de charge et rapport seance du 08
2025-12-11 11_12_2025
    Rédaction rapport et recherche ntenne 50 Ohm pin 9 LoRa et vérification via oscilloscope 3V3 et 5V du Serial adaptateur Board
2025-12-23 Correctif Link Image
    le path des images n'étaient pas correctes
2026-02-03 OubliePush
    Lors de l'oral
2026-02-17 Push-Seance11
    Avancement et explication Schematic Board sous EAGLE
2026-04-10 Seance17-RoutagePCB
    RAS, c'est FINIS
    [top-100-68-shield.brd, top-100-68-shield.sch]
2026-04-24 Seance18
    Ajout dernière version du projet EAGLE.
    [ESP_LoRa_GSM.brd, ESP_LoRa_GSM.sch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]
2026-05-05 Ajout PowerPoint et schematic final

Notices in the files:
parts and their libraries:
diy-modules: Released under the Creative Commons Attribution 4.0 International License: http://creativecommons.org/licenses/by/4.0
